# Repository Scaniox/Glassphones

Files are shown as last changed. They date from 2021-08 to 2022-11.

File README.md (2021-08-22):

# Glassphones

A Bluetooth headset but built into glasses frames; this is V1, so is a bulky experiment

MCU is an esp32 (tinypico nano), programmed using espidf 4.3

codec is a Maxim9850eti+, which is sent audio over i2s and control signals over i2c.
on the same i2s bus (sharing BCLK and LRCLK) is an ics43432 MEMS microphone

audio drivers are tiny bone conduction speakers.

micro SD card using 4 bit SD bus used for secondary storage

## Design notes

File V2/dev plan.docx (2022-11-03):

- hardware
  - Breadboard prototype
    - ~~Uart interface~~
    - Slider input
    - ~~Sd output~~
    - Audio mux
    - Battery
    - Light
    - Indicator disp
    - Test software
      - Sd playing
      - Basic BT playing
      - Audio mixing
      - Slider test
      - Basic slider control
  - Mechanical design
    - Enclosure design
    - Transducer positioning
    - pcb outline
  - Schematic design
  - Pcb layout
    - Layout
    - Routing
    - check
- Software
  - Slider input
  - Menu system
    - Menus
    - Flow diagram
    - User output
  - Sd playing
    - Long file names
  - Bluetooth playing

PCB issues:

- USB D+ and D- swapped; incorrect schematic symbol
- Bm83 VBUS bypass cap not routed
- Cap touch mpr121 vreg capacitor can’t be 0.1uf or only max 4 elements can run at 1ms sample period or 9 at 128ms; all 12 work with 1uf at 16ms, but not 1ms

Hardware abstraction layer (drivers):

- RGB LED driver
  - setup
  - Power management- auto power off
  - Colour patterns
- TOUCH driver
  - Setup - calibration
  - Drift compensation
  - Conversion to slider
  - Power
- Power LED driver
  - Thermal sensing
  - Output - PWM
- VS1053B driver
  - SD IO
  - VS1053 config
  - Power management
  - Audio playing
- BM83 driver
  - Initialisation
  - Events
  - Controls
- System / Misc
  - Battery monitoring
  - Debug LED
  - USB status / Serial

UI system:

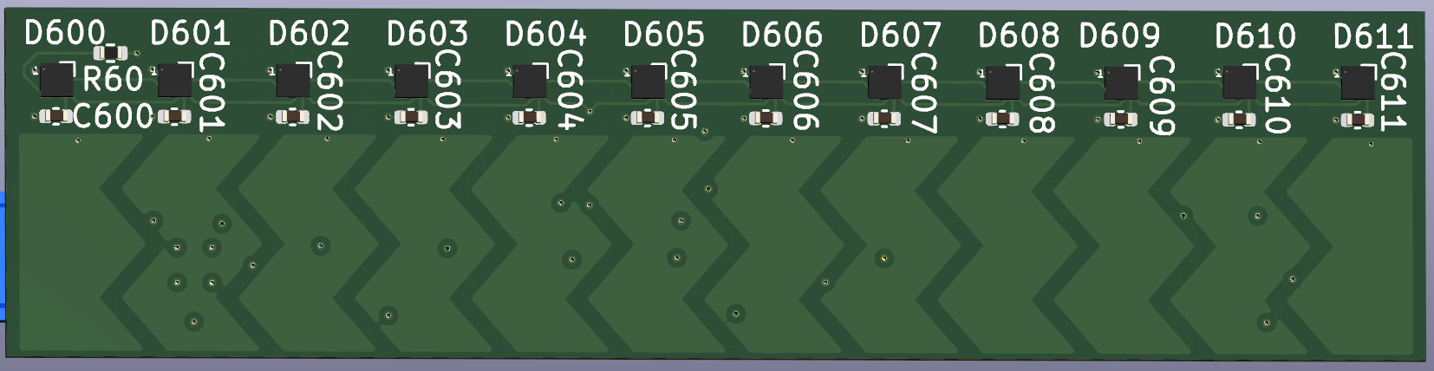
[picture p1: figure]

0 | 1 | 2 | 3 | 4 | 5 | 6 | 7 | 8 | 9 | 10 | 11

Input layers:

Switch between which input events are processed

- Buttons layer:
  - Button:
    - Singular element/ position range triggered
    - Boolean state event
  - Combo buttons:
    - Set pattern of element/ position ranges detected
    - Boolean state event
- Scroll layer:
  - Single scroll
    - One or more digits slides along the sensor.
    - Velocity based – based on touch point velocity not absolute position to prevent jumping between values
    - Value event for delta since [last event, or initial value]

Control scheme:

- Back button on element 0
- Quick access menu
  - Pause
  - Play
  - Seek
  - Volume
- Light shortcut

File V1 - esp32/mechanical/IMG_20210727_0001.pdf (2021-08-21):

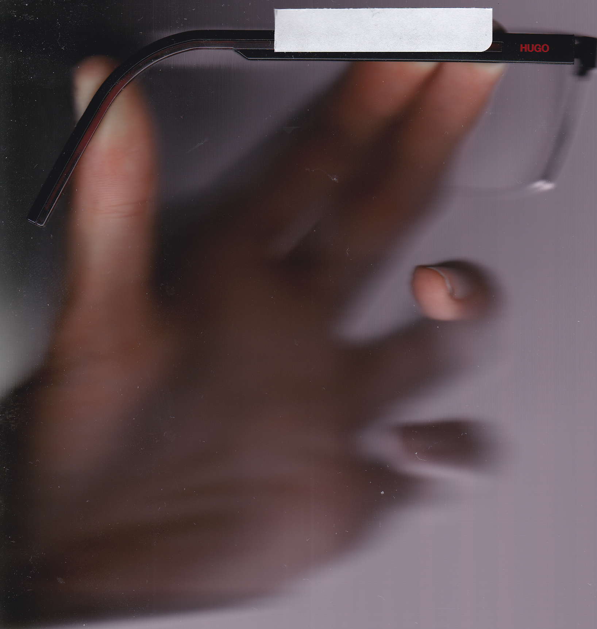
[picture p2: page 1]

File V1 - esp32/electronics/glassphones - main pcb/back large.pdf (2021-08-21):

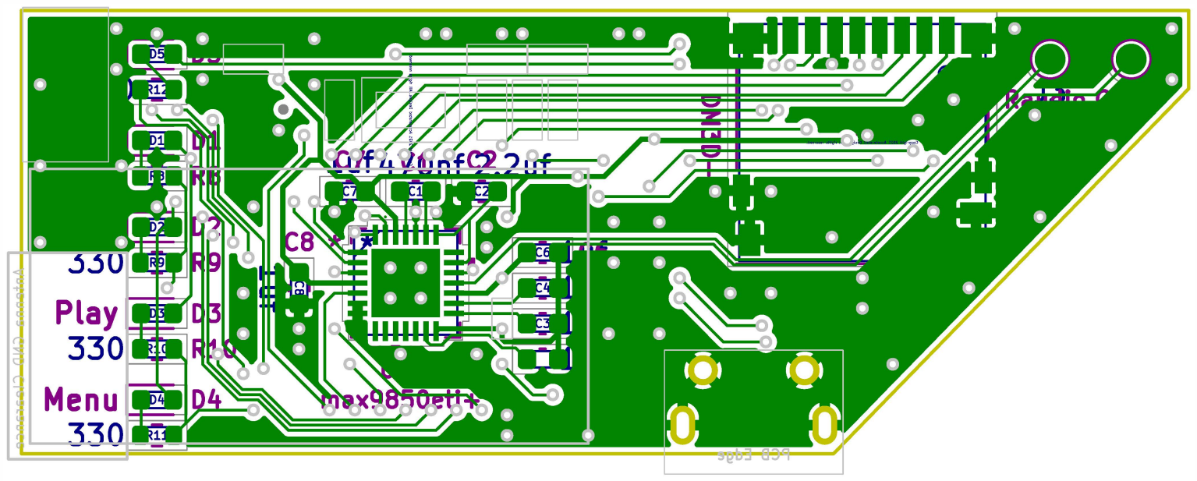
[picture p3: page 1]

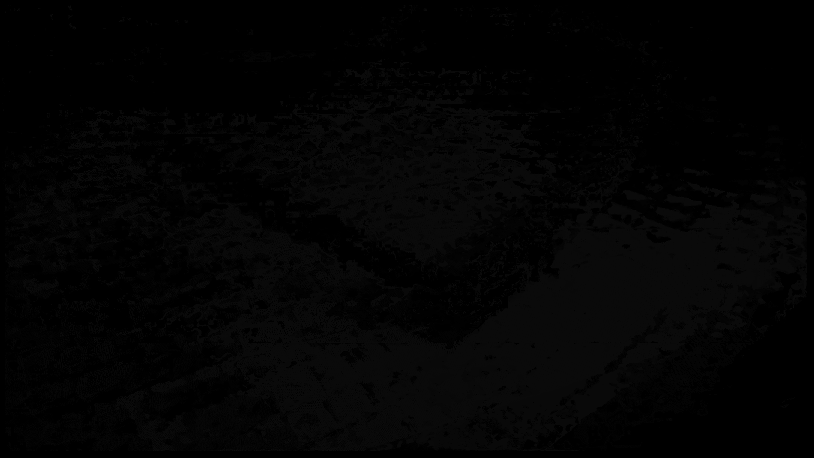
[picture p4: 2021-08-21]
V1 - esp32/mechanical/photogrammetry/photo/MeshroomCache/DepthMapFilter/24b79df3ac3274988167803b87b50ed05e469bb3/1338512535_nmodMap.png

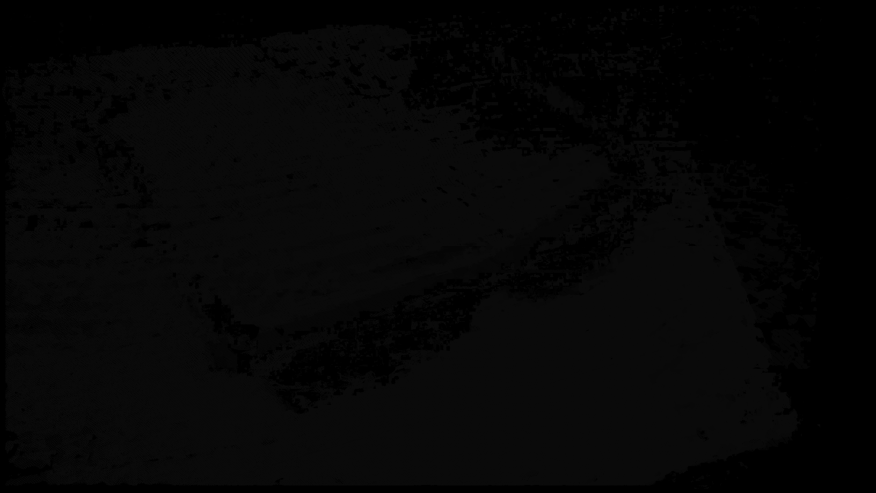
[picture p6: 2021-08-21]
V1 - esp32/mechanical/photogrammetry/photo/MeshroomCache/DepthMapFilter/24b79df3ac3274988167803b87b50ed05e469bb3/1295243340_nmodMap.png

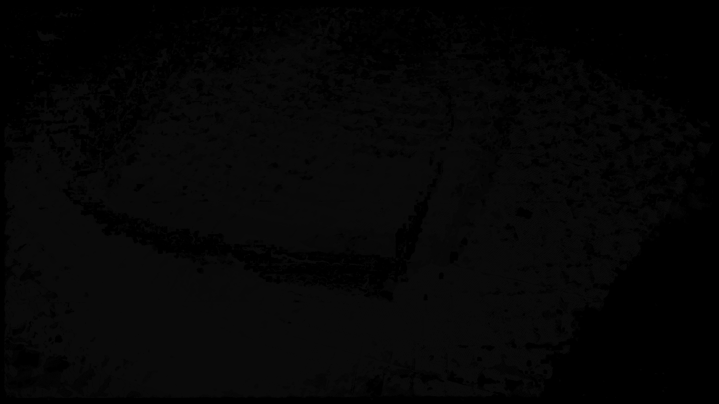
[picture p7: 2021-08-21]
V1 - esp32/mechanical/photogrammetry/photo/MeshroomCache/DepthMapFilter/24b79df3ac3274988167803b87b50ed05e469bb3/1249290596_nmodMap.png

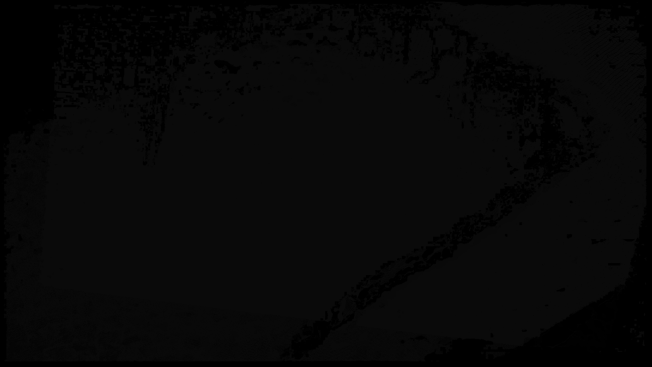
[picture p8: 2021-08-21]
V1 - esp32/mechanical/photogrammetry/photo/MeshroomCache/DepthMapFilter/24b79df3ac3274988167803b87b50ed05e469bb3/1560870966_nmodMap.png

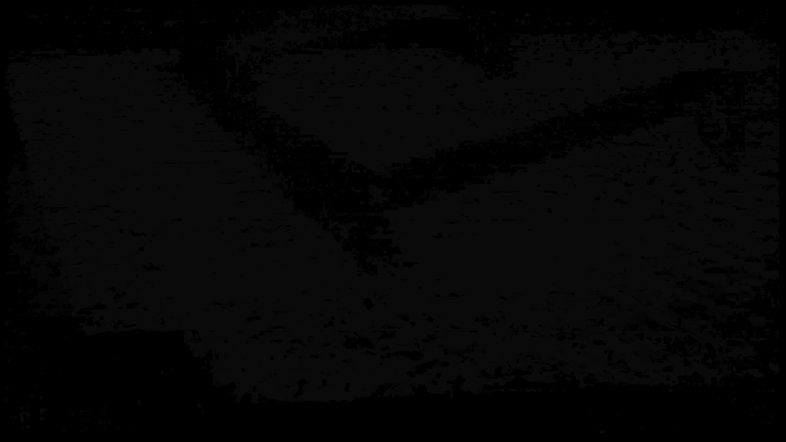
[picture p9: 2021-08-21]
V1 - esp32/mechanical/photogrammetry/photo/MeshroomCache/DepthMapFilter/24b79df3ac3274988167803b87b50ed05e469bb3/498073649_nmodMap.png

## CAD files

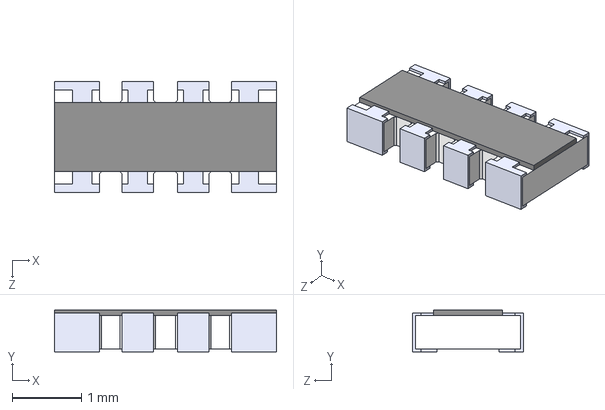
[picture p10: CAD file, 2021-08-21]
V1 - esp32/electronics/glassphones - main pcb/components/4X10k resistor array ul_EXB38V103JV/EXB-38V103JV.step
3.20 x 0.6 x 1.60 mm

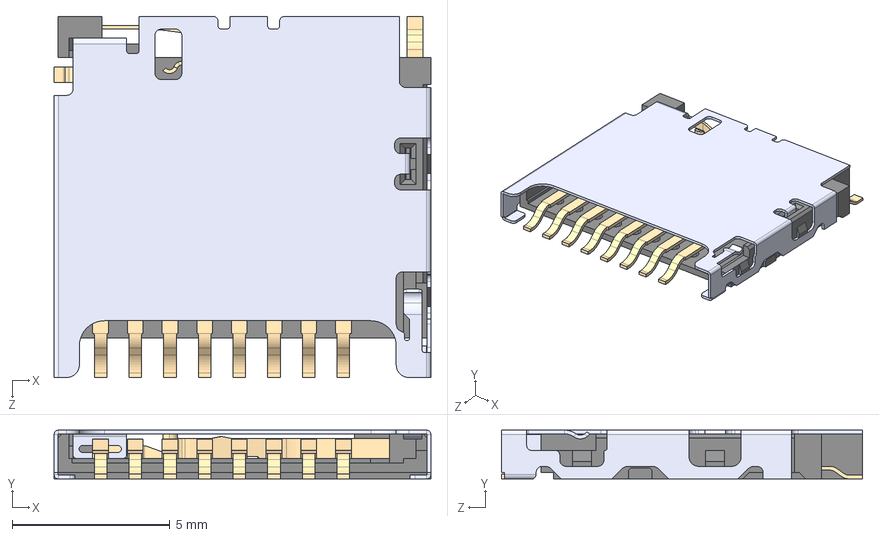
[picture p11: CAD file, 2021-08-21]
V1 - esp32/electronics/glassphones - main pcb/components/DM3DS SD card slot/DM3D-SF--3DModel-STEP-56544.step
12.0 x 1.55 x 11.5 mm

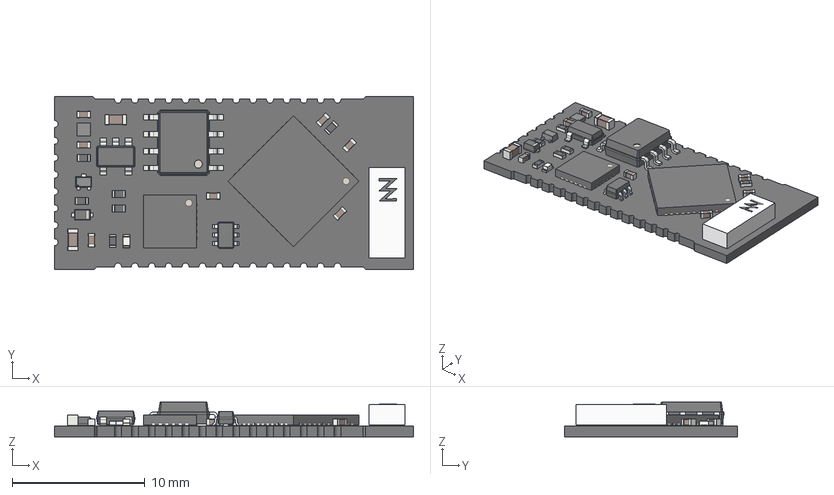
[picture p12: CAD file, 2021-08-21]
V1 - esp32/electronics/glassphones - main pcb/components/esp32 - tinypico/3D Files/TinyPICO Nano.step
27.0 x 13.0 x 2.60 mm

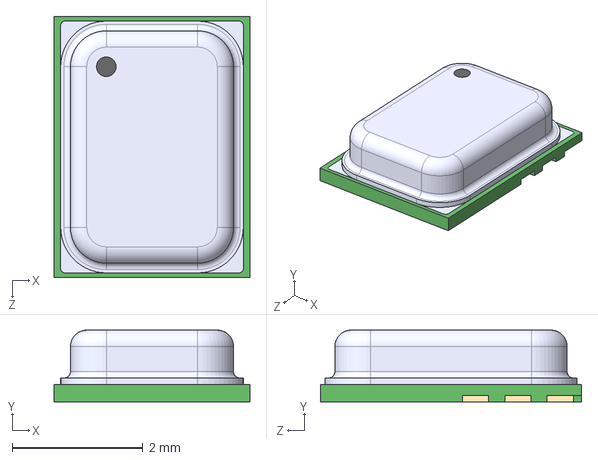
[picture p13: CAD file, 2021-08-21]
V1 - esp32/electronics/glassphones - main pcb/components/ICS 43432 I2S microphone/ICS-43432--3DModel-STEP-56544.step
3.00 x 1.10 x 4.00 mm

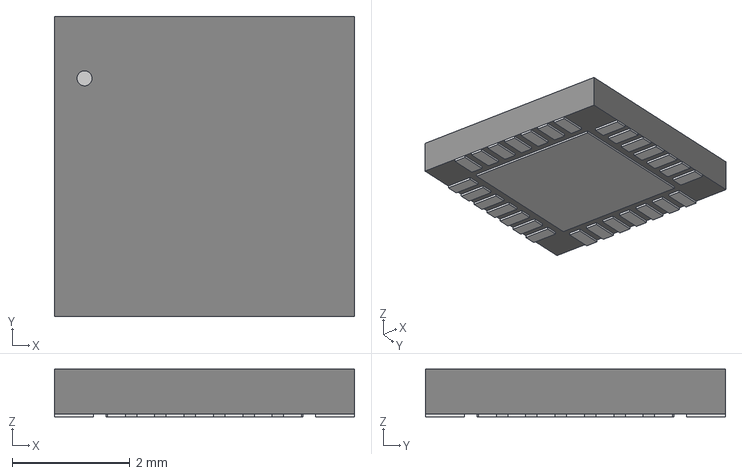
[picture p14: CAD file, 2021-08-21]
V1 - esp32/electronics/glassphones - main pcb/components/MAX9850/21-0140_T28556_MXM.step
5.11 x 5.11 x 0.815 mm

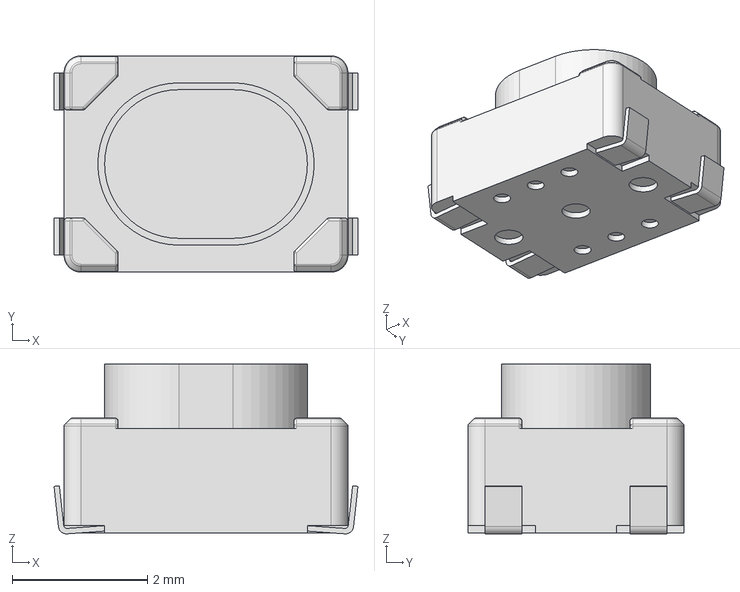
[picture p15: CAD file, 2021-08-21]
V1 - esp32/electronics/glassphones - main pcb/components/TL3365 button/TL3365AF180QG.stp
4.50 x 3.20 x 2.51 mm

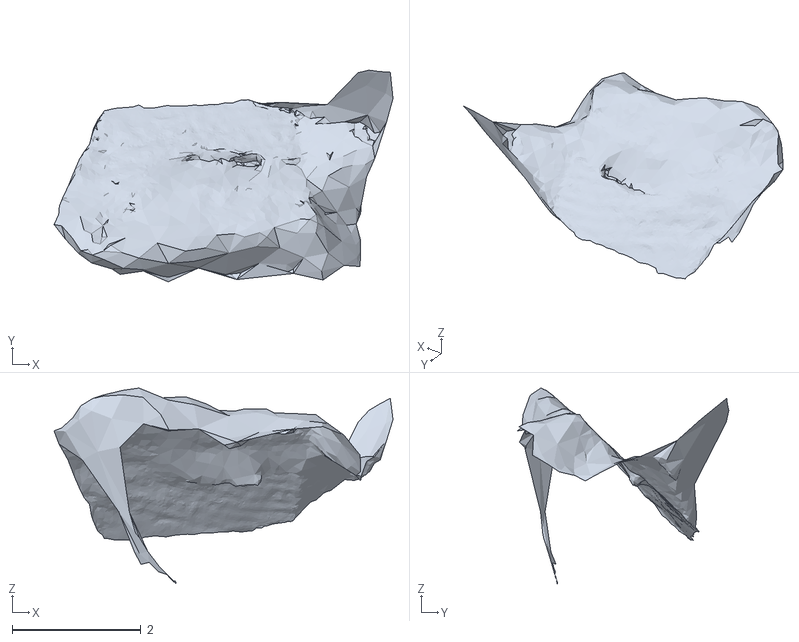
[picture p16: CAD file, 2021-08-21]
V1 - esp32/mechanical/photogrammetry/video/MeshroomCache/MeshFiltering/824bb1fc97e66b3d18760ff6004b31c06b283055/mesh.obj
5.26 x 3.28 x 3.04

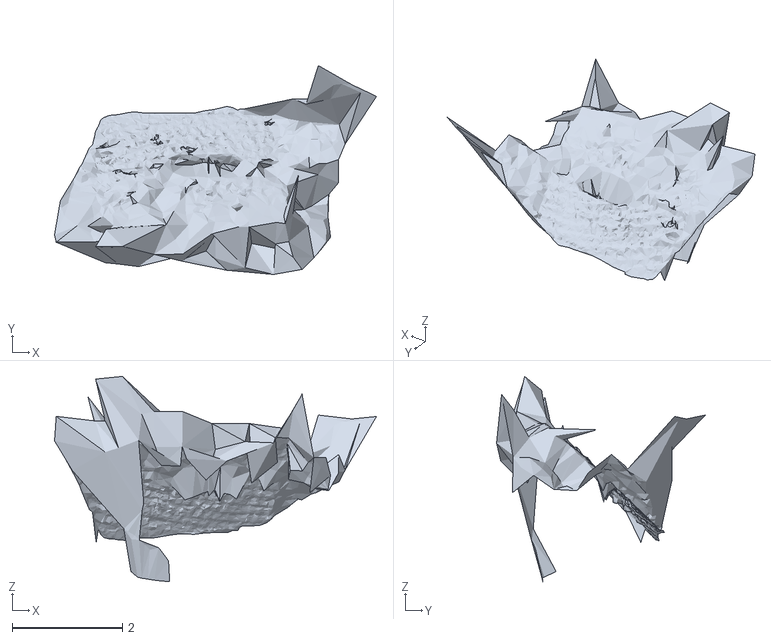
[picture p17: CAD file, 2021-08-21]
V1 - esp32/mechanical/photogrammetry/video/MeshroomCache/Meshing/db83591ce1e8f06cfc1e3cb798bf2ff74a9c68ce/mesh.obj
5.84 x 3.79 x 3.72

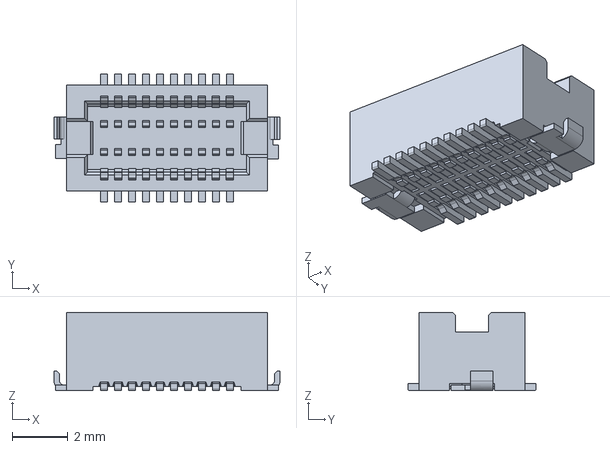
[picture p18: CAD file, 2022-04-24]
V2/electronics/components/df12Nx-20 connector/DF12NB-3.5--20DP-0.5V-51---3DModel-STEP-1.step
8.10 x 4.60 x 2.80 mm

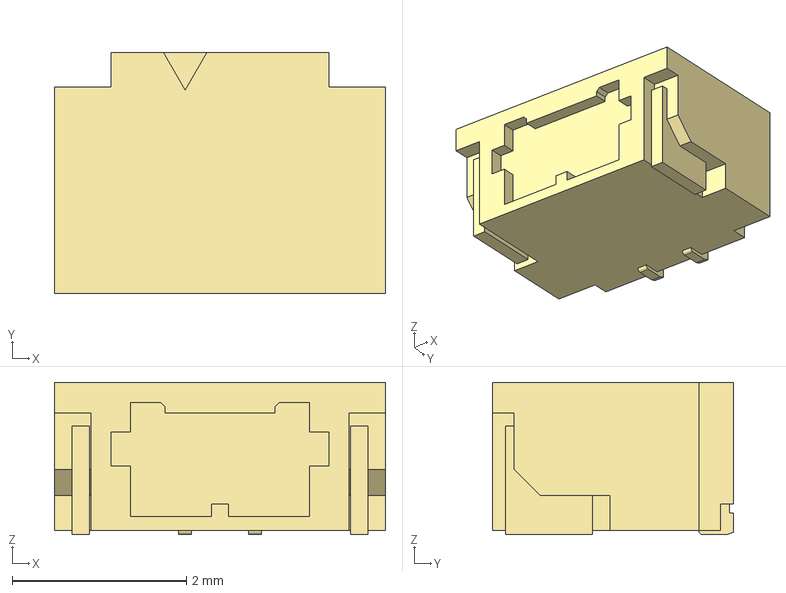
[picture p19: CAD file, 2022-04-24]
V2/electronics/components/df52 conn/DF52-2S-0.8H.stp
3.80 x 2.77 x 1.75 mm

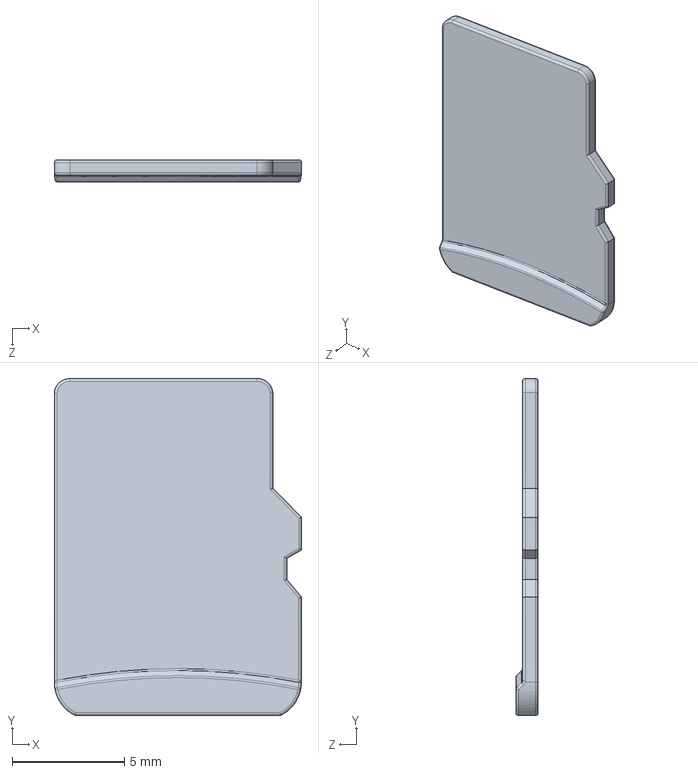
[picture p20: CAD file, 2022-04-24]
V2/electronics/components/Micro SD Card.STEP
11.0 x 15.0 x 1.00 mm

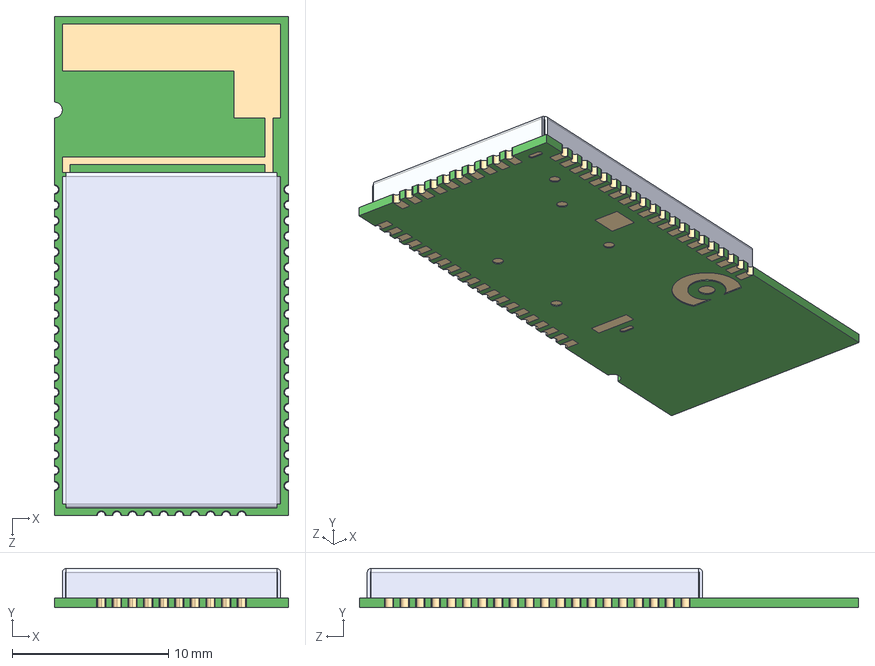
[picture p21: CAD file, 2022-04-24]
V2/electronics/components/Microchip BM83/BM83SM1-00AA--3DModel-STEP-1.step
15.0 x 2.50 x 32.0 mm

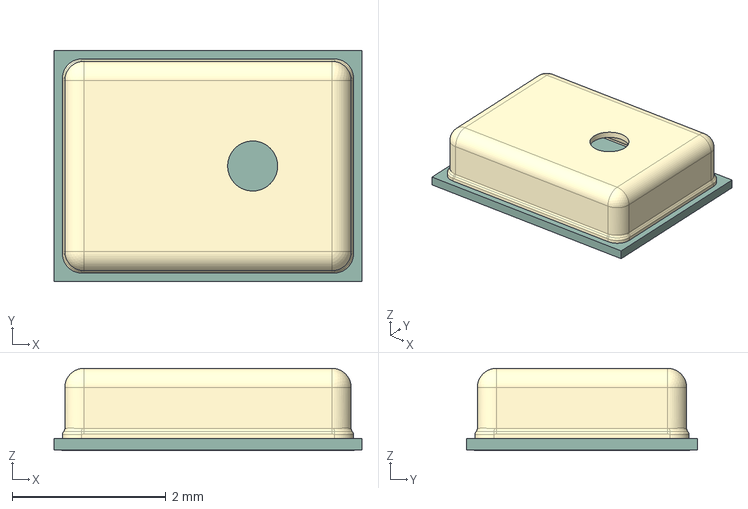
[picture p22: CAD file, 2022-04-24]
V2/electronics/components/MP34DT01TR-M PDM microphone/MP34DT01-M pdm mic v1.step
4.00 x 3.00 x 1.07 mm

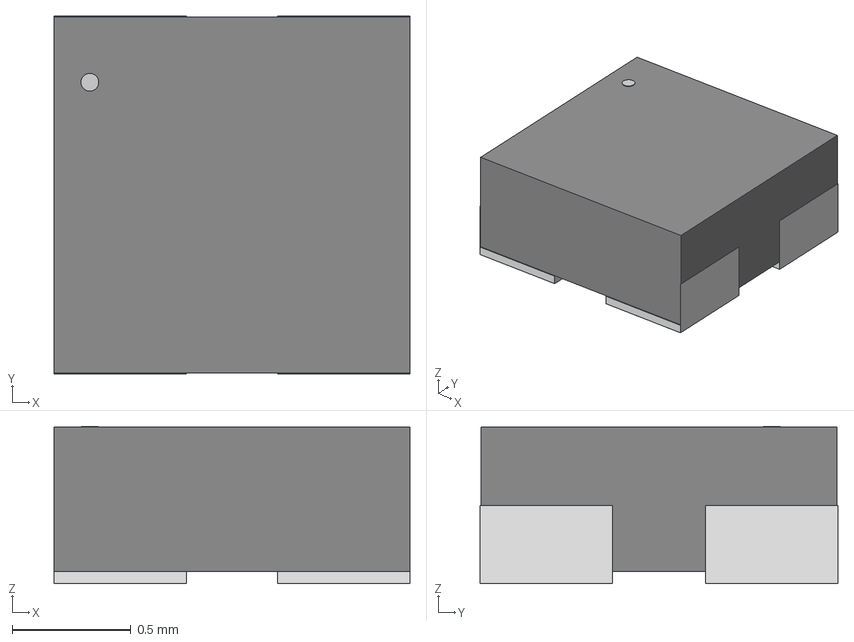
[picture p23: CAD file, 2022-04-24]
V2/electronics/components/sk6805 RGB LED/4492_ADA.step
1.50 x 1.51 x 0.663 mm

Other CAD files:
V2/electronics/main/main.3mf
V1 - esp32/mechanical/photogrammetry/video/MeshroomCache/Texturing/2c468ecf00575808510a90f24e992894a4d70658/texturedMesh.obj
V1 - esp32/electronics/glassphones - main pcb/components/1050170001--3DModel-STEP-56544.step
V1 - esp32/electronics/glassphones - main pcb/components/esp32 - tinypico/3D Files/TinyPICO Nano.stl
V2/electronics/components/0.65mm pogo pin v0.step
V2/electronics/components/df12Nx-20 connector/DF12NC-20DS-0.5V-51---3DModel-STEP-1.step
V2/electronics/components/df52 conn/DF52-4S-0.8H.stp
V2/electronics/components/df52 conn/DF52-5P-0.8C--3DModel-STEP-1.step
V2/electronics/components/df52 conn/DF52-5S-0.8H.stp
V2/electronics/components/ul_max9725aetc-/KiCAD/2022-04-11_15-45-50/MAX9725AETC+.step
V2/mechanical/power-led-1.snapshot.1/Power Led.CATPart
V2/mechanical/power-led-1.snapshot.1/Power Led.igs
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

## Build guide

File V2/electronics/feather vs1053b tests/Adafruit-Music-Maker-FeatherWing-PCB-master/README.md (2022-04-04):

## Adafruit Music Maker FeatherWing PCB

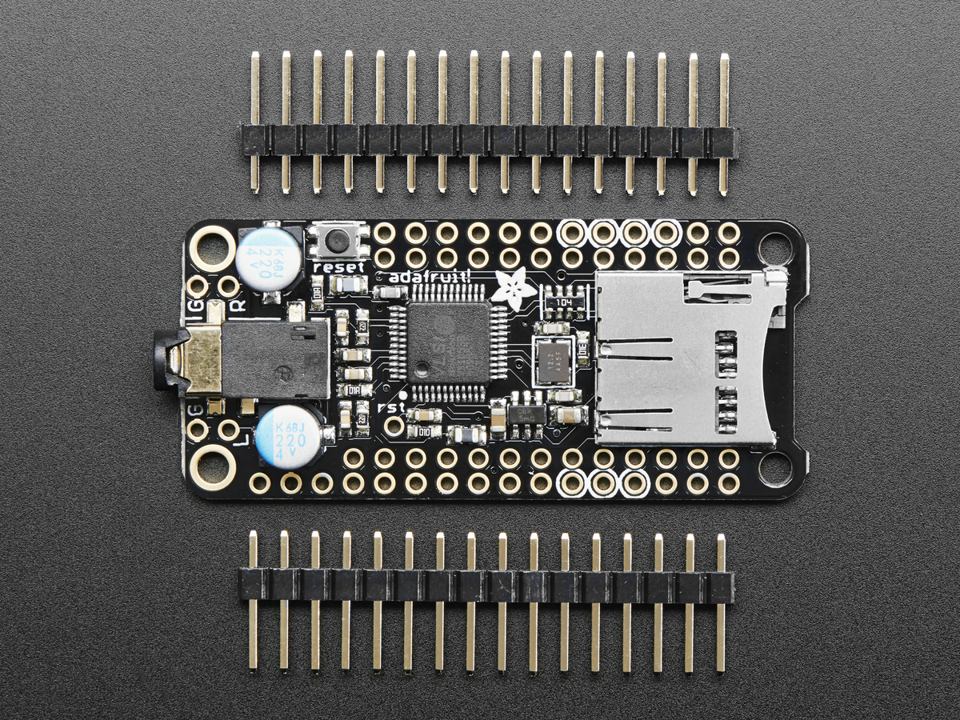
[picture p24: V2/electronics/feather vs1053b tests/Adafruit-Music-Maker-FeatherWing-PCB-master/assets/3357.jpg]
<a href="http://www.adafruit.com/products/3357">&nbsp; 
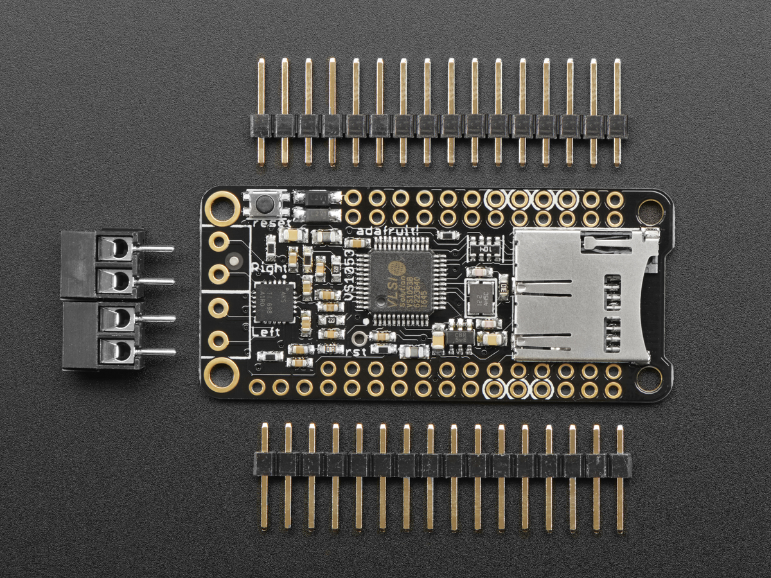
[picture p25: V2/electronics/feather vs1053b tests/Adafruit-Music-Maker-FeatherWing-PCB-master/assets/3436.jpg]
<a href="http://www.adafruit.com/products/3436"><br/>
Click a picture to purchase from the Adafruit shop</a>

PCB files for the Adafruit Music Maker FeatherWings. Format is EagleCAD schematic and board layout

For more details, check out the product pages at
  * Music Maker FeatherWing http://www.adafruit.com/products/3357
  * Music Maker FeatherWing with 3W amp http://www.adafruit.com/products/3436

### Description

Bend all audio files to your will with the Adafruit Music Maker FeatherWings! It's a fun-size version of our Music Maker shield for Arduino! This powerful wing features the VS1053, an encoding/decoding (codec) chip that can decode a wide variety of audio formats such as MP3, AAC, Ogg Vorbis, WMA, MIDI, FLAC, WAV (PCM and ADPCM). You can do all sorts of stuff with the audio as well such as adjusting bass, treble, and volume digitally.

All this functionality is implemented in a light-weight SPI interface so that any Feather Board can play audio from an SD card. There's also a special MIDI mode that you can boot the chip into that will read 'classic' 31250Kbaud MIDI data from the UART TX pin and act like a synth/drum machine - there are dozens of built-in drum and sample effects!

What a great musical add-on to your Feather! That's why we spun up this super FeatherWing, perfect for use with any of our Feather Boards! Music playback testing working with ATmega32u4, ATSAMD M0, ESP8266, WICED Teensy 3, and nRF52 Feathers. MIDI playback works with all Feathers but you may need to remove the 'Wing during programming and also for USB-Serial Feathers like the ESP8266 and nRF52 you'll end up re-using the main Serial console for MIDI which can be confusing.

### License

Adafruit invests time and resources providing this open source design, please support Adafruit and open-source hardware by purchasing products from [Adafruit](https://www.adafruit.com)!

Designed by Limor Fried/Ladyada for Adafruit Industries.

Creative Commons Attribution/Share-Alike, all text above must be included in any redistribution. See license.txt for additional details.

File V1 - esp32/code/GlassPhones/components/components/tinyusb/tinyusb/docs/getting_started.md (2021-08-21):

# Getting Started #

## Add TinyUSB to your project

It is relatively simple to incorporate tinyusb to your (existing) project

- Copy or `git submodule` this repo into your project in a subfolder. Let's say it is *your_project/tinyusb*
- Add all the .c in the `tinyusb/src` folder to your project
- Add *your_project/tinyusb/src* to your include path. Also make sure your current include path also contains the configuration file tusb_config.h.
- Make sure all required macros are all defined properly in tusb_config.h (configure file in demo application is sufficient, but you need to add a few more such as CFG_TUSB_MCU, CFG_TUSB_OS since they are passed by IDE/compiler to maintain a unique configure for all boards).
- If you use the device stack, make sure you have created/modified usb descriptors for your own need. Ultimately you need to implement all **tud_descriptor_** callbacks for the stack to work.
- Add tusb_init() call to your reset initialization code.
- Call `tud_int_handler()` (device stack) and/or `tuh_int_handler()` in your USB IRQ Handler
- Implement all enabled classes's callbacks.
- If you don't use any RTOSes at all, you need to continuously and/or periodically call tud_task()/tuh_task() function. All of the callbacks and functionality are handled and invoke within the call of that task runner.

~~~{.c}
int main(void)
{
  your_init_code();
  tusb_init(); // initialize tinyusb stack

  while(1) // the mainloop
  {
    your_application_code();

    tud_task(); // device task
    tuh_task(); // host task
  }
}
~~~

## Examples

For your convenience, TinyUSB contains a handful of examples for both host and device with/without RTOS to quickly test the functionality as well as demonstrate how API() should be used. Most examples will work on most of [the supported Boards](boards.md). Firstly we need to `git clone` if not already

```
$ git clone https://github.com/hathach/tinyusb tinyusb
$ cd tinyusb
```

TinyUSB examples includes external repos aka submodules to provide low-level MCU peripheral's driver as well as external libraries such as FreeRTOS to compile with. Therefore we will firstly fetch those mcu driver repo by running this command in the top folder repo

```
$ git submodule update --init --recursive
```

It will takes a bit of time due to the number of supported MCUs, luckily we only need to do this once. Or if you only want to test with a specific mcu, you could only fetch its driver submodule.

### Build

To build example, first change directory to an example folder. 

```
$ cd examples/device/cdc_msc
```

Then compile with `make BOARD=[board_name] all`, for example

```
$ make BOARD=feather_nrf52840_express all
```

#### Port Selection

If a board has several ports, one port is chosen by default in the individual board.mk file. Use option `PORT=x` To choose another port. For example to select the HS port of a STM32F746Disco board, use:

```
$ make BOARD=stm32f746disco PORT=1 all
```

#### Port Speed

A MCU can support multiple operational speed. By default, the example build system will use the fastest supported on the board. Use option `SPEED=full/high` e.g To force F723 operate at full instead of default high speed

```
$ make BOARD=stm32f746disco SPEED=full all
```

### Debug

To compile for debugging add `DEBUG=1`, for example

```
$ make BOARD=feather_nrf52840_express DEBUG=1 all
```

#### Log

Should you have an issue running example and/or submitting an bug report. You could enable TinyUSB built-in debug logging with optional `LOG=`. LOG=1 will only print out error message, LOG=2 print more information with on-going events. LOG=3 or higher is not used yet. 

```
$ make BOARD=feather_nrf52840_express LOG=2 all
```

#### Logger

By default log message is printed via on-board UART which is slow and take lots of CPU time comparing to USB speed. If your board support on-board/external debugger, it would be more efficient to use it for logging. There are 2 protocols: 

- `LOGGER=rtt`: use [Segger RTT protocol](https://www.segger.com/products/debug-probes/j-link/technology/about-real-time-transfer/)   
  - Cons: requires jlink as the debugger.
  - Pros: work with most if not all MCUs
  - Software viewer is JLink RTT Viewer/Client/Logger which is bundled with JLink driver package.
- `LOGGER=swo`: Use dedicated SWO pin of ARM Cortex SWD debug header.
  - Cons: only work with ARM Cortex MCUs minus M0
  - Pros: should be compatible with more debugger that support SWO.
  - Software viewer should be provided along with your debugger driver.

```
$ make BOARD=feather_nrf52840_express LOG=2 LOGGER=rtt all
$ make BOARD=feather_nrf52840_express LOG=2 LOGGER=swo all
```

### Flash

`flash` target will use the default on-board debugger (jlink/cmsisdap/stlink/dfu) to flash the binary, please install those support software in advance. Some board use bootloader/DFU via serial which is required to pass to make command

```
$ make BOARD=feather_nrf52840_express flash
$ make SERIAL=/dev/ttyACM0 BOARD=feather_nrf52840_express flash
```

Since jlink can be used with most of the boards, there is also `flash-jlink` target for your convenience.

```
$ make BOARD=feather_nrf52840_express flash-jlink
```

Some board use uf2 bootloader for drag & drop in to mass storage device, uf2 can be generated with `uf2` target

```
$ make BOARD=feather_nrf52840_express all uf2
```

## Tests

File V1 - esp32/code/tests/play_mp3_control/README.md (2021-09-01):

# Play mp3 file with playback control

- [中文版本](./README_CN.md)
- Basic Example: Basic Example

## Example Brief

This example uses MP3 element and I2S element to play embedded MP3 music. The mp3 element call back function `read_cb` read the music data form flash, decode the data then use I2S element output the music.

This example also shows how to control MP3 playback by buttons.

- Playback: start, stop, pause, resume.
- Volume: volume up, volume down.
- Other button: MODE/FUNC button, which is used to switch between audios played at different sample rates.

The three audio files at the sample rate of 8000 Hz, 22050 Hz, and 44100 Hz are embedded in flash.

## Environment Setup

### Hardware Required

This example runs on the boards that are marked with a green checkbox in the table below. Please remember to select the board in menuconfig as discussed in Section *Configuration* below.

| Board Name | Getting Started | Chip | Compatible |
|---|:---:|:---:|:---:|
| ESP32-LyraT | ESP32-LyraT (https://docs.espressif.com/projects/esp-adf/en/latest/get-started/get-started-esp32-lyrat.html) | ESP32 | Compatible |
| ESP32-LyraTD-MSC | ESP32-LyraTD-MSC (https://docs.espressif.com/projects/esp-adf/en/latest/get-started/get-started-esp32-lyratd-msc.html) | ESP32 | Compatible |
| ESP32-LyraT-Mini | ESP32-LyraT-Mini (https://docs.espressif.com/projects/esp-adf/en/latest/get-started/get-started-esp32-lyrat-mini.html) | ESP32 | Compatible |
| ESP32-Korvo-DU1906 | ESP32-Korvo-DU1906 (https://docs.espressif.com/projects/esp-adf/en/latest/get-started/get-started-esp32-korvo-du1906.html) | ESP32 | Compatible |
| ESP32-S2-Kaluga-1 Kit | ESP32-S2-Kaluga-1 Kit (https://docs.espressif.com/projects/esp-idf/en/latest/esp32s2/hw-reference/esp32s2/user-guide-esp32-s2-kaluga-1-kit.html) | ESP32-S2 | Compatible |

## Example Set Up

### Default IDF Branch
The default IDF branch of this example is ADF's built-in branch `$ADF_PATH/esp-idf`.

### Configuration
The default board for this example is `ESP32-Lyrat V4.3`, if you need to run this example on other development boards, you need to select the configuration of the development board in menuconfig, for example, select `ESP32-Lyrat-Mini V1.1`.

```c
menuconfig > Audio HAL > ESP32-Lyrat-Mini V1.1
```

### Build and Flash
Build the project and flash it to the board, then run monitor tool to view serial output (replace `PORT` with your board's serial port name):

```c
idf.py -p PORT flash monitor
```

To exit the serial monitor, type ``Ctrl-]``.

See the Getting Started Guide for full steps to configure and use  [ESP-IDF Programming Guide](https://docs.espressif.com/projects/esp-idf/en/release-v4.2/esp32/index.html) to build projects.

## How to use the Example

### Example Functionality

- After the routine starts to run, it will automatically play the low sample rate (8000 Hz) mp3 file.

```c
I (260) PLAY_FLASH_MP3_CONTROL: [3.1] Initialize keys on board
I (260) PLAY_FLASH_MP3_CONTROL: [ 4 ] Set up  event listener
W (280) PERIPH_TOUCH: _touch_init
I (280) PLAY_FLASH_MP3_CONTROL: [4.1] Listening event from all elements of pipeline
I (290) PLAY_FLASH_MP3_CONTROL: [4.2] Listening event from peripherals
W (290) PLAY_FLASH_MP3_CONTROL: [ 5 ] Tap touch buttons to control music player:
W (300) PLAY_FLASH_MP3_CONTROL:       [Play] to start, pause and resume, [Set] to stop.
W (310) PLAY_FLASH_MP3_CONTROL:       [Vol-] or [Vol+] to adjust volume.
I (330) PLAY_FLASH_MP3_CONTROL: [ 5.1 ] Start audio_pipeline
I (340) PLAY_FLASH_MP3_CONTROL: [ * ] Receive music info from mp3 decoder, sample_rates=8000, bits=16, ch=2
```
- During playback, you can use the [Play] button to pause playback and resume playback.

```c
I (330) PLAY_FLASH_MP3_CONTROL: [ 5.1 ] Start audio_pipeline
I (340) PLAY_FLASH_MP3_CONTROL: [ * ] Receive music info from mp3 decoder, sample_rates=8000, bits=16, ch=2
I (7330) PLAY_FLASH_MP3_CONTROL: [ * ] [Play] touch tap event
I (7330) PLAY_FLASH_MP3_CONTROL: [ * ] Pausing audio pipeline
I (8830) PLAY_FLASH_MP3_CONTROL: [ * ] [Play] touch tap event
I (8830) PLAY_FLASH_MP3_CONTROL: [ * ] Resuming audio pipeline
I (8850) PLAY_FLASH_MP3_CONTROL: [ * ] Receive music info from mp3 decoder, sample_rates=8000, bits=16, ch=2
```

- Use volume down key [Vol-] to decrease the volume, and volume up key [Vol+] to increase the volume.

```c
I (81590) PLAY_FLASH_MP3_CONTROL: [ * ] Receive music info from mp3 decoder, sample_rates=22050, bits=16, ch=2
I (106330) PLAY_FLASH_MP3_CONTROL: [ * ] [Vol+] touch tap event
I (106340) PLAY_FLASH_MP3_CONTROL: [ * ] Volume set to 79 %
```

- Use [Mode] key to switch MP3 playback of different audio file (8000 Hz, 22050 Hz, 44100 Hz).

```c
I (330) PLAY_FLASH_MP3_CONTROL: [ 5.1 ] Start audio_pipeline
I (340) PLAY_FLASH_MP3_CONTROL: [ * ] Receive music info from mp3 decoder, sample_rates=8000, bits=16, ch=2
I (16230) PLAY_FLASH_MP3_CONTROL: [ * ] [mode] tap event
W (16230) AUDIO_ELEMENT: OUT-[mp3] AEL_IO_ABORT
W (16230) MP3_DECODER: output aborted -3
I (16420) PLAY_FLASH_MP3_CONTROL: [ * ] Receive music info from mp3 decoder, sample_rates=22050, bits=16, ch=2
I (19130) PLAY_FLASH_MP3_CONTROL: [ * ] [mode] tap event
W (19130) AUDIO_ELEMENT: OUT-[mp3] AEL_IO_ABORT
W (19130) MP3_DECODER: output aborted -3
I (19190) PLAY_FLASH_MP3_CONTROL: [ * ] Receive music info from mp3 decoder, sample_rates=44100, bits=16, ch=2
I (21440) PLAY_FLASH_MP3_CONTROL: [ * ] [mode] tap event
W (21440) AUDIO_ELEMENT: OUT-[mp3] AEL_IO_ABORT
W (21440) MP3_DECODER: output aborted -3
I (21480) PLAY_FLASH_MP3_CONTROL: [ * ] Receive music info from mp3 decoder, sample_rates=8000, bits=16, ch=2
```

- Use the [Set] key to exit the routine.

```c
I (21480) PLAY_FLASH_MP3_CONTROL: [ * ] Receive music info from mp3 decoder, sample_rates=8000, bits=16, ch=2
I (63580) PLAY_FLASH_MP3_CONTROL: [ * ] [Set] touch tap event
I (63580) PLAY_FLASH_MP3_CONTROL: [ * ] Stopping audio pipeline
I (63580) PLAY_FLASH_MP3_CONTROL: [ 6 ] Stop audio_pipeline
E (63580) AUDIO_ELEMENT: [mp3] Element already stopped
E (63600) AUDIO_ELEMENT: [i2s] Element already stopped
W (63600) AUDIO_PIPELINE: There are no listener registered
W (63600) AUDIO_ELEMENT: [i2s] Element has not create when AUDIO_ELEMENT_TERMINATE
W (63610) AUDIO_ELEMENT: [mp3] Element has not create when AUDIO_ELEMENT_TERMINATE
```

### Example Logs
A complete log is as follows:

```c
rst:0x1 (POWERON_RESET),boot:0x1f (SPI_FAST_FLASH_BOOT)
configsip: 0, SPIWP:0xee
clk_drv:0x00,q_drv:0x00,d_drv:0x00,cs0_drv:0x00,hd_drv:0x00,wp_drv:0x00
mode:DIO, clock div:2
load:0x3fff0018,len:4
load:0x3fff001c,len:6840
load:0x40078000,len:12072
load:0x40080400,len:6708
entry 0x40080778
I (73) boot: Chip Revision: 3
I (73) boot_comm: chip revision: 3, min. bootloader chip revision: 0
I (40) boot: ESP-IDF v3.3.2-107-g722043f73 2nd stage bootloader
I (40) boot: compile time 15:30:10
I (40) boot: Enabling RNG early entropy source...
I (46) boot: SPI Speed      : 40MHz
I (50) boot: SPI Mode       : DIO
I (54) boot: SPI Flash Size : 8MB
I (58) boot: Partition Table:
I (62) boot: ## Label            Usage          Type ST Offset   Length
I (69) boot:  0 nvs              WiFi data        01 02 00009000 00006000
I (76) boot:  1 phy_init         RF data          01 01 0000f000 00001000
I (84) boot:  2 factory          factory app      00 00 00010000 00100000
I (91) boot: End of partition table
I (95) boot_comm: chip revision: 3, min. application chip revision: 0
I (103) esp_image: segment 0: paddr=0x00010020 vaddr=0x3f400020 size=0x8a0d0 (565456) map
I (310) esp_image: segment 1: paddr=0x0009a0f8 vaddr=0x3ffb0000 size=0x01f40 (  8000) load
I (314) esp_image: segment 2: paddr=0x0009c040 vaddr=0x40080000 size=0x00400 (  1024) load
0x40080000: _WindowOverflow4 at /repo/adfs/bugfix/esp-adf-internal/esp-idf/components/freertos/xtensa_vectors.S:1779

I (317) esp_image: segment 3: paddr=0x0009c448 vaddr=0x40080400 size=0x03bc8 ( 15304) load
I (332) esp_image: segment 4: paddr=0x000a0018 vaddr=0x400d0018 size=0x26a64 (158308) map
0x400d0018: _flash_cache_start at ??:?

I (390) esp_image: segment 5: paddr=0x000c6a84 vaddr=0x40083fc8 size=0x06994 ( 27028) load
0x40083fc8: i2c_master_cmd_begin_static at /repo/adfs/bugfix/esp-adf-internal/esp-idf/components/driver/i2c.c:1134

I (408) boot: Loaded app from partition at offset 0x10000
I (408) boot: Disabling RNG early entropy source...
I (409) cpu_start: Pro cpu up.
I (412) cpu_start: Application information:
I (417) cpu_start: Project name:     play_mp3_control
I (423) cpu_start: App version:      v2.2-85-gf9fa5c94-dirty
I (429) cpu_start: Compile time:     Apr 27 2021 17:11:15
I (435) cpu_start: ELF file SHA256:  87bfd7bdac8a9d70...
I (441) cpu_start: ESP-IDF:          v3.3.2-107-g722043f73
I (447) cpu_start: Starting app cpu, entry point is 0x40081078
0x40081078: call_start_cpu1 at /repo/adfs/bugfix/esp-adf-internal/esp-idf/components/esp32/cpu_start.c:268

I (0) cpu_start: App cpu up.
I (458) heap_init: Initializing. RAM available for dynamic allocation:
I (465) heap_init: At 3FFAE6E0 len 00001920 (6 KiB): DRAM
I (471) heap_init: At 3FFB2FE0 len 0002D020 (180 KiB): DRAM
I (477) heap_init: At 3FFE0440 len 00003AE0 (14 KiB): D/IRAM
I (483) heap_init: At 3FFE4350 len 0001BCB0 (111 KiB): D/IRAM
I (490) heap_init: At 4008A95C len 000156A4 (85 KiB): IRAM
I (496) cpu_start: Pro cpu start user code
I (179) cpu_start: Starting scheduler on PRO CPU.
I (0) cpu_start: Starting scheduler on APP CPU.
I (180) PLAY_FLASH_MP3_CONTROL: [ 1 ] Start audio codec chip
I (200) PLAY_FLASH_MP3_CONTROL: [ 2 ] Create audio pipeline, add all elements to pipeline, and subscribe pipeline event
I (200) PLAY_FLASH_MP3_CONTROL: [2.1] Create mp3 decoder to decode mp3 file and set custom read callback
I (220) PLAY_FLASH_MP3_CONTROL: [2.2] Create i2s stream to write data to codec chip
I (230) PLAY_FLASH_MP3_CONTROL: [2.3] Register all elements to audio pipeline
I (230) PLAY_FLASH_MP3_CONTROL: [2.4] Link it together [mp3_music_read_cb]-->mp3_decoder-->i2s_stream-->[codec_chip]
I (240) PLAY_FLASH_MP3_CONTROL: [ 3 ] Initialize peripherals
E (250) gpio: gpio_install_isr_service(412): GPIO isr service already installed
I (260) PLAY_FLASH_MP3_CONTROL: [3.1] Initialize keys on board
I (260) PLAY_FLASH_MP3_CONTROL: [ 4 ] Set up  event listener
W (280) PERIPH_TOUCH: _touch_init
I (280) PLAY_FLASH_MP3_CONTROL: [4.1] Listening event from all elements of pipeline
I (290) PLAY_FLASH_MP3_CONTROL: [4.2] Listening event from peripherals
W (290) PLAY_FLASH_MP3_CONTROL: [ 5 ] Tap touch buttons to control music player:
W (300) PLAY_FLASH_MP3_CONTROL:       [Play] to start, pause and resume, [Set] to stop.
W (310) PLAY_FLASH_MP3_CONTROL:       [Vol-] or [Vol+] to adjust volume.
I (330) PLAY_FLASH_MP3_CONTROL: [ 5.1 ] Start audio_pipeline
I (340) PLAY_FLASH_MP3_CONTROL: [ * ] Receive music info from mp3 decoder, sample_rates=8000, bits=16, ch=2
I (7330) PLAY_FLASH_MP3_CONTROL: [ * ] [Play] touch tap event
I (7330) PLAY_FLASH_MP3_CONTROL: [ * ] Pausing audio pipeline
I (8830) PLAY_FLASH_MP3_CONTROL: [ * ] [Play] touch tap event
I (8830) PLAY_FLASH_MP3_CONTROL: [ * ] Resuming audio pipeline
I (8850) PLAY_FLASH_MP3_CONTROL: [ * ] Receive music info from mp3 decoder, sample_rates=8000, bits=16, ch=2
I (86830) PLAY_FLASH_MP3_CONTROL: [ * ] [Vol+] touch tap event
I (86830) PLAY_FLASH_MP3_CONTROL: [ * ] Volume set to 79 %
I (90590) PLAY_FLASH_MP3_CONTROL: [ * ] [mode] tap event
E (90590) AUDIO_ELEMENT: [mp3] Element already stopped
E (90590) AUDIO_ELEMENT: [i2s] Element already stopped
I (90610) PLAY_FLASH_MP3_CONTROL: [ * ] Receive music info from mp3 decoder, sample_rates=22050, bits=16, ch=2
I (92470) PLAY_FLASH_MP3_CONTROL: [ * ] [mode] tap event
W (92470) AUDIO_ELEMENT: OUT-[mp3] AEL_IO_ABORT
W (92470) MP3_DECODER: output aborted -3
I (92540) PLAY_FLASH_MP3_CONTROL: [ * ] Receive music info from mp3 decoder, sample_rates=44100, bits=16, ch=2
I (94940) PLAY_FLASH_MP3_CONTROL: [ * ] [mode] tap event
W (94940) AUDIO_ELEMENT: OUT-[mp3] AEL_IO_ABORT
W (94940) MP3_DECODER: output aborted -3
W (94940) AUDIO_ELEMENT: IN-[i2s] AEL_IO_ABORT
I (95000) PLAY_FLASH_MP3_CONTROL: [ * ] Receive music info from mp3 decoder, sample_rates=8000, bits=16, ch=2
I (96670) PLAY_FLASH_MP3_CONTROL: [ * ] [mode] tap event
W (96670) AUDIO_ELEMENT: OUT-[mp3] AEL_IO_ABORT
W (96670) MP3_DECODER: output aborted -3
I (96810) PLAY_FLASH_MP3_CONTROL: [ * ] Receive music info from mp3 decoder, sample_rates=22050, bits=16, ch=2
I (101680) PLAY_FLASH_MP3_CONTROL: [ * ] [Set] touch tap event
I (101680) PLAY_FLASH_MP3_CONTROL: [ * ] Stopping audio pipeline
I (101680) PLAY_FLASH_MP3_CONTROL: [ 6 ] Stop audio_pipeline
W (101690) AUDIO_ELEMENT: OUT-[mp3] AEL_IO_ABORT
W (101690) MP3_DECODER: output aborted -3
W (101760) AUDIO_PIPELINE: There are no listener registered
W (101760) AUDIO_ELEMENT: [i2s] Element has not create when AUDIO_ELEMENT_TERMINATE
W (101760) AUDIO_ELEMENT: [mp3] Element has not create when AUDIO_ELEMENT_TERMINATE
```

## Technical support and feedback

Please use the following feedback channels:

* For technical queries, go to the [esp32.com](https://esp32.com/viewforum.php?f=20) forum
* For a feature request or bug report, create a [GitHub issue](https://github.com/espressif/esp-adf/issues)

We will get back to you as soon as possible.

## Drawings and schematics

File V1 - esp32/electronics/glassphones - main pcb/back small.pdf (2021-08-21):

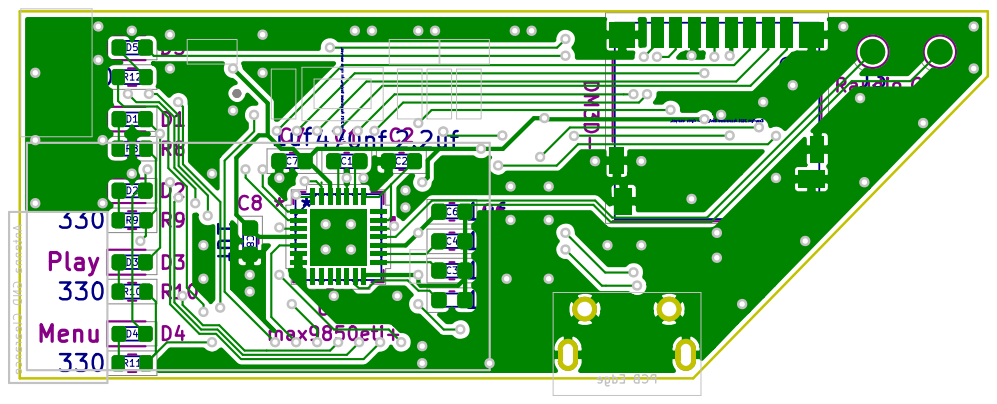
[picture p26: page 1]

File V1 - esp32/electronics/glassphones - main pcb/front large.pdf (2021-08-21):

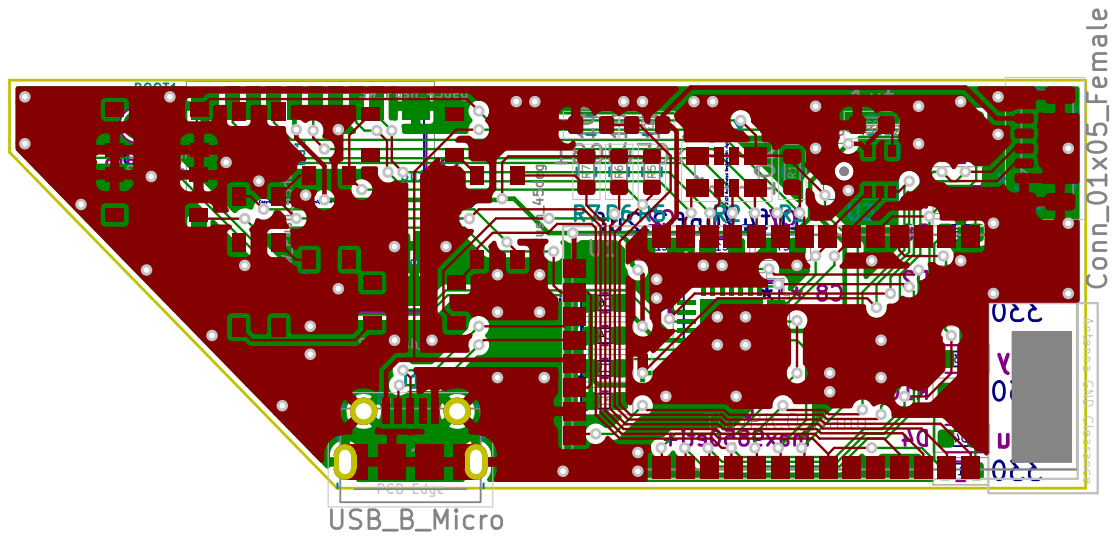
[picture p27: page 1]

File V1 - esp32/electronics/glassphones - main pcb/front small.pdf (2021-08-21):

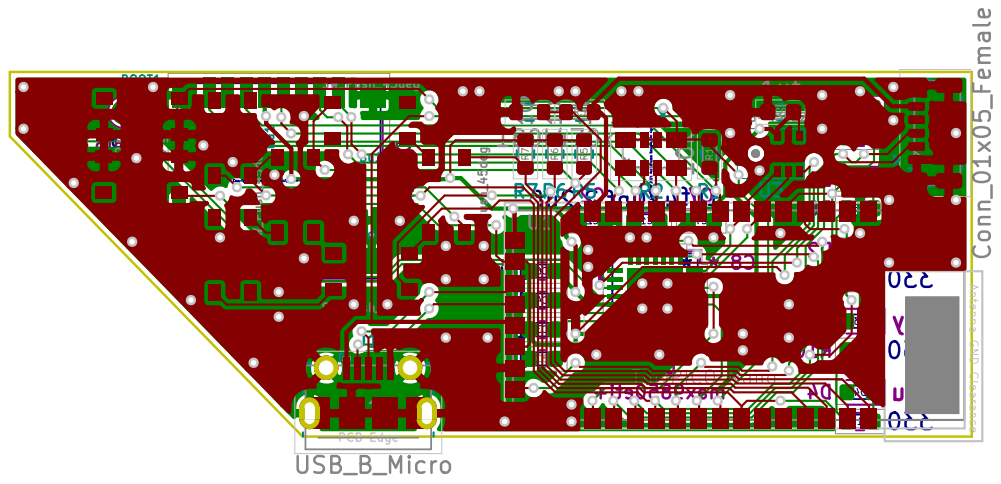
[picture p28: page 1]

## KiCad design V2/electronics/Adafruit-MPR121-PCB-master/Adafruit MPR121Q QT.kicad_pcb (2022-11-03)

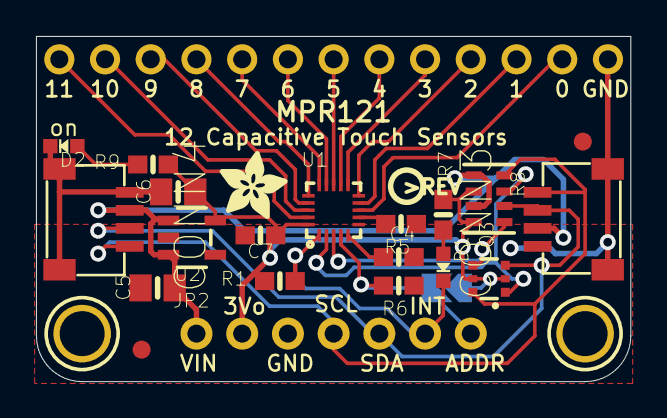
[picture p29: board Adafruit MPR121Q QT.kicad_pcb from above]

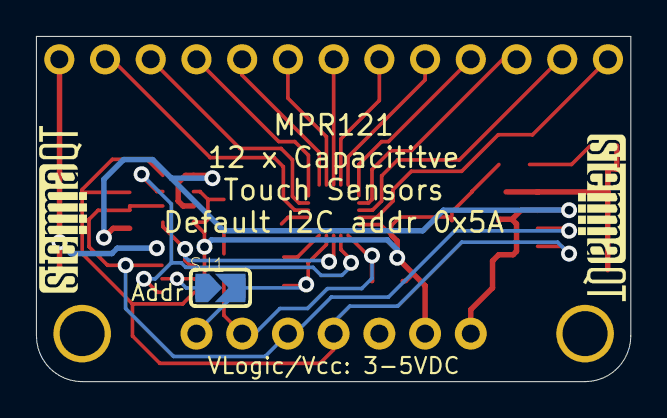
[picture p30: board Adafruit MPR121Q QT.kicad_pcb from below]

Board: 2 copper layers, 33.0 x 19.2 mm, 28 parts (3 on the bottom side), 25 nets.

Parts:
C4, C7: 0.1uF; 0603-NO
C5, C6: 10uF; 0805-NO
CONN3, CONN4: STEMMA_I2C_QT; JST_SH4
D1: RED; CHIPLED_0603_NOOUTLINE
D2: GREEN; CHIPLED_0603_NOOUTLINE
FID3, FID4: FIDUCIAL_1MM
JP1: 1X13_ROUND_70
JP2: 1X07_ROUND_70
Q3: BSS138; SOT363
R1, R6, R9: 10K; 0603-NO
R5: 75K; 0603-NO
R7: 1K; 0603-NO
R8: 10K; RESPACK_4X0603
SJ1: SOLDERJUMPER_ARROW_NOPASTE
U1: MPR121; QFN20_3MM_NOTHERMAL
U2: AP2112K-3.3; SOT23-5
U$9: PCBFEAT-REV-040
U$34, U$35: MOUNTINGHOLE2.5; MOUNTINGHOLE_2.5_PLATED
U$37: ADAFRUIT_3.5MM
U$39, U$40: STEMMAQT

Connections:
3.3V: C6.1, C7.1, JP2.2, Q3.2, Q3.5, R1.2, R7.2, R8.2, R8.4, R9.1, SJ1.1, U1.20, U2.5
ADDR: JP2.7, R6.2, SJ1.2, U1.4
ELEC0: JP1.12, U1.8
ELEC1: JP1.11, U1.9
ELEC2: JP1.10, U1.10
ELEC3: JP1.9, U1.11
ELEC4: JP1.8, U1.12
ELEC5: JP1.7, U1.13
ELEC6: JP1.6, U1.14
ELEC7: JP1.5, U1.15
ELEC8: JP1.4, U1.16
ELEC9: JP1.3, U1.17
ELEC10: JP1.2, U1.18
ELEC11: JP1.1, U1.19
GND: C4.2, C5.2, C6.2, C7.2, CONN3.1, CONN3.MT1, CONN3.MT2, CONN4.1, CONN4.MT1, CONN4.MT2, D2.C, JP1.13, JP2.3, R5.1, R6.1, U1.6, U2.2
INT: D1.C, JP2.6, R1.1, U1.1
unnamed: D1.A, R7.1
unnamed: C4.1, U1.5
unnamed: R5.2, U1.7
unnamed: D2.A, R9.2
SCL: CONN3.4, CONN4.4, JP2.4, Q3.6, R8.8
SCL_3V: Q3.1, R8.7, U1.2
SDA: CONN3.3, CONN4.3, JP2.5, Q3.3, R8.6
SDA_3V: Q3.4, R8.5, U1.3
VCC: C5.1, CONN3.2, CONN4.2, JP2.1, R8.1, R8.3, U2.1, U2.3

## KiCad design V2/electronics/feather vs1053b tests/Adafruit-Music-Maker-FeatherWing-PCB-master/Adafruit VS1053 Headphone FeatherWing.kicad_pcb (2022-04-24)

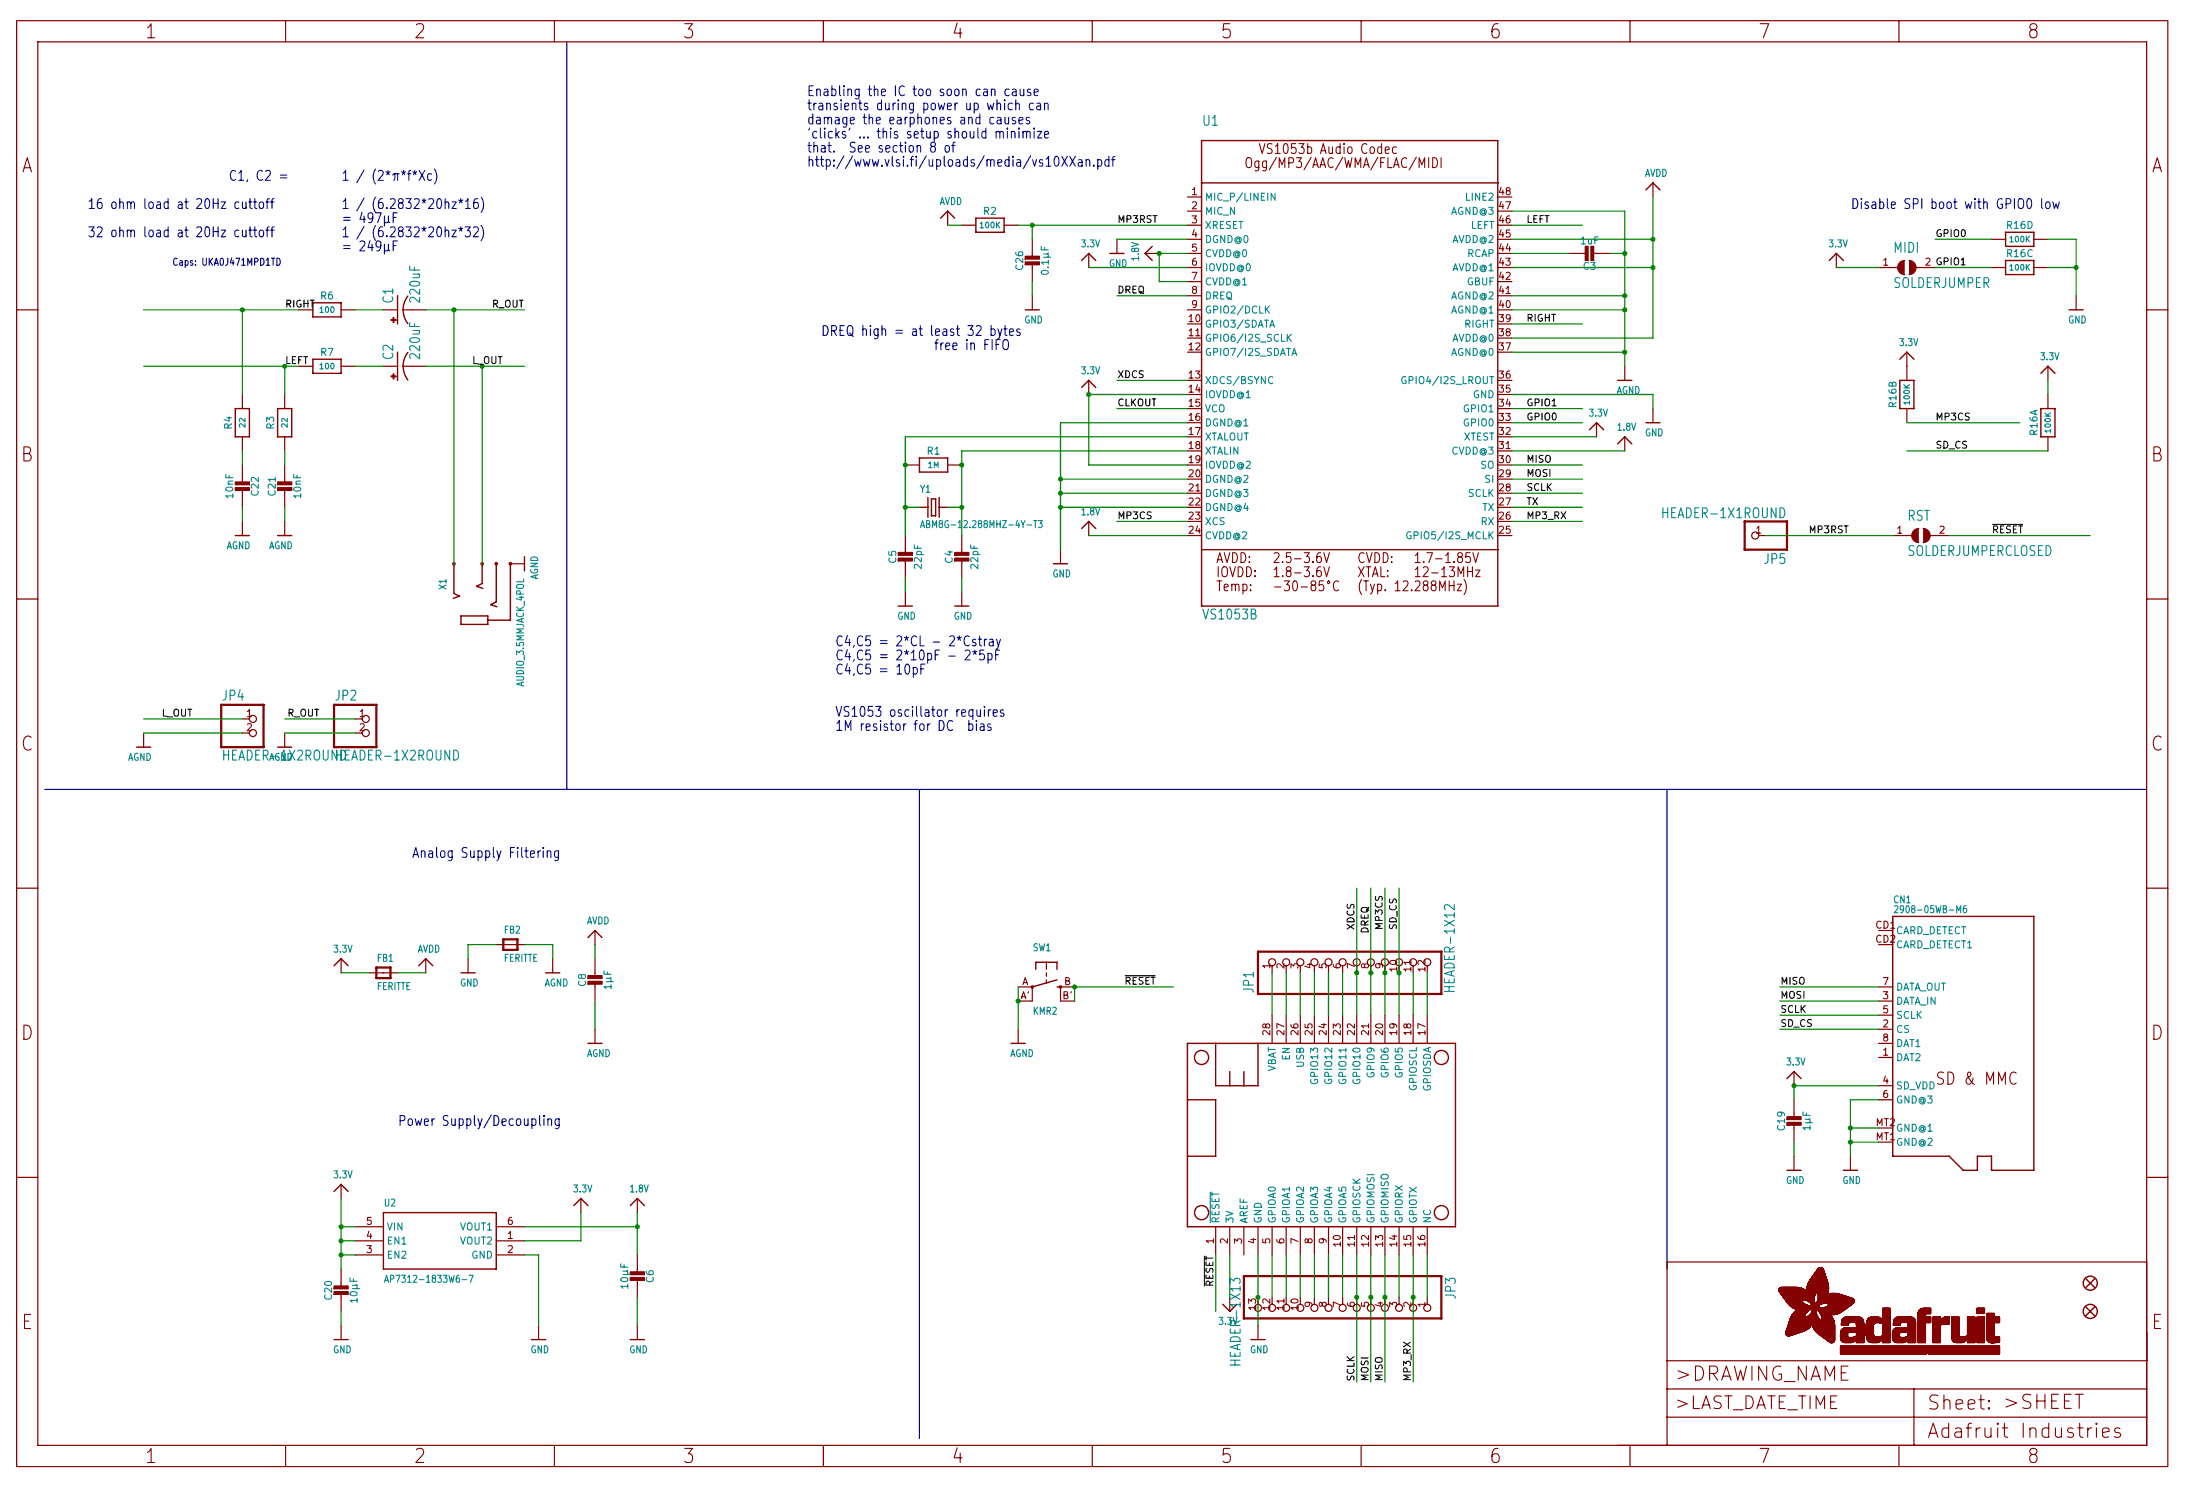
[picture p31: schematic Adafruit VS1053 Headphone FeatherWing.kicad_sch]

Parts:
C1, C2: 220uF; PANASONIC_C
C3: 1uF; 0603-NO
C4, C5: 22pF; 0603-NO
C6: 10µF; _0805MP
C8, C19: 1µF; 0603-NO
C20: 10µF; 0805-NO
C21, C22: 10nF; 0603-NO
C26: 0.1µF; 0603-NO
CN1: 2908-05WB-M6; MICROSD
FB1, FB2: FERITTE; 0805-NO
FID1, FID2: FIDUCIAL""; FIDUCIAL_1MM
JP1: HEADER-1X12; 1X12_ROUND
JP2, JP4: HEADER-1X2ROUND; 1X02_ROUND
JP3: HEADER-1X13; 1X13_ROUND_70
JP5: HEADER-1X1ROUND; 1X01_ROUND
MIDI: SOLDERJUMPER; SOLDERJUMPER_ARROW_NOPASTE
MS1: FEATHERWING_NODIM
R1: 1M; 0603-NO
R2: 100K; 0603-NO
R3, R4: 22; 0603-NO
R6, R7: 100; 0603-NO
R16: 100K; RESPACK_4X0603
RST: SOLDERJUMPERCLOSED; SOLDERJUMPER_CLOSEDWIRE
SW1: KMR2; BTN_KMR2_4.6X2.8
U1: VS1053B; LQFP48
U2: AP7312-1833W6-7; SOT23-6
X1: AUDIO_3.5MMJACK_4POL; 4UCONN_18510
Y1: ABM8G-12.288MHZ-4Y-T3; CRYSTAL_3.2X2.5

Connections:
1.8V: C6.1, U1.5 (CVDD@0), U1.7 (CVDD@1), U1.24 (CVDD@2), U1.31 (CVDD@3), U2.6 (VOUT1)
3.3V: C19.1, C20.1, CN1.4 (SD_VDD), FB1.1, MIDI.1, MS1.2 (3V), R16.7 (2), R16.8 (2), U1.6 (IOVDD@0), U1.14 (IOVDD@1), U1.19 (IOVDD@2), U1.32 (XTEST), U2.1 (VOUT2), U2.3 (EN2), U2.4 (EN1), U2.5 (VIN); also elsewhere on the board
AGND: C3.2, C8.2, C21.2, C22.2, FB2.2, JP2.2, JP4.2, SW1.A, SW1.A' (P1), U1.37 (AGND@0), U1.40 (AGND@1), U1.41 (AGND@2), U1.47 (AGND@3), X1.1-GND (TIP)
AVDD: C8.1, FB1.2, R2.1, U1.38 (AVDD@0), U1.43 (AVDD@1), U1.45 (AVDD@2)
CLKOUT: U1.15 (VCO)
DREQ: JP1.8, MS1.21 (GPIO9), U1.8 (DREQ)
GND: C4.2, C5.2, C6.2, C19.2, C20.2, C26.2, CN1.6 (GND@3), CN1.MT1 (GND@2), CN1.MT2 (GND@1), FB2.1, JP3.13, MS1.4 (GND), R16.5 (2), R16.6 (2), U1.4 (DGND@0), U1.16 (DGND@1), U1.20 (DGND@2), U1.21 (DGND@3), U1.22 (DGND@4), U1.35 (GND), U2.2 (GND)
GPIO0: R16.4 (1), U1.33 (GPIO0)
GPIO1: MIDI.2, R16.3 (1), U1.34 (GPIO1); also elsewhere on the board
LEFT: R3.1, R7.2, U1.46 (LEFT)
LEFT_FILTERED: C2.+, R7.1
L_OUT: C2.-, JP4.1, X1.2-TIP (RING3)
MISO: CN1.7 (DATA_OUT), JP3.4, MS1.13 (GPIOMISO), U1.30 (SO)
MOSI: CN1.3 (DATA_IN), JP3.5, MS1.12 (GPIOMOSI), U1.29 (SI)
MP3CS: JP1.9, MS1.20 (GPIO6), R16.2 (1), U1.23 (XCS)
MP3RST: C26.1, JP5.1, R2.2, RST.1, U1.3 (XRESET); also elsewhere on the board
MP3_RX: JP3.2, MS1.15 (GPIOTX), U1.26 (RX)
unnamed: C5.1, R1.1, U1.17 (XTALOUT), Y1.1
unnamed: C4.1, R1.2, U1.18 (XTALIN), Y1.2
unnamed: C3.1, U1.44 (RCAP)
unnamed: JP1.2, MS1.27 (EN)
unnamed: C21.1, R3.2
unnamed: C22.1, R4.2
unnamed: JP1.4, MS1.25 (GPIO13)
unnamed: JP1.5, MS1.24 (GPIO12)
unnamed: JP1.6, MS1.23 (GPIO11)
unnamed: JP1.11, MS1.18 (GPIOSCL)
unnamed: JP1.12, MS1.17 (GPIOSDA)
unnamed: JP3.1, MS1.16 (NC)
unnamed: JP3.3, MS1.14 (GPIORX)
unnamed: JP3.7, MS1.10 (GPIOA5)
unnamed: JP3.8, MS1.9 (GPIOA4)
unnamed: JP3.9, MS1.8 (GPIOA3)
unnamed: JP3.10, MS1.7 (GPIOA2)
unnamed: JP3.11, MS1.6 (GPIOA1)
unnamed: JP3.12, MS1.5 (GPIOA0)
RIGHT: R4.1, R6.2, U1.39 (RIGHT)
RIGHT_FILTERED: C1.+, R6.1
R_OUT: C1.-, JP2.1, X1.3-OUTER_SLEEVE (RING2)
SCLK: CN1.5 (SCLK), JP3.6, MS1.11 (GPIOSCK), U1.28 (SCLK)
SD_CS: CN1.2 (CS), JP1.10, MS1.19 (GPIO5), R16.1
TX: U1.27 (TX)
USB: JP1.3, MS1.26 (USB)
VBAT: JP1.1, MS1.28 (VBAT)
XDCS: JP1.7, MS1.22 (GPIO10), U1.13 (XDCS/BSYNC)
~RESET: MS1.1 (~RESET), RST.2, SW1.B (S), SW1.B' (S1); also elsewhere on the board

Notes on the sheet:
http://www.vlsi.fi/uploads/media/vs10XXan.pdf
C1, C2 =
'clicks' ... this setup should minimize
free in FIFO
1M resistor for DC bias
that. See section 8 of
damage the earphones and causes
1 / (2*π*f*Xc)
C4,C5 = 10pF
1 / (6.2832*20hz*16)
transients during power up which can
16 ohm load at 20Hz cuttoff
32 ohm load at 20Hz cuttoff
Caps: UKA0J471MPD1TD
Disable SPI boot with GPIO0 low
Power Supply/Decoupling
C4,C5 = 2*CL - 2*Cstray
1 / (6.2832*20hz*32)
= 249µF
= 497µF
C4,C5 = 2*10pF - 2*5pF
Enabling the IC too soon can cause
VS1053 oscillator requires
DREQ high = at least 32 bytes
Analog Supply Filtering

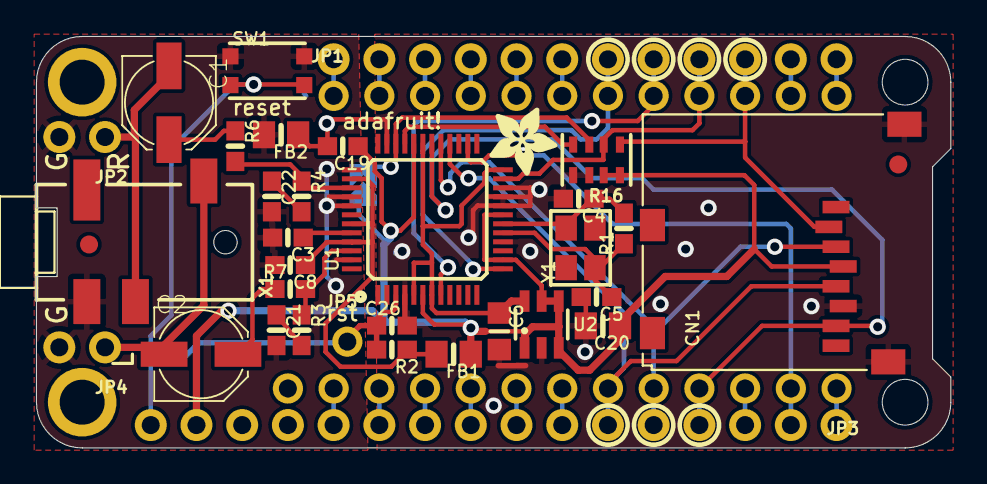
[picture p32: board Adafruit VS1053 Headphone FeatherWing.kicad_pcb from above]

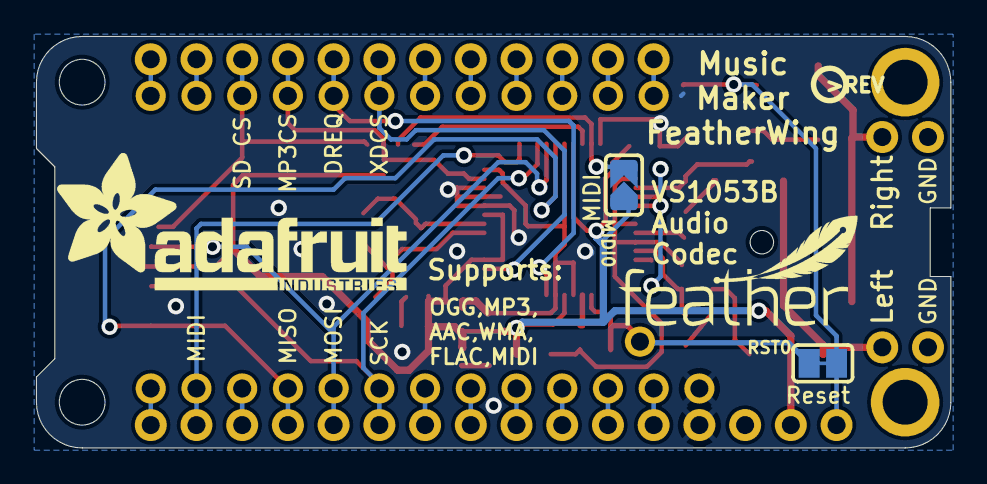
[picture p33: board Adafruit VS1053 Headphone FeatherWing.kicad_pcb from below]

Board: 2 copper layers, 50.8 x 22.9 mm, 41 parts (5 on the bottom side), 44 nets.

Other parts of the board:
MIDI0: SOLDERJUMPER_ARROW_NOPASTE
RST0: SOLDERJUMPER_CLOSEDWIRE
U$36: ADAFRUIT_3.5MM
U$37: FEATHERLOGO_SMALL
U$43: PCBFEAT-REV-040
U$55: ADAFRUIT_TEXT_20MM

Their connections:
3.3V: MIDI0.1; also elsewhere on the board
GPIO1: MIDI0.2; also elsewhere on the board
MP3RST: RST0.1; also elsewhere on the board
~RESET: RST0.2; also elsewhere on the board

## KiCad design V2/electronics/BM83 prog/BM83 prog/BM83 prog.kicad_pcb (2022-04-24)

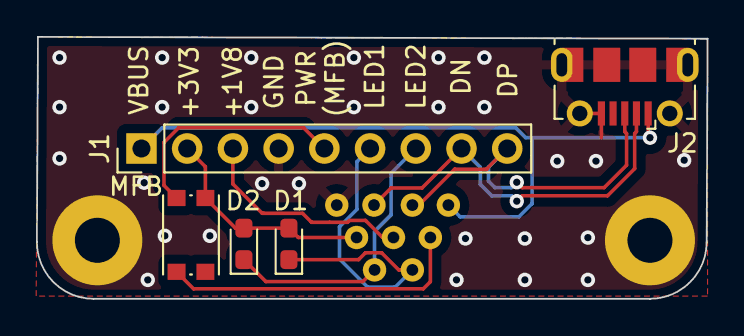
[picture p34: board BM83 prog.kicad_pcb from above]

Board: 2 copper layers, 37.3 x 14.6 mm, 14 parts (0 on the bottom side), 9 nets.

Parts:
D1: LED1; LED_0603_1608Metric_Pad1.05x0.95mm_HandSolder
D2: LED2; LED_0603_1608Metric_Pad1.05x0.95mm_HandSolder
J1: Conn_01x09_Male; PinHeader_1x09_P2.54mm_Vertical
J2: USB_B_Micro; USB_Micro-B_Molex-105017-0001
MFB: PWR MFB; SW_Push_1P1T_NO_CK_KMR2
TP30: BM83_MFB; 0.65mm pogo pin
TP31: BM83_LED1; 0.65mm pogo pin
TP32: BM83_LED2; 0.65mm pogo pin
TP33: BM83_USB_DN; 0.65mm pogo pin
TP34: BM83_USB_DP; 0.65mm pogo pin
TP70: 5V VBUS; 0.65mm pogo pin
TP71: 3.3V; 0.65mm pogo pin
TP72: 1.8V; 0.65mm pogo pin
TP73: GND; 0.65mm pogo pin

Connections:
+1V8: J1.3, TP72.1
+3V3: D1.2 (A), D2.2 (A), J1.2, MFB.2, TP71.1
/DN: J1.8, J2.2 (D-), TP33.1
/DP: J1.9, J2.3 (D+), TP34.1
/LED1: D1.1 (K), J1.6, TP31.1
/LED2: D2.1 (K), J1.7, TP32.1
/PWR(MFB): J1.5, MFB.1, TP30.1
GND: J1.4, J2.5 (GND), J2.6 (Shield), TP73.1
VBUS: J1.1, J2.1 (VBUS), TP70.1

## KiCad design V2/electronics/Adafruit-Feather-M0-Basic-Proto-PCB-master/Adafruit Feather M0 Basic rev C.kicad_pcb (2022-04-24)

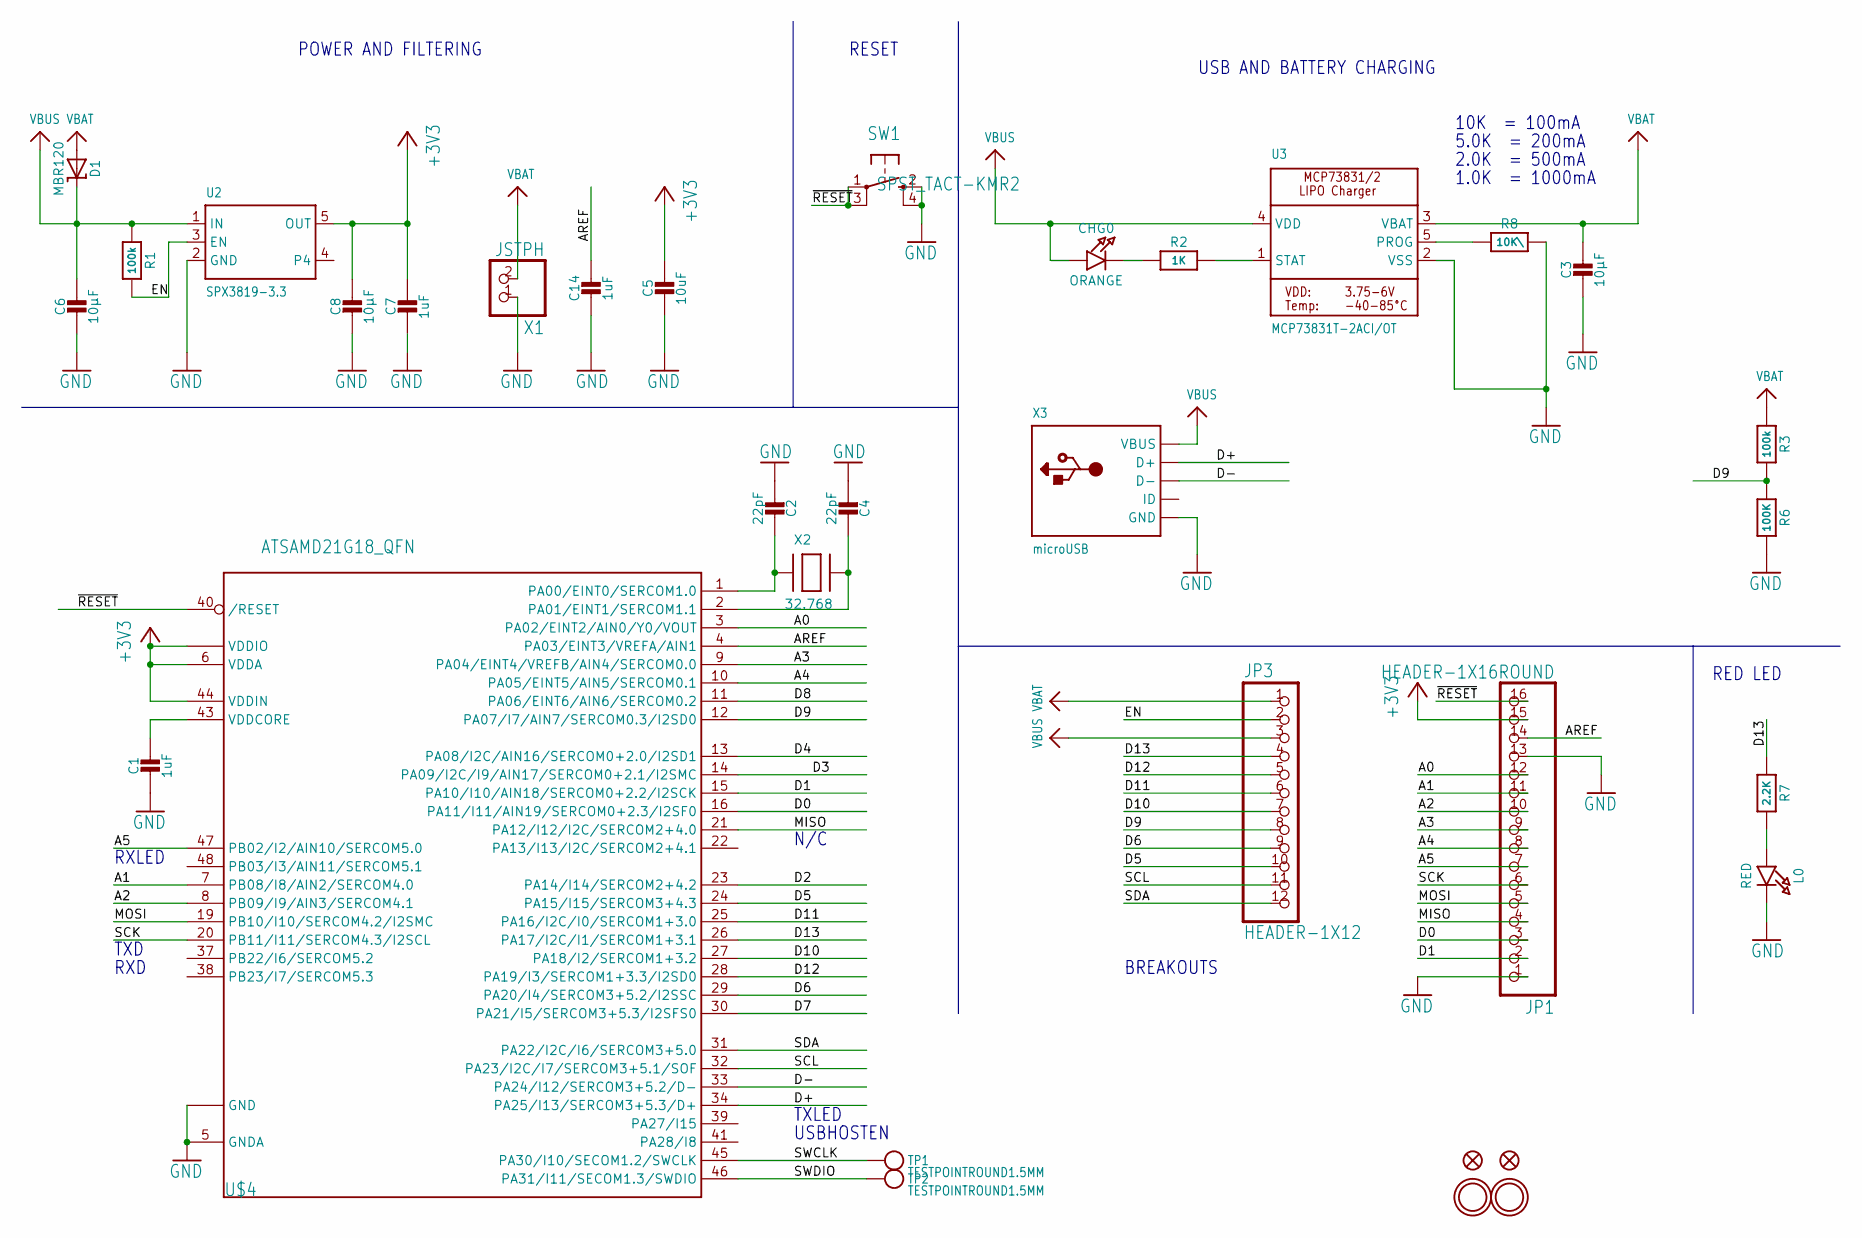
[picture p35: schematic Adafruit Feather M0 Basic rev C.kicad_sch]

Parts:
C1, C7, C14: 1uF; 0603-NO
C2, C4: 22pF; 0603-NO
C3, C6, C8: 10µF; 0805-NO
C5: 10uF; 0805-NO
CHG0: ORANGE; CHIPLED_0805_NOOUTLINE
D1: MBR120; SOD-123
JP1: HEADER-1X16ROUND; 1X16_ROUND
JP3: HEADER-1X12; 1X12_ROUND
L0: RED; CHIPLED_0805_NOOUTLINE
R1, R3: 100k; 0603-NO
R2: 1K; 0603-NO
R6: 100K; 0603-NO
R7: 2.2K; 0603-NO
R8: 10K\; 0603-NO
SW1: SPST_TACT-KMR2; KMR2
TP1, TP2: TESTPOINTROUND1.5MM; TESTPOINT_ROUND_1.5MM
U2: SPX3819-3.3; SOT23-5
U3: MCP73831T-2ACI/OT; SOT23-5
U$4: ATSAMD21G18_QFN; TQFN48_7MM
U$31, U$32: MOUNTINGHOLE2.5; MOUNTINGHOLE_2.5_PLATED
U$34, U$35: FIDUCIAL""; FIDUCIAL_1MM
X1: JSTPH; JSTPH2
X2: 32.768; XTAL3215
X3: microUSB; 4UCONN_20329_V2

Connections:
+3V3: C5.1, C7.1, C8.1, JP1.15, U2.5 (OUT), U$4.6 (VDDA), U$4.17 (VDDIO), U$4.36 (VDDIO), U$4.44 (VDDIN)
A0: JP1.12, U$4.3 (PA02/EINT2/AIN0/Y0/VOUT)
A1: JP1.11, U$4.7 (PB08/I8/AIN2/SERCOM4.0)
A2: JP1.10, U$4.8 (PB09/I9/AIN3/SERCOM4.1)
A3: JP1.9, U$4.9 (PA04/EINT4/VREFB/AIN4/SERCOM0.0)
A4: JP1.8, U$4.10 (PA05/EINT5/AIN5/SERCOM0.1)
A5: JP1.7, U$4.47 (PB02/I2/AIN10/SERCOM5.0)
AREF: C14.1, JP1.14, U$4.4 (PA03/EINT3/VREFA/AIN1)
D0: JP1.3, U$4.16 (PA11/I11/AIN19/SERCOM0+2.3/I2SF0)
D1: JP1.2, U$4.15 (PA10/I10/AIN18/SERCOM0+2.2/I2SCK)
D2: U$4.23 (PA14/I14/SERCOM2+4.2)
D3: U$4.14 (PA09/I2C/I9/AIN17/SERCOM0+2.1/I2SMC)
D4: U$4.13 (PA08/I2C/AIN16/SERCOM0+2.0/I2SD1)
D5: JP3.10, U$4.24 (PA15/I15/SERCOM3+4.3)
D6: JP3.9, U$4.29 (PA20/I4/SERCOM3+5.2/I2SSC)
D7: U$4.30 (PA21/I5/SERCOM3+5.3/I2SFS0)
D8: U$4.11 (PA06/EINT6/AIN6/SERCOM0.2)
D9: JP3.8, R3.2, R6.1, U$4.12 (PA07/I7/AIN7/SERCOM0.3/I2SD0)
D10: JP3.7, U$4.27 (PA18/I2/SERCOM1+3.2)
D11: JP3.6, U$4.25 (PA16/I2C/I0/SERCOM1+3.0)
D12: JP3.5, U$4.28 (PA19/I3/SERCOM1+3.3/I2SD0)
D13: JP3.4, R7.1, U$4.26 (PA17/I2C/I1/SERCOM1+3.1)
D+: U$4.34 (PA25/I13/SERCOM3+5.3/D+), X3.D+
D-: U$4.33 (PA24/I12/SERCOM3+5.2/D-), X3.D-
EN: JP3.2, R1.2, U2.3 (EN)
GND: C1.2, C2.2, C3.2, C4.2, C5.2, C6.2, C7.2, C8.2, C14.2, JP1.1, JP1.13, L0.C, R6.2, R8.2, SW1.2 (S), SW1.4 (S1), U2.2 (GND), U3.2 (VSS), U$4.5 (GNDA), U$4.18 (GND), U$4.35 (GND), U$4.42 (GND), U$4.THERMAL (GND), X1.1, X3.BASE@1 (GND), X3.BASE@2 (GND), X3.GND, X3.SPRT@1 (GND), X3.SPRT@2 (GND), X3.SPRT@3 (GND), X3.SPRT@4 (GND)
MISO: JP1.4, U$4.21 (PA12/I12/I2C/SERCOM2+4.0)
MOSI: JP1.5, U$4.19 (PB10/I10/SERCOM4.2/I2SMC)
unnamed: CHG0.C, R2.1
unnamed: L0.A, R7.2
unnamed: R2.2, U3.1 (STAT)
unnamed: R8.1, U3.5 (PROG)
unnamed: C2.1, U$4.1 (PA00/EINT0/SERCOM1.0), X2.P$1
unnamed: C4.1, U$4.2 (PA01/EINT1/SERCOM1.1), X2.P$2
SCK: JP1.6, U$4.20 (PB11/I11/SERCOM4.3/I2SCL)
SCL: JP3.11, U$4.32 (PA23/I2C/I7/SERCOM3+5.1/SOF)
SDA: JP3.12, U$4.31 (PA22/I2C/I6/SERCOM3+5.0)
SWCLK: TP1.P$1, U$4.45 (PA30/I10/SECOM1.2/SWCLK)
SWDIO: TP2.P$1, U$4.46 (PA31/I11/SECOM1.3/SWDIO)
VBAT: C3.1, D1.A, JP3.1, R3.1, U3.3 (VBAT), X1.2
VBUS: C6.1, CHG0.A, D1.C, JP3.3, R1.1, U2.1 (IN), U3.4 (VDD), X3.VBUS
VDDCORE: C1.1, U$4.43 (VDDCORE)
~RESET: JP1.16, SW1.1, SW1.3 (P1), U$4.40 (/RESET)

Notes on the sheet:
N/C
TXD
2.0K = 500mA
1.0K = 1000mA
RESET
BREAKOUTS
TXLED
RXLED
USB AND BATTERY CHARGING
RXD
USBHOSTEN
10K = 100mA
POWER AND FILTERING
5.0K = 200mA
RED LED

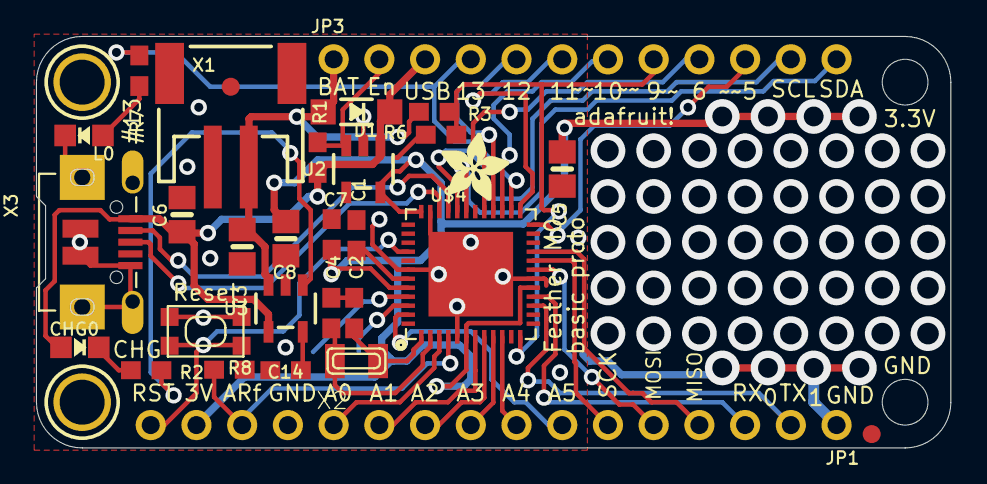
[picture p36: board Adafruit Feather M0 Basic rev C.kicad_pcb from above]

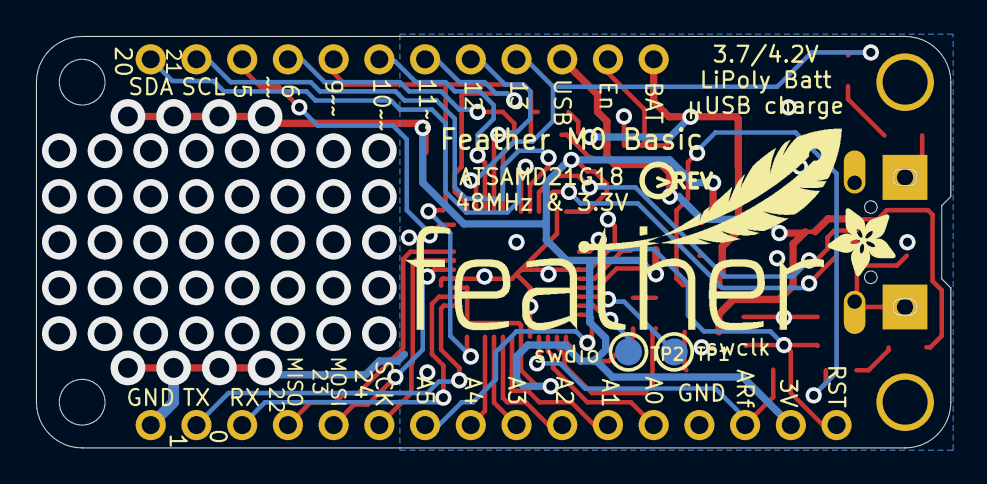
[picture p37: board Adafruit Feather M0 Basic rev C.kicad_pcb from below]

Board: 2 copper layers, 50.8 x 22.9 mm, 39 parts (5 on the bottom side), 38 nets.

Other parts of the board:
@HOLE0, @HOLE1: (no value)
U$7, U$12: ADAFRUIT_3.5MM
U$9: FEATHERLOGO
U$13: PCBFEAT-REV-040

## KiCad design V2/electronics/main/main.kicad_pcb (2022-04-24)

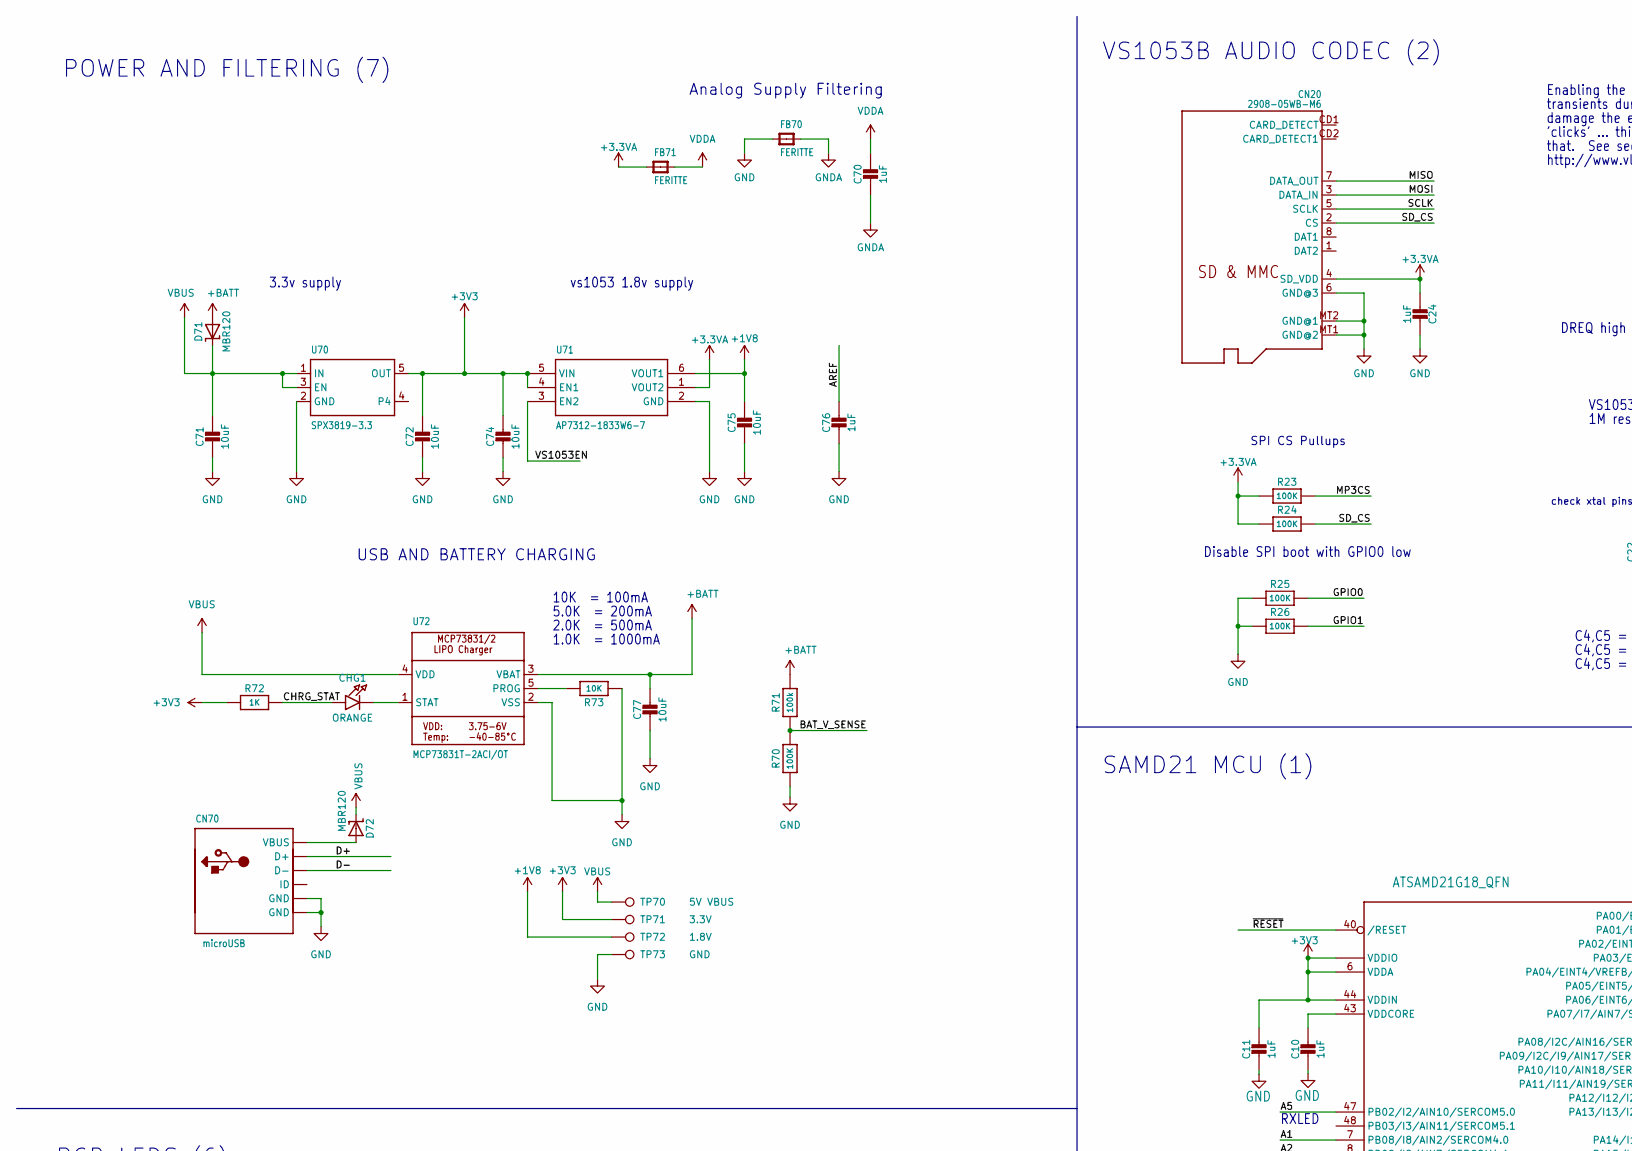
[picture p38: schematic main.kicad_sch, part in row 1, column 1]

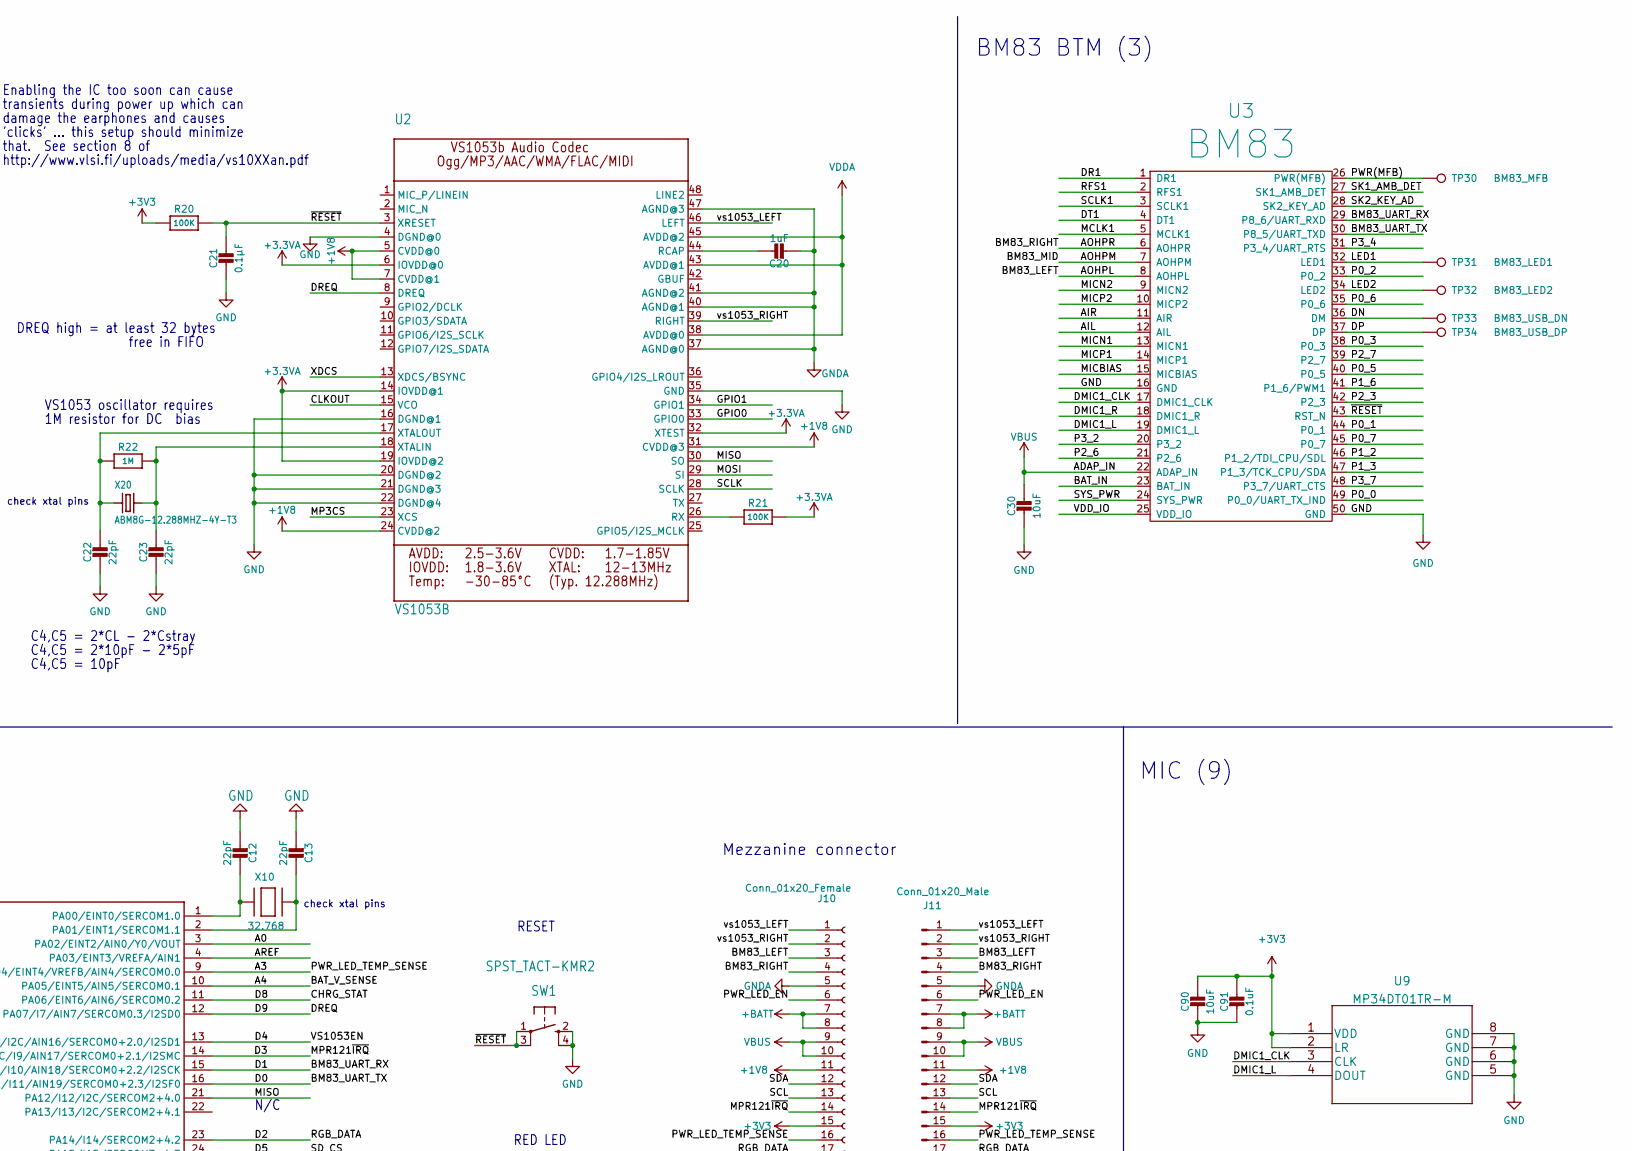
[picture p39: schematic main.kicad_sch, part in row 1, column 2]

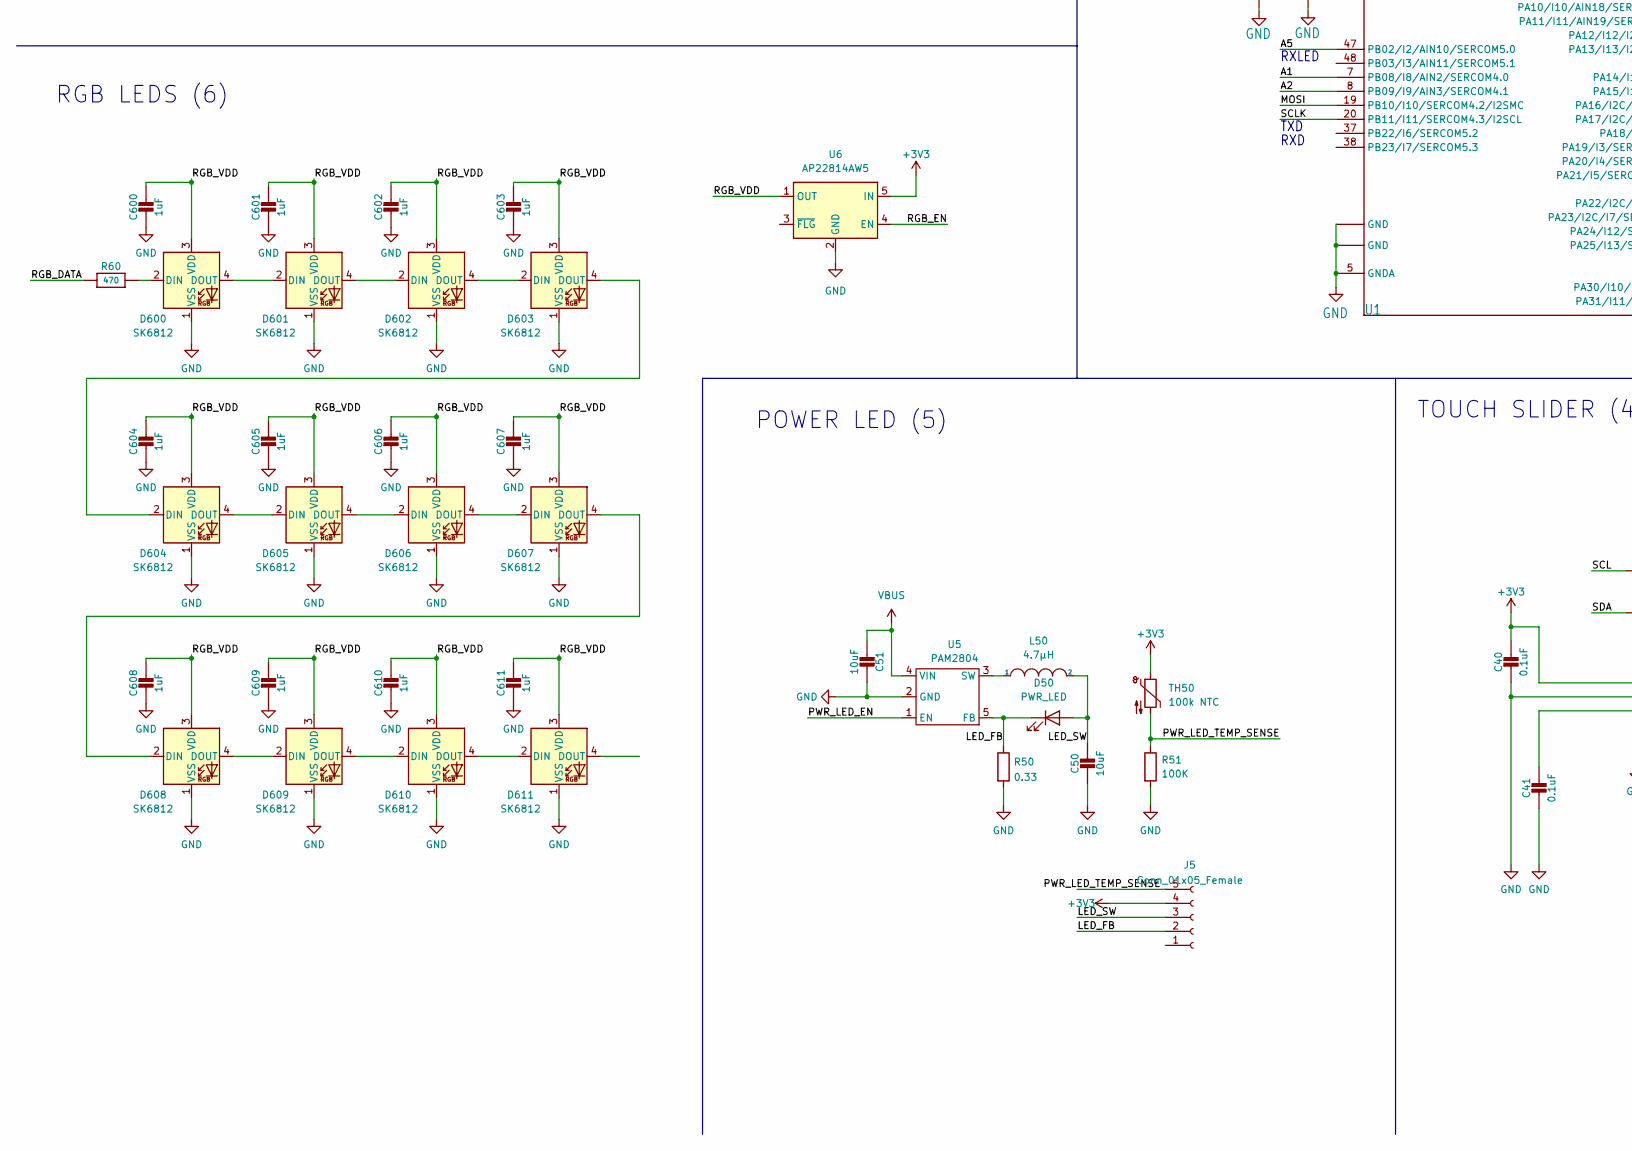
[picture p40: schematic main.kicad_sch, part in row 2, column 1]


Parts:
C10, C11, C20, C24, C70, C76, C600, C601, C602, C603, C604, C605, C606, C607, C608, C609, C610, C611: 1uF; C_0402_1005Metric
C12, C13, C22, C23: 22pF; C_0402_1005Metric
C21: 0.1µF; C_0402_1005Metric
C30, C50, C51, C71, C72, C74, C75, C77, C90: 10uF; C_0402_1005Metric
C40, C41, C91: 0.1uF; C_0402_1005Metric
C80, C81, C84, C85: 10nF; C_0402_1005Metric
C82, C83, C86, C87, C88, C89, C810: 1uf; C_0402_1005Metric
CHG1: ORANGE; LED_0603_1608Metric
CN20: 2908-05WB-M6; microSD_HC_Hirose_DM3D-SF
CN70: microUSB; USB_Micro-B_Molex-105017-0001
D10: RED; LED_0603_1608Metric
D50: PWR_LED
D71, D72: MBR120; D_SOD-123
D600, D601, D602, D603, D604, D605, D606, D607, D608, D609, D610, D611: SK6812; LED_SK6812_EC15_1.5x1.5mm
FB70, FB71: FERITTE; R_0805_2012Metric
J5: Conn_01x05_Female; Hirose_DF52-5S-0.8H_1x05-1MP_P0.80mm_Horizontal
J10: Conn_01x20_Female; Hirose_DF12_DF12E3.0-20DP-0.5V_2x10_P0.50mm_Vertical
J11: Conn_01x20_Male; Hirose_DF12_DF12C3.0-20DS-0.5V_2x10_P0.50mm_Vertical
J40: CAP TOUCH SLIDER
J80: Conn_01x04_Female; Hirose_DF52-5S-0.8H_1x05-1MP_P0.80mm_Horizontal
J81: Conn_01x02_Female; Hirose_DF52-5S-0.8H_1x05-1MP_P0.80mm_Horizontal
L50: 4.7μH; L_1210_3225Metric
R10: 2.2K; R_0402_1005Metric
R20, R21, R23, R24, R25, R26, R51, R70: 100K; R_0402_1005Metric
R22: 1M; R_0402_1005Metric
R40: 75K; R_0402_1005Metric
R41, R42, R73: 10K; R_0402_1005Metric
R50: 0.33; R_0402_1005Metric
R60: 470; R_0402_1005Metric
R71: 100k; R_0402_1005Metric
R72: 1K; R_0402_1005Metric
R80, R81, R84, R85: 22; R_0402_1005Metric
R82, R83, R86, R87: 100; R_0402_1005Metric
SW1: SPST_TACT-KMR2; SW_Push_1P1T_NO_CK_KMR2
TH50: 100k NTC
TP30: BM83_MFB; TestPoint_Pad_D1.0mm
TP31: BM83_LED1; TestPoint_Pad_D1.0mm
TP32: BM83_LED2; TestPoint_Pad_D1.0mm
TP33: BM83_USB_DN; TestPoint_Pad_D1.0mm
TP34: BM83_USB_DP; TestPoint_Pad_D1.0mm
TP70: 5V VBUS; TestPoint_Pad_D1.0mm
TP71: 3.3V; TestPoint_Pad_D1.0mm
TP72: 1.8V; TestPoint_Pad_D1.0mm
TP73: GND; TestPoint_Pad_D1.0mm
U1: ATSAMD21G18_QFN; TQFN-48-1EP_7x7mm_P0.5mm_EP5.1x5.1mm
U2: VS1053B; LQFP-48_7x7mm_P0.5mm
U3: BM83
U4: MPR121Q; UQFN-20_3x3mm_P0.4mm
U5: PAM2804; TSOT-23-5
U6: AP22814AW5; SOT-23-5
U8: max9725aetc+; max9725aetc&plus_
U9: MP34DT01TR-M
U70: SPX3819-3.3; SOT-23-5
U71: AP7312-1833W6-7; SOT-23-6
U72: MCP73831T-2ACI/OT; SOT-23-5
X10: 32.768; XTAL3215
X20: ABM8G-12.288MHZ-4Y-T3; CRYSTAL_3.2X2.5

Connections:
+1V8: C75.1, C810.1, J10.11, J11.11, TP72.1, U2.5 (CVDD@0), U2.7 (CVDD@1), U2.24 (CVDD@2), U2.31 (CVDD@3), U8.9 (VDD), U8.12 (~SHDN), U71.6 (VOUT1)
+3.3VA: C24.1, CN20.4 (SD_VDD), FB71.1, R21.2, R23.1, R24.1, U2.6 (IOVDD@0), U2.14 (IOVDD@1), U2.19 (IOVDD@2), U2.32 (XTEST), U71.1 (VOUT2)
+3V3: C11.1, C40.1, C72.1, C74.1, C90.1, C91.1, J5.4, J10.15, J11.15, R20.1, R41.2, R42.2, R72.1, TH50.1, TP71.1, U1.6 (VDDA), U1.17 (VDDIO), U1.36 (VDDIO), U1.44 (VDDIN), U4.20 (VDD), U6.5 (IN), U9.1 (VDD), U9.2 (LR), U70.5 (OUT), U71.4 (EN1), U71.5 (VIN)
+BATT: C77.1, D71.2 (A), J10.7, J10.8, J11.7, J11.8, J80.2, R71.1, U72.3 (VBAT)
/A0: U1.3 (PA02/EINT2/AIN0/Y0/VOUT)
/A1: U1.7 (PB08/I8/AIN2/SERCOM4.0)
/A2: U1.8 (PB09/I9/AIN3/SERCOM4.1)
/A3: J5.5, J10.16, J11.16, R51.1, TH50.2, U1.9 (PA04/EINT4/VREFB/AIN4/SERCOM0.0)
/A4: R70.1, R71.2, U1.10 (PA05/EINT5/AIN5/SERCOM0.1)
/A5: U1.47 (PB02/I2/AIN10/SERCOM5.0)
/AIL: U3.12 (AIL)
/AIR: U3.11 (AIR)
/AOHPL: J10.3, J11.3, R84.1, R86.2, U3.8 (AOHPL)
/AOHPM: U3.7 (AOHPM)
/AOHPR: J10.4, J11.4, R85.1, R87.2, U3.6 (AOHPR)
/AREF: C76.1, U1.4 (PA03/EINT3/VREFA/AIN1)
/BAT_IN: U3.23 (BAT_IN)
/BM83_UART_RX: U1.15 (PA10/I10/AIN18/SERCOM0+2.2/I2SCK), U3.29 (P8_6/UART_RXD)
/BM83_UART_TX: U1.16 (PA11/I11/AIN19/SERCOM0+2.3/I2SF0), U3.30 (P8_5/UART_TXD)
/CHRG_STAT: CHG1.2 (A), R72.2, U1.11 (PA06/EINT6/AIN6/SERCOM0.2)
/CLKOUT: U2.15 (VCO)
/D2: J10.17, J11.17, R60.1, U1.23 (PA14/I14/SERCOM2+4.2)
/D3: J10.14, J11.14, U1.14 (PA09/I2C/I9/AIN17/SERCOM0+2.1/I2SMC), U4.1 (#IRQ)
/D4: U1.13 (PA08/I2C/AIN16/SERCOM0+2.0/I2SD1), U71.3 (EN2)
/D5: CN20.2 (CS), R24.2, U1.24 (PA15/I15/SERCOM3+4.3)
/D6: R23.2, U1.29 (PA20/I4/SERCOM3+5.2/I2SSC), U2.23 (XCS)
/D7: J10.6, J11.6, U1.30 (PA21/I5/SERCOM3+5.3/I2SFS0), U5.1 (EN)
/D9: U1.12 (PA07/I7/AIN7/SERCOM0.3/I2SD0), U2.8 (DREQ)
/D10: U1.27 (PA18/I2/SERCOM1+3.2), U2.13 (XDCS/BSYNC)
/D11: J10.18, J11.18, U1.25 (PA16/I2C/I0/SERCOM1+3.0), U6.4 (EN)
/D12: U1.28 (PA19/I3/SERCOM1+3.3/I2SD0)
/D13: R10.1, U1.26 (PA17/I2C/I1/SERCOM1+3.1)
/D+: CN70.2 (D+), U1.34 (PA25/I13/SERCOM3+5.3/D+)
/D-: CN70.3 (D-), U1.33 (PA24/I12/SERCOM3+5.2/D-)
/DMIC1_CLK: U3.17 (DMIC1_CLK), U9.3 (CLK)
/DMIC1_L: U3.19 (DMIC1_L), U9.4 (DOUT)
/DMIC1_R: U3.18 (DMIC1_R)
/DN: TP33.1, U3.36 (DM)
/DP: TP34.1, U3.37 (DP)
/DR1: U3.1 (DR1)
/DT1: U3.4 (DT1)
/ELEC0: J40.1, U4.8 (ELE0)
/ELEC1: J40.2, U4.9 (ELE1)
/ELEC2: J40.3, U4.10 (ELE2)
/ELEC3: J40.4, U4.11 (ELE3)
/ELEC4: J40.5, U4.12 (ELE4/LED0)
/ELEC5: J40.6, U4.13 (ELE5/LED1)
/ELEC6: J40.7, U4.14 (ELE6/LED2)
/ELEC7: J40.8, U4.15 (ELE7/LED3)
/ELEC8: J40.9, U4.16 (ELE8/LED4)
/ELEC9: J40.10, U4.17 (ELE9/LED5)
/ELEC10: J40.11, U4.18 (ELE10/LED6)
/ELEC11: J40.12, U4.19 (ELE11/LED7)
/GPIO0: R25.2, U2.33 (GPIO0)
/GPIO1: R26.2, U2.34 (GPIO1)
/LED1: TP31.1, U3.32 (LED1)
/LED2: TP32.1, U3.34 (LED2)
/LED_FB: D50.1 (K), J5.2, R50.1, U5.5 (FB)
/LED_SW: C50.1, D50.2 (A), J5.3, L50.2
/L_OUT: J80.5, U8.8 (OUTL)
/MCLK1: U3.5 (MCLK1)
/MICBIAS: U3.15 (MICBIAS)
/MICN1: U3.13 (MICN1)
/MICN2: U3.9 (MICN2)
/MICP1: U3.14 (MICP1)
/MICP2: U3.10 (MICP2)
/MISO: CN20.7 (DATA_OUT), U1.21 (PA12/I12/I2C/SERCOM2+4.0), U2.30 (SO)
/MOSI: CN20.3 (DATA_IN), U1.19 (PB10/I10/SERCOM4.2/I2SMC), U2.29 (SI)
/P0_0: U3.49 (P0_0/UART_TX_IND)
/P0_1: U3.44 (P0_1)
/P0_2: U3.33 (P0_2)
/P0_3: U3.38 (P0_3)
/P0_5: U3.40 (P0_5)
/P0_6: U3.35 (P0_6)
/P0_7: U3.45 (P0_7)
/P1_2: U3.46 (P1_2/TDI_CPU/SDL)
/P1_3: U3.47 (P1_3/TCK_CPU/SDA)
/P1_6: U3.41 (P1_6/PWM1)
/P2_3: U3.42 (P2_3)
/P2_6: U3.21 (P2_6)
/P2_7: U3.39 (P2_7)
/P3_2: U3.20 (P3_2)
/P3_4: U3.31 (P3_4/UART_RTS)
/P3_7: U3.48 (P3_7/UART_CTS)
/PWR(MFB): TP30.1, U3.26 (PWR(MFB))
/RFS1: U3.2 (RFS1)
/RGB_VDD: C600.1, C601.1, C602.1, C603.1, C604.1, C605.1, C606.1, C607.1, C608.1, C609.1, C610.1, C611.1, D600.3 (VDD), D601.3 (VDD), D602.3 (VDD), D603.3 (VDD), D604.3 (VDD), D605.3 (VDD), D606.3 (VDD), D607.3 (VDD), D608.3 (VDD), D609.3 (VDD), D610.3 (VDD), D611.3 (VDD), U6.1 (OUT)
/R_OUT: J81.5, U8.7 (OUTR)
/SCL: J10.13, J11.13, R41.1, U1.32 (PA23/I2C/I7/SERCOM3+5.1/SOF), U4.2 (SCL)
/SCLK: CN20.5 (SCLK), U1.20 (PB11/I11/SERCOM4.3/I2SCL), U2.28 (SCLK)
/SCLK1: U3.3 (SCLK1)
/SDA: J10.12, J11.12, R42.1, U1.31 (PA22/I2C/I6/SERCOM3+5.0), U4.3 (SDA)
/SK1_AMB_DET: U3.27 (SK1_AMB_DET)
/SK2_KEY_AD: U3.28 (SK2_KEY_AD)
/SWCLK: U1.45 (PA30/I10/SECOM1.2/SWCLK)
/SWDIO: U1.46 (PA31/I11/SECOM1.3/SWDIO)
/SYS_PWR: U3.24 (SYS_PWR)
/VDD_IO: U3.25 (VDD_IO)
/vs1053_LEFT: J10.1, J11.1, R80.1, R82.2, U2.46 (LEFT)
/vs1053_RIGHT: J10.2, J11.2, R81.1, R83.2, U2.39 (RIGHT)
/~RESET: C21.1, R20.2, SW1.1, SW1.3 (P1), U1.40 (/RESET), U2.3 (XRESET), U3.43 (RST_N)
GND: C10.2, C11.2, C12.2, C13.2, C21.2, C22.2, C23.2, C24.2, C30.2, C40.2, C41.2, C50.2, C51.1, C71.2, C72.2, C74.2, C75.2, C76.2, C77.2, C90.2, C91.2, C600.2, C601.2, C602.2, C603.2, C604.2, C605.2, C606.2, C607.2, C608.2, C609.2, C610.2, C611.2, CN20.6 (GND@3), CN20.MT1 (GND@2), CN20.MT2 (GND@1), CN70.5 (GND), CN70.6 (GND), CN70.BASE@2 (GND), CN70.GND, CN70.SPRT@1 (GND), CN70.SPRT@2 (GND), CN70.SPRT@3 (GND), CN70.SPRT@4 (GND), D10.1 (C), D600.1 (VSS), D601.1 (VSS), D602.1 (VSS), D603.1 (VSS), D604.1 (VSS), D605.1 (VSS), D606.1 (VSS), D607.1 (VSS), D608.1 (VSS), D609.1 (VSS), D610.1 (VSS), D611.1 (VSS), FB70.1, J10.19, J10.20, J11.19, J11.20, J80.3, R25.1, R26.1, R40.1, R50.2, R51.2, R70.2, R73.2, SW1.2 (S), SW1.4 (S1), TP73.1, U1.5 (GNDA), U1.18 (GND), U1.35 (GND), U1.42 (GND), U1.49 (GND), U1.THERMAL (GND), U2.4 (DGND@0), U2.16 (DGND@1), U2.20 (DGND@2), U2.21 (DGND@3), U2.22 (DGND@4), U2.35 (GND), U3.16 (GND), U3.50 (GND), U4.4 (ADDR), U4.6 (VSS), U5.2 (GND), U6.2 (GND), U9.5 (GND), U9.6 (GND), U9.7 (GND), U9.8 (GND), U70.2 (GND), U71.2 (GND), U72.2 (VSS)
GNDA: C20.2, C70.2, C80.2, C81.2, C84.2, C85.2, C89.2, C810.2, FB70.2, J10.5, J11.5, J80.4, J81.4, U2.37 (AGND@0), U2.40 (AGND@1), U2.41 (AGND@2), U2.47 (AGND@3), U8.6 (SGND), U8.11 (PGND), U8.13 (EP)
unnamed: C10.1, U1.43 (VDDCORE)
unnamed: C12.1, U1.1 (PA00/EINT0/SERCOM1.0), X10.P$1
unnamed: C13.1, U1.2 (PA01/EINT1/SERCOM1.1), X10.P$2
unnamed: C20.1, U2.44 (RCAP)
unnamed: C22.1, R22.1, U2.17 (XTALOUT), X20.1
unnamed: C23.1, R22.2, U2.18 (XTALIN), X20.2
unnamed: C41.1, U4.5 (VREG)
unnamed: C80.1, R80.2
unnamed: C81.1, R81.2
unnamed: C82.1, R82.1
unnamed: C82.2, C86.2, U8.3 (INL)
unnamed: C83.1, C87.2, U8.4 (INR)
unnamed: C83.2, R83.1
unnamed: C84.1, R84.2
unnamed: C85.1, R85.2
unnamed: C86.1, R86.1
unnamed: C87.1, R87.1
unnamed: C88.1, U8.1 (C1N)
unnamed: C88.2, U8.10 (C1P)
unnamed: C89.1, U8.2 (PVSS), U8.5 (VSS)
unnamed: CHG1.1 (C), U72.1 (STAT)
unnamed: CN70.1 (VBUS), D72.2 (A)
unnamed: D10.2 (A), R10.2
unnamed: D600.2 (DIN), R60.2
unnamed: D600.4 (DOUT), D601.2 (DIN)
unnamed: D601.4 (DOUT), D602.2 (DIN)
unnamed: D602.4 (DOUT), D603.2 (DIN)
unnamed: D603.4 (DOUT), D604.2 (DIN)
unnamed: D604.4 (DOUT), D605.2 (DIN)
unnamed: D605.4 (DOUT), D606.2 (DIN)
unnamed: D606.4 (DOUT), D607.2 (DIN)
unnamed: D607.4 (DOUT), D608.2 (DIN)
unnamed: D608.4 (DOUT), D609.2 (DIN)
unnamed: D609.4 (DOUT), D610.2 (DIN)
unnamed: D610.4 (DOUT), D611.2 (DIN)
unnamed: L50.1, U5.3 (SW)
unnamed: R21.1, U2.26 (RX)
unnamed: R40.2, U4.7 (REXT)
unnamed: R73.1, U72.5 (PROG)
VBUS: C30.1, C51.2, C71.1, D71.1 (C), D72.1 (C), J10.9, J10.10, J11.9, J11.10, TP70.1, U3.22 (ADAP_IN), U5.4 (VIN), U70.1 (IN), U70.3 (EN), U72.4 (VDD)
VDDA: C70.1, FB71.2, U2.38 (AVDD@0), U2.43 (AVDD@1), U2.45 (AVDD@2)

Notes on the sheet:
POWER AND FILTERING (7)
RED LED
Analog Supply Filtering
1.0K = 1000mA
Mezzanine connector
Caps: UKA0J471MPD1TD
transients during power up which can
TXLED
USB AND BATTERY CHARGING
POWER LED (5)
10K = 100mA
N/C
= 497µF
RXD
SAMD21 MCU (1)
free in FIFO
1 / (2*π*f*Xc)
'clicks' ... this setup should minimize
RGB LEDS (6)
that. See section 8 of
VS1053 oscillator requires
USBHOSTEN
Enabling the IC too soon can cause
AUDIO MUX (8)
DREQ high = at least 32 bytes
1 / (6.2832*20hz*16)
Disable SPI boot with GPIO0 low
TOUCH SLIDER (4)
SPI CS Pullups
MIC (9)
VS1053B AUDIO CODEC (2)
damage the earphones and causes
BM83 BTM (3)
1 / (6.2832*20hz*32)
1M resistor for DC bias
32 ohm load at 20Hz cuttoff
16 ohm load at 20Hz cuttoff
2.0K = 500mA
3.3v supply
vs1053 1.8v supply



Board: 4 copper layers, 65.0 x 40.0 mm, 121 parts (59 on the bottom side), 89 nets.

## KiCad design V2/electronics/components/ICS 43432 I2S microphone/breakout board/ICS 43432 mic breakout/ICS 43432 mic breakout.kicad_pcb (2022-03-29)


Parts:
C1: 10uf; C_0603_1608Metric_Pad1.08x0.95mm_HandSolder
J1: Conn_01x07; PinHeader_1x07_P2.54mm_Vertical
U1: ICS-43432; ICS_43432

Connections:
unnamed: C1.1, J1.3, U1.3 (VDD)
unnamed: C1.2, J1.4, U1.4 (GND)
unnamed: J1.1, U1.1 (LR_sel)
unnamed: J1.2, U1.2 (config)
unnamed: J1.5, U1.5 (LRCLK)
unnamed: J1.6, U1.6 (BCLK)
unnamed: J1.7, U1.7 (DATA)


Board: 2 copper layers, 10.8 x 20.0 mm, 3 parts (1 on the bottom side), 7 nets.

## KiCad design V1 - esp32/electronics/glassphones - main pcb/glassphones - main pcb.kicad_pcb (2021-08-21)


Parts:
BOOT1: SW_Push; TL3365_button
Ba1: SW_Push_45deg; TL3365_button
Bb1: SW_Push_45deg; TL3365_button
Bd1: SW_Push_45deg; TL3365_button
Bl1: SW_Push_45deg; TL3365_button
Br1: SW_Push_45deg; TL3365_button
Bu1: SW_Push_45deg; TL3365_button
C1: 470nf; C_0603_1608Metric
C2: 2.2uf; C_0603_1608Metric
C3, C4, C5, C6, C7, C8, C9: 1uf; C_0603_1608Metric
D1: PWR; LED_0603_1608Metric
D2: CON; LED_0603_1608Metric
D3: Play; LED_0603_1608Metric
D4: Menu; LED_0603_1608Metric
D5: CHRG; LED_0603_1608Metric
J1: USB_B_Micro; USB_Micro-B_Molex-105017-0001
J2: DM3D-SF
J3: Raudio; TestPoint_Pad_D1.5mm
J4: GNDA; TestPoint_Pad_D1.5mm
J5: Conn_01x05_Female; Hirose_DF52-5S-0.8H_1x05-1MP_P0.80mm_Horizontal
NT1: Net-Tie_2; NetTie-2_SMD_Pad0.5mm
R1, R5, R6, R7: 10k; R_0603_1608Metric
R2: 10k X 4; EXB-38V103JV
R3: 470k; R_0603_1608Metric
R4: 180k; R_0603_1608Metric
R8, R9, R10, R11, R12: 330; R_0603_1608Metric
RST1: SW_Push; TL3365_button
U1: TinyPICO_Nano
U2: max9850eti+; max9850eti&plus_
U3: ICS-43432; ICS_43432

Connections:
+3V3: C6.1, C7.1, C8.1, C9.1, J2.4 (VDD), R5.2, R6.2, R7.2, U1.8 (3v3), U2.4 (DVDD), U2.17 (AVDD), U2.26 (PVDD), U3.1 (LR_sel), U3.3 (VDD)
BAT_sense: R3.2, R4.1, U1.36 (IO36)
BCLK: U1.17 (IO26), U2.2 (BCLK), U3.6 (BCLK)
BOOT+SD_PULLUP: BOOT1.2, R1.1, R2.5 (R4.2), R2.6 (R3.2), R2.7 (R2.2), R2.8 (R1.2), U1.29 (IO0)
Bcol1: Bl1.1, Bu1.1, R5.1, U1.35 (IO37)
Bcol2: Bb1.1, Bd1.1, R6.1, U1.34 (IO38)
Bcol3: Ba1.1, Br1.1, R7.1, U1.33 (IO39)
DAC_DATA: U1.23 (IO23), U2.3 (SDIN)
GND: BOOT1.1, C2.2, C7.2, C8.2, C9.2, J1.5 (GND), J1.6 (Shield), J2.6 (VSS), J2.9, J2.10, J2.11, J2.12, J2.13, J2.14, J5.1, J5.MP, NT1.1, R4.2, RST1.1, U1.2 (GND), U2.6 (DGND), U2.7 (ADD), U2.24 (PGND), U2.29 (EP), U3.2 (config), U3.4 (GND)
GNDA: C3.1, C4.1, C5.1, C6.2, J4.1, J5.2, NT1.2, U2.14 (AGND)
LRCLK: U1.16 (IO27), U2.1 (LRCLK), U3.5 (LRCLK)
L_Audio: J5.3, U2.19 (HPL)
Lcol1: D1.2 (A), D3.2 (A), U1.18 (IO25)
Lcol2: D2.2 (A), D4.2 (A), U1.19 (IO32)
MCLK: U1.28 (IO21), U2.5 (MCLK)
MIC_DATA: U1.27 (IO22), U3.7 (DATA)
unnamed: C1.1, U2.25 (C1P)
unnamed: C1.2, U2.23 (C1N)
unnamed: C2.1, U2.20 (SVSS), U2.22 (PVSS)
unnamed: C3.2, U2.15 (NREG)
unnamed: C4.2, U2.16 (PREG)
unnamed: C5.2, U2.13 (REF)
unnamed: D1.1 (K), R8.2
unnamed: D2.1 (K), R9.2
unnamed: D3.1 (K), R10.2
unnamed: D4.1 (K), R11.2
unnamed: D5.1 (K), R12.2
unnamed: R12.1, U1.1 (STAT)
RST: RST1.2, U1.3 (RESET), U1.7 (EN)
R_Audio: J3.1, U2.18 (HPR)
SCL: U1.24 (IO19), U2.27 (SCL)
SDA: U1.25 (IO18), U2.28 (SDA)
SD_CLK: J2.5 (CLK), U1.14 (IO14)
SD_CMD: J2.3 (CMD), R1.2, U1.15 (IO15)
SD_DAT0: J2.7 (DAT0), R2.1 (R1.1), U1.10 (IO2)
SD_DAT1: J2.8 (DAT1), R2.2 (R2.1), U1.11 (IO4)
SD_DAT2: J2.1 (DAT2), R2.3 (R3.1), U1.12 (IO12)
SD_DAT3: J2.2 (DAT3), R2.4 (R4.1), U1.13 (IO13)
V_BAT: J5.5, R3.1, U1.9 (VBAT)
row1: Bd1.2, Br1.2, Bu1.2, R8.1, R9.1, U1.26 (IO5)
row2: Ba1.2, Bb1.2, Bl1.2, R10.1, R11.1, U1.30 (IO9)
usb_5v: D5.2 (A), J1.1 (VBUS), U1.4 (5V)
usb_d+: J1.3 (D+), U1.6 (D+)
usb_d-: J1.2 (D-), U1.5 (D-)

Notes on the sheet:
25/07/2021
Glassphones main PCB
Buttons and Lights
Connectors
SD card
Maxim9850eti+ audio DAC AMP



Board: 2 copper layers, 57.5 x 21.8 mm, 43 parts (22 on the bottom side), 44 nets.

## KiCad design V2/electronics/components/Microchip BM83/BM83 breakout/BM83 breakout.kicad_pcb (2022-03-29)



Board: 2 copper layers, 65.0 x 32.0 mm, 10 parts (2 on the bottom side), 49 nets.

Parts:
D1: LED1; LED_0603_1608Metric_Pad1.05x0.95mm_HandSolder
D2: LED2; LED_0603_1608Metric_Pad1.05x0.95mm_HandSolder
J1, J2: Conn_01x25; PinHeader_1x25_P2.54mm_Vertical
J3: USB_B_Micro; USB_Micro-B_Molex-105017-0001
JP1: Jumper_NO_Small; PinHeader_1x02_P2.54mm_Vertical
MFB: PWR MFB; TL3365_button
R1: 4R7; R_0603_1608Metric_Pad0.98x0.95mm_HandSolder
RST: RESET; TL3365_button
U1: BM83

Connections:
/ADAP_IN: J1.22, J3.1, U1.22
/AIL: J1.12, U1.12
/AIR: J1.11, U1.11
/AOHPL: J1.8, U1.8
/AOHPM: J1.7, U1.7
/AOHPR: J1.6, U1.6
/BAT_IN: J1.23, U1.23
/DMIC1_CLK: J1.17, U1.17
/DMIC1_L: J1.19, U1.19
/DMIC1_R: J1.18, U1.18
/DN: J2.15, J3.2, U1.36
/DP: J2.14, J3.3, U1.37
/DR1: J1.1, U1.1
/DT1: J1.4, U1.4
/LED1: D1.1, J2.19, U1.32
/LED2: D2.1, J2.17, U1.34
/MCLK1: J1.5, U1.5
/MICBIAS: J1.15, U1.15
/MICN1: J1.13, U1.13
/MICN2: J1.9, U1.9
/MICP1: J1.14, U1.14
/MICP2: J1.10, U1.10
/P0_0: J2.2, U1.49
/P0_1: J2.7, U1.44
/P0_2: J2.18, U1.33
/P0_3: J2.13, U1.38
/P0_5: J2.11, U1.40
/P0_6: J2.16, U1.35
/P0_7: J2.6, U1.45
/P1_2: J2.5, U1.46
/P1_3: J2.4, U1.47
/P1_6: J2.10, U1.41
/P2_3: J2.9, U1.42
/P2_6: J1.21, U1.21
/P2_7: J2.12, U1.39
/P3_2: J1.20, U1.20
/P3_4: J2.20, JP1.2, U1.31
/P3_7: J2.3, U1.48
/P8_5: J2.21, U1.30
/P8_6: J2.22, U1.29
/PWR(MFB): J2.25, MFB.1, U1.26
/RFS1: J1.2, U1.2
/RST_N: J2.8, R1.2, RST.2, U1.43
/SCLK1: J1.3, U1.3
/SK1_AMB_DET: J2.24, U1.27
/SK2_KEY_AD: J2.23, U1.28
/SYS_PWR: D1.2, D2.2, J1.24, MFB.2, U1.24
/VDD_IO: J1.25, R1.1, U1.25
GND: J1.16, J2.1, J3.4, J3.5, J3.6, JP1.1, RST.1, U1.16, U1.50

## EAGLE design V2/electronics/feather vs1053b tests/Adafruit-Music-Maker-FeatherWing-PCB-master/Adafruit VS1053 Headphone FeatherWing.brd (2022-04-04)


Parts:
C1, C2: 220uF; PANASONIC_C
C3: 1uF; 0603-NO
C4, C5: 22pF; 0603-NO
C6: 10µF; _0805MP
C8, C19: 1µF; 0603-NO
C20: 10µF; 0805-NO
C21, C22: 10nF; 0603-NO
C26: 0.1µF; 0603-NO
CN1: 2908-05WB-M6; MICROSD
FB1, FB2: FERITTE; 0805-NO
FID1, FID2: FIDUCIAL""; FIDUCIAL_1MM
JP1: HEADER-1X12; 1X12_ROUND
JP2, JP4: HEADER-1X2ROUND; 1X02_ROUND
JP3: HEADER-1X13; 1X13_ROUND_70
JP5: HEADER-1X1ROUND; 1X01_ROUND
MIDI: SOLDERJUMPER; SOLDERJUMPER_ARROW_NOPASTE
MS1: FEATHERWING_NODIM
R1: 1M; 0603-NO
R2: 100K; 0603-NO
R3, R4: 22; 0603-NO
R6, R7: 100; 0603-NO
R16: 100K; RESPACK_4X0603
RST: SOLDERJUMPERCLOSED; SOLDERJUMPER_CLOSEDWIRE
SW1: KMR2; BTN_KMR2_4.6X2.8
U1: VS1053B; LQFP48
U2: AP7312-1833W6-7; SOT23-6
X1: AUDIO_3.5MMJACK_4POL; 4UCONN_18510
Y1: ABM8G-12.288MHZ-4Y-T3; CRYSTAL_3.2X2.5

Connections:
1.8V: C6.1, U1.5 (CVDD), U1.7 (CVDD), U1.24 (CVDD), U1.31 (CVDD), U2.6 (VOUT1)
3.3V: C19.1, C20.1, CN1.4 (SD_VDD), FB1.1, MIDI.1, MS1.2 (3V), R16.7 (2), R16.8 (2), U1.6 (IOVDD), U1.14 (IOVDD), U1.19 (IOVDD), U1.32 (XTEST), U2.1 (VOUT2), U2.3 (EN2), U2.4 (EN1), U2.5 (VIN)
!RESET: MS1.1 (!RESET), RST.2, SW1.B (S), SW1.B' (S1)
AGND: C3.2, C8.2, C21.2, C22.2, FB2.2, JP2.2, JP4.2, SW1.A, SW1.A' (P1), U1.37 (AGND), U1.40 (AGND), U1.41 (AGND), U1.47 (AGND), X1.1-GND (TIP)
AVDD: C8.1, FB1.2, R2.1, U1.38 (AVDD), U1.43 (AVDD), U1.45 (AVDD)
CLKOUT: U1.15 (VCO)
DREQ: JP1.8, MS1.21 (GPIO9), U1.8 (DREQ)
GND: C4.2, C5.2, C6.2, C19.2, C20.2, C26.2, CN1.6 (GND), CN1.MT1 (GND), CN1.MT2 (GND), FB2.1, JP3.13, MS1.4 (GND), R16.5 (2), R16.6 (2), U1.4 (DGND), U1.16 (DGND), U1.20 (DGND), U1.21 (DGND), U1.22 (DGND), U1.35 (GND), U2.2 (GND)
GPIO0: R16.4 (1), U1.33 (GPIO0)
GPIO1: MIDI.2, R16.3 (1), U1.34 (GPIO1)
LEFT: R3.1, R7.2, U1.46 (LEFT)
LEFT_FILTERED: C2.+, R7.1
L_OUT: C2.-, JP4.1, X1.2-TIP (RING3)
MISO: CN1.7 (DATA_OUT), JP3.4, MS1.13 (GPIOMISO), U1.30 (SO)
MOSI: CN1.3 (DATA_IN), JP3.5, MS1.12 (GPIOMOSI), U1.29 (SI)
MP3CS: JP1.9, MS1.20 (GPIO6), R16.2 (1), U1.23 (XCS)
MP3RST: C26.1, JP5.1, R2.2, RST.1, U1.3 (XRESET)
MP3_RX: JP3.2, MS1.15 (GPIOTX), U1.26 (RX)
unnamed: C5.1, R1.1, U1.17 (XTALOUT), Y1.1
unnamed: C4.1, R1.2, U1.18 (XTALIN), Y1.2
unnamed: C3.1, U1.44 (RCAP)
unnamed: JP1.2, MS1.27 (EN)
unnamed: C21.1, R3.2
unnamed: C22.1, R4.2
unnamed: JP1.4, MS1.25 (GPIO13)
unnamed: JP1.5, MS1.24 (GPIO12)
unnamed: JP1.6, MS1.23 (GPIO11)
unnamed: JP1.11, MS1.18 (GPIOSCL)
unnamed: JP1.12, MS1.17 (GPIOSDA)
unnamed: JP3.1, MS1.16 (NC)
unnamed: JP3.3, MS1.14 (GPIORX)
unnamed: JP3.7, MS1.10 (GPIOA5)
unnamed: JP3.8, MS1.9 (GPIOA4)
unnamed: JP3.9, MS1.8 (GPIOA3)
unnamed: JP3.10, MS1.7 (GPIOA2)
unnamed: JP3.11, MS1.6 (GPIOA1)
unnamed: JP3.12, MS1.5 (GPIOA0)
RIGHT: R4.1, R6.2, U1.39 (RIGHT)
RIGHT_FILTERED: C1.+, R6.1
R_OUT: C1.-, JP2.1, X1.3-OUTER_SLEEVE (RING2)
SCLK: CN1.5 (SCLK), JP3.6, MS1.11 (GPIOSCK), U1.28 (SCLK)
SD_CS: CN1.2 (CS), JP1.10, MS1.19 (GPIO5), R16.1
TX: U1.27 (TX)
USB: JP1.3, MS1.26 (USB)
VBAT: JP1.1, MS1.28 (VBAT)
XDCS: JP1.7, MS1.22 (GPIO10), U1.13 (XDCS/BSYNC)

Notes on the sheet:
Analog Supply Filtering
C4,C5 = 2*CL - 2*Cstray
C4,C5 = 2*10pF - 2*5pF
C4,C5 = 10pF
VS1053 oscillator requires
1M resistor for DC bias
DREQ high = at least 32 bytes
Power Supply/Decoupling
transients during power up which can
damage the earphones and causes
'clicks' ... this setup should minimize
that. See section 8 of
http://www.vlsi.fi/uploads/media/vs10XXan.pdf
Enabling the IC too soon can cause
free in FIFO
Disable SPI boot with GPIO0 low
1 / (2*π*f*Xc)
16 ohm load at 20Hz cuttoff
1 / (6.2832*20hz*16)
C1, C2 =
= 497µF
32 ohm load at 20Hz cuttoff
1 / (6.2832*20hz*32)
= 249µF
Caps: UKA0J471MPD1TD



Board: 2 copper layers, 50.8 x 22.9 mm, 41 parts (5 on the bottom side), 44 nets.

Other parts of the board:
U$36: ADAFRUIT_3.5MM
U$37: FEATHERLOGO_SMALL
U$43: PCBFEAT-REV-040
U$55: ADAFRUIT_TEXT_20MM

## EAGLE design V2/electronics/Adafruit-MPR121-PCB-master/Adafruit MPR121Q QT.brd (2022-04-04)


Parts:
C4, C7: 0.1uF; 0603-NO
C5, C6: 10uF; 0805-NO
CONN3, CONN4: STEMMA_I2C_QT; JST_SH4
D1: RED; CHIPLED_0603_NOOUTLINE
D2: GREEN; CHIPLED_0603_NOOUTLINE
FID3, FID4: FIDUCIAL_1MM
JP1: HEADER-1X13; 1X13_ROUND_70
JP2: HEADER-1X770MIL; 1X07_ROUND_70
Q3: BSS138; SOT363
R1, R6, R9: 10K; 0603-NO
R5: 75K; 0603-NO
R7: 1K; 0603-NO
R8: 10K; RESPACK_4X0603
SJ1: SOLDERJUMPER; SOLDERJUMPER_ARROW_NOPASTE
U1: MPR121; QFN20_3MM_NOTHERMAL
U2: AP2112K-3.3; SOT23-5
U$34, U$35: MOUNTINGHOLE2.5; MOUNTINGHOLE_2.5_PLATED

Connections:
3.3V: C6.1, C7.1, JP2.2, Q3.2 (G), Q3.5 (G), R1.2, R7.2, R8.2 (1), R8.4 (1), R9.1, SJ1.1, U1.20 (VDD), U2.5 (OUT)
ADDR: JP2.7, R6.2, SJ1.2, U1.4 (ADDR)
ELEC0: JP1.12, U1.8 (ELE0)
ELEC1: JP1.11, U1.9 (ELE1)
ELEC2: JP1.10, U1.10 (ELE2)
ELEC3: JP1.9, U1.11 (ELE3)
ELEC4: JP1.8, U1.12 (ELE4/LED0)
ELEC5: JP1.7, U1.13 (ELE5/LED1)
ELEC6: JP1.6, U1.14 (ELE6/LED2)
ELEC7: JP1.5, U1.15 (ELE7/LED3)
ELEC8: JP1.4, U1.16 (ELE8/LED4)
ELEC9: JP1.3, U1.17 (ELE9/LED5)
ELEC10: JP1.2, U1.18 (ELE10/LED6)
ELEC11: JP1.1, U1.19 (ELE11/LED7)
GND: C4.2, C5.2, C6.2, C7.2, CONN3.1 (GND), CONN3.MT1 (MT), CONN3.MT2 (MT), CONN4.1 (GND), CONN4.MT1 (MT), CONN4.MT2 (MT), D2.C, JP1.13, JP2.3, R5.1, R6.1, U1.6 (VSS), U2.2 (GND)
INT: D1.C, JP2.6, R1.1, U1.1 (#IRQ)
unnamed: D1.A, R7.1
unnamed: C4.1, U1.5 (VREG)
unnamed: R5.2, U1.7 (REXT)
unnamed: D2.A, R9.2
SCL: CONN3.4 (SCL), CONN4.4 (SCL), JP2.4, Q3.6 (D), R8.8 (2)
SCL_3V: Q3.1 (S), R8.7 (2), U1.2 (SCL)
SDA: CONN3.3 (SDA), CONN4.3 (SDA), JP2.5, Q3.3 (D), R8.6 (2)
SDA_3V: Q3.4 (S), R8.5 (2), U1.3 (SDA)
VCC: C5.1, CONN3.2 (V+), CONN4.2 (V+), JP2.1, R8.1, R8.3 (1), U2.1 (IN), U2.3 (EN)

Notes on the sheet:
I2C Pullups & Shift
STEMMA/I2C Headers
ON LED
Power supply



Board: 2 copper layers, 33.0 x 19.2 mm, 28 parts (3 on the bottom side), 25 nets.

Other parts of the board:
U$9: PCBFEAT-REV-040
U$37: ADAFRUIT_3.5MM
U$39, U$40: STEMMAQT

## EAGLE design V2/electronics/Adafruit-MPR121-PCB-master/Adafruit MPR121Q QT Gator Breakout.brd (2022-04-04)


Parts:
C4, C7: 0.1uF; 0603-NO
C5, C6: 10uF; 0805-NO
CONN3, CONN4: STEMMA_I2C_QT; JST_SH4
D1: RED; CHIPLED_0603_NOOUTLINE
D2: GREEN; CHIPLED_0603_NOOUTLINE
FID3, FID4: FIDUCIAL_1MM
Q3: BSS138; SOT363
R5: 75K; 0603-NO
R6: 100K; 0603-NO
R7, R9: 10K; 0603-NO
R8: 10K; RESPACK_4X0603
SJ1: SOLDERJUMPER; SOLDERJUMPER_ARROW_NOPASTE
TP1, TP2, TP3, TP4, TP5, TP6, TP7, TP8, TP9, TP10, TP11, TP12: SEWTAPPCB_ALLIGATOR; PCB_ALLI
U1: MPR121; QFN20_3MM_NOTHERMAL
U2: AP2112K-3.3; SOT23-5
U$7, U$8, U$34, U$35: MOUNTINGHOLE2.5; MOUNTINGHOLE_2.5_PLATED

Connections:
3.3V: C6.1, C7.1, Q3.2 (G), Q3.5 (G), R7.2, R8.2 (1), R8.4 (1), R9.1, SJ1.1, U1.20 (VDD), U2.5 (OUT)
ADDR: R6.2, SJ1.2, U1.4 (ADDR)
ELEC0: TP2.P$1, U1.8 (ELE0)
ELEC1: TP3.P$1, U1.9 (ELE1)
ELEC2: TP4.P$1, U1.10 (ELE2)
ELEC3: TP5.P$1, U1.11 (ELE3)
ELEC4: TP12.P$1, U1.12 (ELE4/LED0)
ELEC5: TP11.P$1, U1.13 (ELE5/LED1)
ELEC6: TP10.P$1, U1.14 (ELE6/LED2)
ELEC7: TP9.P$1, U1.15 (ELE7/LED3)
ELEC8: TP8.P$1, U1.16 (ELE8/LED4)
ELEC9: TP7.P$1, U1.17 (ELE9/LED5)
ELEC10: TP6.P$1, U1.18 (ELE10/LED6)
ELEC11: TP1.P$1, U1.19 (ELE11/LED7)
GND: C4.2, C5.2, C6.2, C7.2, CONN3.1 (GND), CONN3.MT1 (MT), CONN3.MT2 (MT), CONN4.1 (GND), CONN4.MT1 (MT), CONN4.MT2 (MT), D2.C, R5.1, R6.1, U1.6 (VSS), U2.2 (GND)
INT: D1.C, U1.1 (#IRQ)
unnamed: D1.A, R7.1
unnamed: C4.1, U1.5 (VREG)
unnamed: R5.2, U1.7 (REXT)
unnamed: D2.A, R9.2
SCL: CONN3.4 (SCL), CONN4.4 (SCL), Q3.6 (D), R8.8 (2)
SCL_3V: Q3.1 (S), R8.7 (2), U1.2 (SCL)
SDA: CONN3.3 (SDA), CONN4.3 (SDA), Q3.3 (D), R8.6 (2)
SDA_3V: Q3.4 (S), R8.5 (2), U1.3 (SDA)
VCC: C5.1, CONN3.2 (V+), CONN4.2 (V+), R8.1, R8.3 (1), U2.1 (IN), U2.3 (EN)

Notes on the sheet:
I2C Pullups & Shift
STEMMA/I2C Headers
ON LED
Power supply



Board: 2 copper layers, 50.8 x 25.4 mm, 39 parts (2 on the bottom side), 25 nets.

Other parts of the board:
U$10: PCBFEAT-REV-040
U$37: ADAFRUIT_3.5MM
U$39, U$40: STEMMAQT

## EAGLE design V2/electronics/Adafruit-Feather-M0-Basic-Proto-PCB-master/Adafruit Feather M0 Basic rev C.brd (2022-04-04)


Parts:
C1, C7, C14: 1uF; 0603-NO
C2, C4: 22pF; 0603-NO
C3, C6, C8: 10µF; 0805-NO
C5: 10uF; 0805-NO
CHG: ORANGE; CHIPLED_0805_NOOUTLINE
D1: MBR120; SOD-123
JP1: HEADER-1X16ROUND; 1X16_ROUND
JP3: HEADER-1X12; 1X12_ROUND
L: RED; CHIPLED_0805_NOOUTLINE
R1, R3: 100k; 0603-NO
R2: 1K; 0603-NO
R6: 100K; 0603-NO
R7: 2.2K; 0603-NO
R8: 10K\; 0603-NO
SW1: SPST_TACT-KMR2; KMR2
TP1, TP2: TESTPOINTROUND1.5MM; TESTPOINT_ROUND_1.5MM
U2: SPX3819-3.3; SOT23-5
U3: MCP73831T-2ACI/OT; SOT23-5
U$4: ATSAMD21G18_QFN; TQFN48_7MM
U$31, U$32: MOUNTINGHOLE2.5; MOUNTINGHOLE_2.5_PLATED
U$34, U$35: FIDUCIAL""; FIDUCIAL_1MM
X1: JSTPH; JSTPH2
X2: 32.768; XTAL3215
X3: microUSB; 4UCONN_20329_V2

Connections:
!RESET: JP1.16, SW1.1, SW1.3 (P1), U$4.40 (/RESET)
+3V3: C5.1, C7.1, C8.1, JP1.15, U2.5 (OUT), U$4.6 (VDDA), U$4.17 (VDDIO), U$4.36 (VDDIO), U$4.44 (VDDIN)
A0: JP1.12, U$4.3 (PA02/EINT2/AIN0/Y0/VOUT)
A1: JP1.11, U$4.7 (PB08/I8/AIN2/SERCOM4.0)
A2: JP1.10, U$4.8 (PB09/I9/AIN3/SERCOM4.1)
A3: JP1.9, U$4.9 (PA04/EINT4/VREFB/AIN4/SERCOM0.0)
A4: JP1.8, U$4.10 (PA05/EINT5/AIN5/SERCOM0.1)
A5: JP1.7, U$4.47 (PB02/I2/AIN10/SERCOM5.0)
AREF: C14.1, JP1.14, U$4.4 (PA03/EINT3/VREFA/AIN1)
D0: JP1.3, U$4.16 (PA11/I11/AIN19/SERCOM0+2.3/I2SF0)
D1: JP1.2, U$4.15 (PA10/I10/AIN18/SERCOM0+2.2/I2SCK)
D2: U$4.23 (PA14/I14/SERCOM2+4.2)
D3: U$4.14 (PA09/I2C/I9/AIN17/SERCOM0+2.1/I2SMC)
D4: U$4.13 (PA08/I2C/AIN16/SERCOM0+2.0/I2SD1)
D5: JP3.10, U$4.24 (PA15/I15/SERCOM3+4.3)
D6: JP3.9, U$4.29 (PA20/I4/SERCOM3+5.2/I2SSC)
D7: U$4.30 (PA21/I5/SERCOM3+5.3/I2SFS0)
D8: U$4.11 (PA06/EINT6/AIN6/SERCOM0.2)
D9: JP3.8, R3.2, R6.1, U$4.12 (PA07/I7/AIN7/SERCOM0.3/I2SD0)
D10: JP3.7, U$4.27 (PA18/I2/SERCOM1+3.2)
D11: JP3.6, U$4.25 (PA16/I2C/I0/SERCOM1+3.0)
D12: JP3.5, U$4.28 (PA19/I3/SERCOM1+3.3/I2SD0)
D13: JP3.4, R7.1, U$4.26 (PA17/I2C/I1/SERCOM1+3.1)
D+: U$4.34 (PA25/I13/SERCOM3+5.3/D+), X3.D+
D-: U$4.33 (PA24/I12/SERCOM3+5.2/D-), X3.D-
EN: JP3.2, R1.2, U2.3 (EN)
GND: C1.2, C2.2, C3.2, C4.2, C5.2, C6.2, C7.2, C8.2, C14.2, JP1.1, JP1.13, L.C, R6.2, R8.2, SW1.2 (S), SW1.4 (S1), U2.2 (GND), U3.2 (VSS), U$4.5 (GNDA), U$4.18 (GND), U$4.35 (GND), U$4.42 (GND), U$4.THERMAL (GND), X1.1, X3.BASE@1 (GND), X3.BASE@2 (GND), X3.GND, X3.SPRT@1 (GND), X3.SPRT@2 (GND), X3.SPRT@3 (GND), X3.SPRT@4 (GND)
MISO: JP1.4, U$4.21 (PA12/I12/I2C/SERCOM2+4.0)
MOSI: JP1.5, U$4.19 (PB10/I10/SERCOM4.2/I2SMC)
unnamed: CHG.C, R2.1
unnamed: L.A, R7.2
unnamed: R2.2, U3.1 (STAT)
unnamed: R8.1, U3.5 (PROG)
unnamed: C2.1, U$4.1 (PA00/EINT0/SERCOM1.0), X2.P$1
unnamed: C4.1, U$4.2 (PA01/EINT1/SERCOM1.1), X2.P$2
SCK: JP1.6, U$4.20 (PB11/I11/SERCOM4.3/I2SCL)
SCL: JP3.11, U$4.32 (PA23/I2C/I7/SERCOM3+5.1/SOF)
SDA: JP3.12, U$4.31 (PA22/I2C/I6/SERCOM3+5.0)
SWCLK: TP1.P$1, U$4.45 (PA30/I10/SECOM1.2/SWCLK)
SWDIO: TP2.P$1, U$4.46 (PA31/I11/SECOM1.3/SWDIO)
VBAT: C3.1, D1.A, JP3.1, R3.1, U3.3 (VBAT), X1.2
VBUS: C6.1, CHG.A, D1.C, JP3.3, R1.1, U2.1 (IN), U3.4 (VDD), X3.VBUS
VDDCORE: C1.1, U$4.43 (VDDCORE)

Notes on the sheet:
POWER AND FILTERING
RESET
10K = 100mA
5.0K = 200mA
2.0K = 500mA
1.0K = 1000mA
N/C
TXLED
USBHOSTEN
RXLED
TXD
RXD
USB AND BATTERY CHARGING
BREAKOUTS
RED LED



Board: 2 copper layers, 50.8 x 22.9 mm, 37 parts (5 on the bottom side), 38 nets.

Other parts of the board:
U$7, U$12: ADAFRUIT_3.5MM
U$9: FEATHERLOGO
U$13: PCBFEAT-REV-040

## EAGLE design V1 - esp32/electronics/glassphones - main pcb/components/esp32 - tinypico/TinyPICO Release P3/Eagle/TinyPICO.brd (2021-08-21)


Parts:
C1, C2, C6, C14: 0.1uF; _0402MP
C3, C10: 10µF; _0603MP
C4: 0.75pF; _0402MP
C5: 1.5pF; _0402MP
C7, C12: 1µF; _0402MP
CHRG: TP4065-4.2V-SOT25-R; SOT23-5
D1: RED; 0402.LED
D3: ORANGE; 0402.LED
D4: BAT60J; SOD323_ST
IC2: CP2104; MICROBUILDER_QFN24_4MM_SMSC
J1, J3: TINYPICO_HEADER_10NO_SILK_PTH_FEMALE; 1X10_NO_SILK
JST-LIPO: LIPO; JSTPH2
L1: 7.5nH; RESC0402_N
LED1: AP102-2020; MICROBUILDER_APA102_2020
LOGO1: OSHW-LOGOS; OSHW-LOGO-S
LY68L6400SLIT: PSRAM0; SOP8
PDTA143TMB,315: TINYPICO-PNPAMB; SOT883(B)
PICO-D4: ESP32-PICO-D4; PICO-D4-QFN48
Q3: MUN5214DW1T1G; DUAL_NPN_SC70-6
R1, R8: 2K; _0402MP
R3: 3K3; _0402MP
R4: 10K; _0402MP
R5, R12: 100K; _0402MP
R6: 442K; _0402MP
R7: 160K; _0402MP
T2: TINYPICO-P-FETKMB; SOT883(B)
U1: NCP170AMX300TCG; VREG_NCP170AMX300TCG
U$8: PRO-OB-440
USB: C40942; USB-B-MICRO-SMD

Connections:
3.3V: C1.1, C12.1, J1.4, PDTA143TMB,315.2 (E), PICO-D4.1 (VDDA), PICO-D4.3 (VDDA3P3_1), PICO-D4.4 (VDDA_3P3), PICO-D4.19 (VDD3P3_RTC), PICO-D4.37 (VDD3P3_CPU), PICO-D4.43 (VDDA_2), PICO-D4.46 (VDDA_3), R4.2, R5.2, U1.1 (OUT)
3V: IC2.5 (VIO), IC2.6 (VDD)
ANT: C5.2, L1.2, U$8.FEED
CLK: LY68L6400SLIT.6 (SCLK), PICO-D4.31 (CLK)
D+: IC2.3 (D+), USB.D+
D-: IC2.4 (D-), USB.D-
DTR: IC2.23 (DTR), Q3.1 (E), Q3.5 (B)
GND: C1.2, C2.2, C3.2, C4.2, C6.2, C7.2, C10.1, C12.2, C14.2, CHRG.2 (VSS), D1.P$2 (2), IC2.2 (GND), IC2.THERM (TP), J1.2, J3.10, JST-LIPO.1, JST-LIPO.SHLD1, JST-LIPO.SHLD2, L1.1, LED1.4 (GND), LY68L6400SLIT.4 (GND), PICO-D4.EXP (GNDPAD), R3.2, R7.2, R12.2, U1.2 (GND), U1.5 (EXP), U$8.GND, USB.GND, USB.P$1 (SHIELD1), USB.P$2 (SHIELD2), USB.SHIELD3 (SHIELD)
GPIO0: PICO-D4.23 (IO0), Q3.6 (C)
GPIO2: LED1.6 (DI), PICO-D4.22 (IO2)
GPIO4: J1.5, PICO-D4.24 (IO4)
GPIO5: J3.4, PICO-D4.34 (IO5)
GPIO7: LY68L6400SLIT.3 (SIO2), PICO-D4.32 (SD0)
GPIO8: LY68L6400SLIT.5 (SIO0), PICO-D4.33 (SD1)
GPIO9: PICO-D4.28 (SD2)
GPIO10: LY68L6400SLIT.1 (CE), PICO-D4.29 (SD3)
GPIO11: LY68L6400SLIT.7 (SIO3), PICO-D4.30 (CMD)
GPIO12: LED1.5 (CKI), PICO-D4.18 (IO12)
GPIO13: PDTA143TMB,315.1 (B), PICO-D4.20 (IO13), R5.1
GPIO14: J1.6, PICO-D4.17 (IO14)
GPIO15: J1.7, PICO-D4.21 (IO15)
GPIO16: PICO-D4.25 (IO16)
GPIO17: LY68L6400SLIT.2 (SIO1), PICO-D4.27 (IO17)
GPIO18: J3.3, PICO-D4.35 (IO18)
GPIO19: J3.2, PICO-D4.38 (IO19)
GPIO21: J3.6, PICO-D4.42 (IO21)
GPIO22: J3.5, PICO-D4.39 (IO22)
GPIO23: J3.1, PICO-D4.36 (IO23)
GPIO25: J1.10, PICO-D4.14 (IO25)
GPIO26: J1.9, PICO-D4.15 (IO26)
GPIO27: J1.8, PICO-D4.16 (IO27)
GPIO32: J3.7, PICO-D4.12 (IO32)
GPIO33: J3.8, PICO-D4.13 (IO33)
GPIO35: PICO-D4.11 (IO35), R6.2, R7.1
LNA_IN: C4.1, C5.1, PICO-D4.2 (LNA_IN)
unnamed: D1.P$1 (1), R8.2
unnamed: D3.P$1 (1), R1.2
unnamed: LED1.3 (VDD), PDTA143TMB,315.3 (C)
PROG: CHRG.5 (PROG), R3.1
RESET: C2.1, J3.9, PICO-D4.9 (EN), Q3.3 (C), R4.1
RTS: IC2.19 (RTS), Q3.2 (B), Q3.4 (E)
RXD: IC2.21 (TXD), PICO-D4.40 (U0RXD)
SENS_CAPN: PICO-D4.7 (SENSOR_CAPN)
SENS_CAPP: PICO-D4.6 (SENSOR_CAPP)
SENS_VN: PICO-D4.8 (SENSOR_VN)
SENS_VP: PICO-D4.5 (SENSOR_VP)
STAT: CHRG.1 (STAT), D3.P$2 (2), PICO-D4.10 (IO34)
TXD: IC2.20 (RXD), PICO-D4.41 (U0TXD)
USB: C10.2, C14.1, CHRG.4 (VDD), D4.A, IC2.7 (REGIN), IC2.8 (VBUS), J1.3, R1.1, R8.1, R12.1, T2.1 (G), USB.VBUS
VBAT: C3.1, CHRG.3 (VBAT), J1.1, JST-LIPO.2, R6.1, T2.3 (D)
VBUS: C7.1, D4.C, T2.2 (S), U1.3 (EN), U1.4 (IN)
VDDSDIO: C6.1, LY68L6400SLIT.8 (VCC), PICO-D4.26 (VDD_SDIO_NC)

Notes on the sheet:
USB, POWER PATHS, CHARGING AND FILTERING
LIPO CHARGE
USB TO SERIAL CONVERTER
PICO-D4
10K = 100mA
5.0K = 200mA
2.0K = 500mA
1.0K = 1000mA
PSRAM
DOTSTAR



Board: 4 copper layers, 31.9 x 17.8 mm, 37 parts (3 on the bottom side), 46 nets.

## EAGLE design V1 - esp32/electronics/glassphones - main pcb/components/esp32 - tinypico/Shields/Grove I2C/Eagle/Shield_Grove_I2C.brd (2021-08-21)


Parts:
J1, J3: TINYPICO_HEADER_10NO_SILK_PTH_FEMALE; 1X10_NO_SILK
J2, J4, J5: 4P-2.0; HW4-2.0
J7: CONN_041X04_NO_SILK; 1X04_NO_SILK
LOGO1: OSHW-LOGOS; OSHW-LOGO-S
R1, R2: RESISTOR_0603MP; _0603MP
SJ1, SJ4: SOLDERJUMPERTRACE; SPARKFUN_SJ_2S-TRACE

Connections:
3.3V: J1.4, J2.3, J4.3, J5.3, J7.3, SJ1.1, SJ4.1
GND: J1.2, J2.4, J3.10, J4.4, J5.4, J7.4
GPIO4: J1.5
GPIO5: J3.4
GPIO14: J1.6
GPIO15: J1.7
GPIO18: J3.3
GPIO19: J3.2
GPIO21: J2.2, J3.6, J4.2, J5.2, J7.2, R1.2
GPIO22: J2.1, J3.5, J4.1, J5.1, J7.1, R2.2
GPIO23: J3.1
GPIO25: J1.10
GPIO26: J1.9
GPIO27: J1.8
GPIO32: J3.7
GPIO33: J3.8
RESET: J3.9
SJ1: R2.1, SJ4.2
SJ2: R1.1, SJ1.2
USB: J1.3
VBAT: J1.1


Board: 2 copper layers, 31.9 x 17.8 mm, 11 parts (1 on the bottom side), 6 nets.

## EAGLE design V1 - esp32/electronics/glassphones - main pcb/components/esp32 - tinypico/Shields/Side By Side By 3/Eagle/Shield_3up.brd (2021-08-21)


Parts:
J1, J2, J3, J4, J5, J6: TINYPICO_HEADER_10NO_SILK_PTH_FEMALE; 1X10_NO_SILK
LOGO1: OSHW-LOGOS; OSHW-LOGO-S
U$1: TP_LOGO

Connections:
3.3V: J1.4, J2.4, J5.4
GND: J1.2, J2.2, J3.10, J4.10, J5.2, J6.10
GPIO4: J1.5, J2.5, J5.5
GPIO5: J3.4, J4.4, J6.4
GPIO14: J1.6, J2.6, J5.6
GPIO15: J1.7, J2.7, J5.7
GPIO18: J3.3, J4.3, J6.3
GPIO19: J3.2, J4.2, J6.2
GPIO21: J3.6, J4.6, J6.6
GPIO22: J3.5, J4.5, J6.5
GPIO23: J3.1, J4.1, J6.1
GPIO25: J1.10, J2.10, J5.10
GPIO26: J1.9, J2.9, J5.9
GPIO27: J1.8, J2.8, J5.8
GPIO32: J3.7, J4.7, J6.7
GPIO33: J3.8, J4.8, J6.8
RESET: J3.9, J4.9, J6.9
USB: J1.3, J2.3, J5.3
VBAT: J1.1, J2.1, J5.1


Board: 2 copper layers, 33.1 x 72.4 mm, 8 parts (1 on the bottom side), 19 nets.

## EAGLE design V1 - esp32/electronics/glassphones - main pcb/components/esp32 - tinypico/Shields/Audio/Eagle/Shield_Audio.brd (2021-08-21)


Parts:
C1: 1uF; _0603MP
C2: 10uF; _0603MP
C3: 10nF; _0603MP
C9: 0.1uF; _0603MP
EXT_SPK: CONN_021X02_NO_SILK; 1X02_NO_SILK
IC2: PAM8301; SOT23-6
J1, J3: TINYPICO_HEADER_10NO_SILK_PTH_FEMALE; 1X10_NO_SILK
LOGO1: OSHW-LOGOS; OSHW-LOGO-S
R10: 10K; _0603MP
S1: SPARKFUN-SWITCHES_SWITCH-SPDT-SMD-RIGHT-ANGLE; SPARKFUN-SWITCHES_SWITCH_SPST_SMD_A
SP1: 7.5mm SPK; BUZZER_SMT_7.5MM
VR1: 100k; TRIMPOT-SMD-5MM

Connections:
3.3V: C1.2, C2.2, IC2.5 (VDD), J1.4, R10.2
DAC: C9.2, VR1.A (CCW)
EXT-V-P: EXT_SPK.2, S1.3 (S)
GND: C1.1, C2.1, C3.1, IC2.2 (GND), J1.2, J3.10
GPIO4: IC2.4 (/SD), J1.5, R10.1
GPIO5: J3.4
GPIO14: J1.6
GPIO15: J1.7
GPIO18: J3.3
GPIO19: J3.2
GPIO21: J3.6
GPIO22: J3.5
GPIO23: J3.1
GPIO25: C9.1, J1.10
GPIO26: J1.9
GPIO27: J1.8
GPIO32: J3.7
GPIO33: J3.8
IN: C3.2, IC2.3 (IN), VR1.B (WIPER), VR1.C (CW)
INT-V-P: S1.1 (O), SP1.+
RESET: J3.9
USB: J1.3
VBAT: J1.1
VO-N: EXT_SPK.1, IC2.1 (VO_N), SP1.-
VO-P: IC2.6 (VO_P), S1.2


Board: 2 copper layers, 31.9 x 17.8 mm, 13 parts (1 on the bottom side), 10 nets.

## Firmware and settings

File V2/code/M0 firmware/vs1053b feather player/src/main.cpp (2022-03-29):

// Specifically for use with the Adafruit Feather, the pins are pre-set here!

#include <main.h>


// These are the pins used
#define VS1053_RESET -1 // VS1053 reset pin (not used!)

// Feather ESP8266
#if defined(ESP8266)
#define VS1053_CS 16  // VS1053 chip select pin (output)
#define VS1053_DCS 15 // VS1053 Data/command select pin (output)
#define CARDCS 2      // Card chip select pin
#define VS1053_DREQ 0 // VS1053 Data request, ideally an Interrupt pin

// Feather ESP32
#elif defined(ESP32) && !defined(ARDUINO_ADAFRUIT_FEATHER_ESP32S2)
#define VS1053_CS 32   // VS1053 chip select pin (output)
#define VS1053_DCS 33  // VS1053 Data/command select pin (output)
#define CARDCS 14      // Card chip select pin
#define VS1053_DREQ 15 // VS1053 Data request, ideally an Interrupt pin

// Feather Teensy3
#elif defined(TEENSYDUINO)
#define VS1053_CS 3   // VS1053 chip select pin (output)
#define VS1053_DCS 10 // VS1053 Data/command select pin (output)
#define CARDCS 8      // Card chip select pin
#define VS1053_DREQ 4 // VS1053 Data request, ideally an Interrupt pin

// WICED feather
#elif defined(ARDUINO_STM32_FEATHER)
#define VS1053_CS PC7    // VS1053 chip select pin (output)
#define VS1053_DCS PB4   // VS1053 Data/command select pin (output)
#define CARDCS PC5       // Card chip select pin
#define VS1053_DREQ PA15 // VS1053 Data request, ideally an Interrupt pin

#elif defined(ARDUINO_NRF52832_FEATHER)
#define VS1053_CS 30   // VS1053 chip select pin (output)
#define VS1053_DCS 11  // VS1053 Data/command select pin (output)
#define CARDCS 27      // Card chip select pin
#define VS1053_DREQ 31 // VS1053 Data request, ideally an Interrupt pin

// Feather M4, M0, 328, ESP32S2, nRF52840 or 32u4
#else
#define VS1053_CS 6   // VS1053 chip select pin (output)
#define VS1053_DCS 10 // VS1053 Data/command select pin (output)
#define CARDCS 5      // Card chip select pin
// DREQ should be an Int pin *if possible* (not possible on 32u4)
#define VS1053_DREQ 9 // VS1053 Data request, ideally an Interrupt pin

#endif

    Adafruit_VS1053_FilePlayer musicPlayer =
        Adafruit_VS1053_FilePlayer(VS1053_RESET, VS1053_CS, VS1053_DCS, VS1053_DREQ, CARDCS);

void setup()
{
  Serial.begin(115200);

  // if you're using Bluefruit or LoRa/RFM Feather, disable the radio module
  //pinMode(8, INPUT_PULLUP);

  // Wait for serial port to be opened, remove this line for 'standalone' operation
  while (!Serial)
  {
    delay(1);
  }
  delay(500);
  Serial.println("\n\nAdafruit VS1053 Feather Test");

  if (!musicPlayer.begin())
  { // initialise the music player
    Serial.println(F("Couldn't find VS1053, do you have the right pins defined?"));
    while (1)
      ;
  }

  Serial.println(F("VS1053 found"));

  musicPlayer.sineTest(0x44, 500); // Make a tone to indicate VS1053 is working

  if (!SD.begin(CARDCS))
  {
    Serial.println(F("SD failed, or not present"));
    while (1)
      ; // don't do anything more
  }
  Serial.println("SD OK!");

  // list files
  printDirectory(SD.open("/"), 0);

  // Set volume for left, right channels. lower numbers == louder volume!
  musicPlayer.setVolume(30, 30);

#if defined(__AVR_ATmega32U4__)
  // Timer interrupts are not suggested, better to use DREQ interrupt!
  // but we don't have them on the 32u4 feather...
  musicPlayer.useInterrupt(VS1053_FILEPLAYER_TIMER0_INT); // timer int
#else
  // If DREQ is on an interrupt pin we can do background
  // audio playing
  musicPlayer.useInterrupt(VS1053_FILEPLAYER_PIN_INT); // DREQ int
#endif

  // Play a file in the background, REQUIRES interrupts!
  Serial.println(F("Playing track 001"));
  musicPlayer.startPlayingFile("/track001.mp3");

  // Serial.println(F("Playing track 002"));
  // musicPlayer.startPlayingFile("/track002.mp3");
}

void loop()
{
  Serial.print(".");
  // File is playing in the background
  if (musicPlayer.stopped())
  {
    Serial.println("Done playing music");
    while (1)
    {
      delay(10); // we're done! do nothing...
    }
  }
  if (Serial.available() > 0)
  {
    char c = Serial.read();

    // if we get an 's' on the serial console, stop!
    if (c == 's')
    {
      musicPlayer.stopPlaying();
    }

    // if we get an 'p' on the serial console, pause/unpause!
    if (c == 'p')
    {
      if (!musicPlayer.paused())
      {
        Serial.println("Paused");
        musicPlayer.pausePlaying(true);
      }
      else
      {
        Serial.println("Resumed");
        musicPlayer.pausePlaying(false);
      }
    }

    if (c == 'v')
    {
      int vol = Serial.parseInt();

      musicPlayer.setVolume(vol, vol);
    }
  }
  delay(100);
}

/// File listing helper
void printDirectory(File dir, int numTabs)
{
  while (true)
  {

    File entry = dir.openNextFile();
    if (!entry)
    {
      // no more files
      //Serial.println("**nomorefiles**");
      break;
    }
    for (uint8_t i = 0; i < numTabs; i++)
    {
      Serial.print('\t');
    }
    Serial.print(entry.name());
    if (entry.isDirectory())
    {
      Serial.println("/");
      printDirectory(entry, numTabs + 1);
    }
    else
    {
      // files have sizes, directories do not
      Serial.print("\t\t");
      Serial.println(entry.size(), DEC);
    }
    entry.close();
  }
}

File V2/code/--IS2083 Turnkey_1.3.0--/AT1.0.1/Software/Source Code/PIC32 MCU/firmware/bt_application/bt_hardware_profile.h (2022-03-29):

/******************************************************************************
 Software License Agreement:

 The software supplied herewith by Microchip Technology Incorporated
 (the "Company") for its PICmicro(r) Microcontroller is intended and
 supplied to you, the Company's customer, for use solely and
 exclusively on Microchip PICmicro Microcontroller products. The
 software is owned by the Company and/or its supplier, and is
 protected under applicable copyright laws. All rights are reserved.
 Any use in violation of the foregoing restrictions may subject the
 user to criminal sanctions under applicable laws, as well as to
 civil liability for the breach of the terms and conditions of this
 license.

 THIS SOFTWARE IS PROVIDED IN AN "AS IS" CONDITION. NO WARRANTIES,
 WHETHER EXPRESS, IMPLIED OR STATUTORY, INCLUDING, BUT NOT LIMITED
 TO, IMPLIED WARRANTIES OF MERCHANTABILITY AND FITNESS FOR A
 PARTICULAR PURPOSE APPLY TO THIS SOFTWARE. THE COMPANY SHALL NOT,
 IN ANY CIRCUMSTANCES, BE LIABLE FOR SPECIAL, INCIDENTAL OR
 CONSEQUENTIAL DAMAGES, FOR ANY REASON WHATSOEVER.
********************************************************************/
#ifndef BT_HARDWARE_PROFILE_H
#define BT_HARDWARE_PROFILE_H

#include <xc.h>
#include <stdbool.h>
#include <stdint.h>
#include "system_config.h"
#include "system_definitions.h"

//build option for code included - MBA Support
#define _BLE_ADV_CTRL_BY_MCU
#define _CODE_FOR_APP

//#define _UNSUPPORT_3A_EVENT     //3A event is used to return link mode, it is supported by MSPK but not support by 104 ROM
//#define _SUPPORT_SIMPLE_33_EVENT //33 event is to report multi speaker status. For MSPK, it return connected status with peer address. But for 104 ROM, there is no address, so need to define this macro

//define command size, command buffer size for command in and out
#define     UR_TX_BUF_SIZE              500         //maximum buffer size for command sending
#define     UR_RX_BUF_SIZE              500         //maximum buffer size for command receiving
#define     BT_CMD_SIZE_MAX				200         //maximum size for a single command
#define     QUEQUED_CMD_MAX                 30      //maximum number of command in buffer to be sending 
#define     QUEQUED_ACK_MAX                 30      //maximum number of ack command in buffer to be sending
#define     ACK_TIME_OUT_MS                 800     //number of ms to be waiting for ack
#define     INTERVAL_AFTER_CMD_ACK_NG          10   //interval(ms) before re-transmit this command in case of no ack and ack with error
#define     INTERVAL_AFTER_CMD_ACK_OK          10   //interval(ms) before send next command

//BM6X BT configuration
#define BM6X_MFB_SetHigh()      PLIB_PORTS_PinSet( PORTS_ID_0, PORT_CHANNEL_G, PORTS_BIT_POS_0)
#define BM6X_MFB_SetLow()       PLIB_PORTS_PinClear( PORTS_ID_0, PORT_CHANNEL_G, PORTS_BIT_POS_0)

#define BM6X_RESET_SetHigh()    PLIB_PORTS_PinSet( PORTS_ID_0, PORT_CHANNEL_F, PORTS_BIT_POS_3)
#define BM6X_RESET_SetLow()     PLIB_PORTS_PinClear( PORTS_ID_0, PORT_CHANNEL_F, PORTS_BIT_POS_3)

#ifdef BM83_EVB_VERSION_1_0
#define BT_P3_7_STATUS_GET()      (PLIB_PORTS_PinGet(PORTS_ID_0, PORT_CHANNEL_B, PORTS_BIT_POS_1))

#define LINE_IN_DETECT_STATUS_GET()   (PLIB_PORTS_PinGet(PORTS_ID_0, PORT_CHANNEL_B, PORTS_BIT_POS_0))
#else
#define BT_P3_7_STATUS_GET()      (PLIB_PORTS_PinGet(PORTS_ID_0, PORT_CHANNEL_B, PORTS_BIT_POS_6))

#define LINE_IN_DETECT_STATUS_GET()   (PLIB_PORTS_PinGet(PORTS_ID_0, PORT_CHANNEL_B, PORTS_BIT_POS_7))
#endif

//P2_0
#define BT_P2_0_SetOutput()         //PLIB_PORTS_PinDirectionOutputSet( PORTS_ID_0, PORT_CHANNEL_C, PORTS_BIT_POS_1)
#define BT_P2_0_SetHigh()           //PLIB_PORTS_PinSet( PORTS_ID_0, PORT_CHANNEL_C, PORTS_BIT_POS_1)
#define BT_P2_0_SetLow()            //PLIB_PORTS_PinClear( PORTS_ID_0, PORT_CHANNEL_C, PORTS_BIT_POS_1)

//EAN
#define BT_EAN_SetOutput()          //PLIB_PORTS_PinDirectionOutputSet( PORTS_ID_0, PORT_CHANNEL_C, PORTS_BIT_POS_3)
#define BT_EAN_SetHigh()            //PLIB_PORTS_PinSet( PORTS_ID_0, PORT_CHANNEL_C, PORTS_BIT_POS_3)
#define BT_EAN_SetLow()             //PLIB_PORTS_PinClear( PORTS_ID_0, PORT_CHANNEL_C, PORTS_BIT_POS_3)

//P2_4
#define BT_P2_4_SetOutput()         //PLIB_PORTS_PinDirectionOutputSet( PORTS_ID_0, PORT_CHANNEL_C, PORTS_BIT_POS_2)
#define BT_P2_4_SetHigh()           //PLIB_PORTS_PinSet( PORTS_ID_0, PORT_CHANNEL_C, PORTS_BIT_POS_2)
#define BT_P2_4_SetLow()            //PLIB_PORTS_PinClear( PORTS_ID_0, PORT_CHANNEL_C, PORTS_BIT_POS_2)

//UART RX
#define UART_RX_SetInput()         PLIB_PORTS_PinDirectionInputSet( PORTS_ID_0, PORT_CHANNEL_F, PORTS_BIT_POS_4)
//UART TX
#define UART_UR_TX_SetInput()         PLIB_PORTS_PinDirectionInputSet( PORTS_ID_0, PORT_CHANNEL_F, PORTS_BIT_POS_5)
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

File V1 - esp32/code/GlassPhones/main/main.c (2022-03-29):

//// main file

#include "globals.h"

const static char* TAG = "app main";


void app_main() {

    ESP_LOGI(TAG, "start\n");

    ESP_ERROR_CHECK(nvs_flash_init());
    ESP_LOGI(TAG, "nvs init\n");

    // set MAC address
    uint8_t mac_addr[] =  {0x42, 0x8e, 0x91, 0x59, 0x6c, 0x24};
    esp_base_mac_addr_set(mac_addr);

    // bt init
    ESP_ERROR_CHECK(esp_bt_mem_release(ESP_BT_MODE_BLE));

    static esp_bt_controller_config_t bt_c_cfg = BT_CONTROLLER_INIT_CONFIG_DEFAULT();
    ESP_ERROR_CHECK(esp_bt_controller_init(&bt_c_cfg));

    ESP_ERROR_CHECK(esp_bt_controller_enable(ESP_BT_MODE_CLASSIC_BT));

    ESP_ERROR_CHECK(esp_bluedroid_init());
    ESP_ERROR_CHECK(esp_bluedroid_enable());

    switch (esp_bluedroid_get_status()) {
        case ESP_BLUEDROID_STATUS_ENABLED:{
            ESP_LOGI(TAG, "bluedroid enable confirmed\n");
            break;
        }

        case ESP_BLUEDROID_STATUS_INITIALIZED:{
            ESP_LOGI(TAG, "bluedroid initted but not enabled\n");
            break;
        }

        case ESP_BLUEDROID_STATUS_UNINITIALIZED:{
            ESP_LOGI(TAG, "bluedroid not initted\n");
            break;
        }
    }

    ESP_ERROR_CHECK(esp_bredr_tx_power_set(0, 1));

    esp_power_level_t tx_min = 0;
    esp_power_level_t tx_max = 0;
    esp_bredr_tx_power_get(&tx_min, &tx_max);
    ESP_LOGI("BT", "power level min LVL%i, max LVL%i", (int)tx_min, (int)tx_max);

    // set up class of device info, saying this is an audio device
    esp_bt_cod_t cod;
    esp_bt_gap_get_cod(&cod);
    cod.minor |= 6; // headphones
    cod.major |= ESP_BT_COD_MAJOR_DEV_AV ;
    cod.service |= ESP_BT_COD_SRVC_RENDERING | ESP_BT_COD_SRVC_AUDIO;
    esp_bt_gap_set_cod(cod, ESP_BT_INIT_COD);

    // use gap to find sender's bt_adddress
    esp_bt_gap_register_callback(gap_evt_handler);
    esp_bt_gap_set_scan_mode(ESP_BT_CONNECTABLE, ESP_BT_GENERAL_DISCOVERABLE);

    //start pairing
    ESP_ERROR_CHECK(esp_bt_gap_cancel_discovery());
    ESP_ERROR_CHECK(esp_bt_gap_start_discovery(ESP_BT_INQ_MODE_GENERAL_INQUIRY, 10, 0));
    
    //a2dp setup
    ESP_ERROR_CHECK(esp_a2d_register_callback(&a2d_evt_handler));
    ESP_ERROR_CHECK(esp_a2d_sink_register_data_callback(&a2d_dat_evt_handler));
    ESP_ERROR_CHECK(esp_a2d_sink_init());

    ESP_ERROR_CHECK(esp_a2d_sink_connect(&sender_bt_address));


    max9850e_init();
    max9850e_write_reg(0x02, 0x06);
    #if max9850e_debug
        ESP_LOGI(TAG, "max9850e initted");
    #endif

    // ADF equivalent to all other bluetooth stuffages
    // bluetooth_service_cfg_t service_cfg = {
    //     .device_name = "Glassphones_device",
    //     .remote_name = "Glassphones_remote",
    //     .mode = BLUETOOTH_A2DP_SINK,
    // };
    // bluetooth_service_start(&service_cfg);
    // esp_periph_handle_t periph = bluetooth_service_create_periph();
    // periph_bluetooth_discover(periph);


    // main loop
    while (1){
        // called to keep freertos happy
        vTaskDelay(10);

        serial_read_uart();
    }
}

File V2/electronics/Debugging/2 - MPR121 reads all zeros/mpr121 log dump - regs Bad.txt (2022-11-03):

$0:  0
$1:  0
$2:  0
$3:  0
$4:  0
$5:  0
$6:  0
$7:  0
$8:  0
$9:  0
$A:  0
$B:  0
$C:  0
$D:  0
$E:  0
$F:  0
$10:  0
$11:  0
$12:  0
$13:  0
$14:  0
$15:  0
$16:  0
$17:  0
$18:  0
$19:  0
$1A:  0
$1B:  0
$1C:  0
$1D:  0
$1E:  0
$1F:  0
$20:  0
$21:  0
$22:  0
$23:  0
$24:  0
$25:  0
$26:  0
$27:  0
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

$0:  255
$1:  0
$2:  0
$3:  0
$4:  0
$5:  0
$6:  0
$7:  0
$8:  0
$9:  0
$A:  0
$B:  0
$C:  0
$D:  0
$E:  0
$F:  0
$10:  0
$11:  0
$12:  0
$13:  0
$14:  0
$15:  0
$16:  0
$17:  0
$18:  0
$19:  0
$1A:  0
$1B:  0
$1C:  0
$1D:  0
$1E:  0
$1F:  0
$20:  0
$21:  0
$22:  0
$23:  0
$24:  0
$25:  0
$26:  0
$27:  0
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
cal value for sensor 0: 0
cal value for sensor 1: 0
cal value for sensor 2: 0
cal value for sensor 3: 0
cal value for sensor 4: 0
cal value for sensor 5: 0
cal value for sensor 6: 0
cal value for sensor 7: 0
cal value for sensor 8: 0
cal value for sensor 9: 0
cal value for sensor 10: 0
cal value for sensor 11: 0
calibration successful
0,0,0,0,0,0,0,0,0,0,0,0,

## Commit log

2021-08-21 now builds; woohoo!
    [cmn_crt_authorities.csv, esp32_netsuite.cfg, esp_efuse_table.csv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]
2021-08-22 semi working
    boots, inits, discovers and connects on az delivery esp32 wroom, but fails to discover on tinypico nano esp32 pico d4
    [cmn_crt_authorities.csv, esp32_netsuite.cfg, esp_efuse_table.csv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]
2021-08-23 testing discovery using espidf example
    discovery works on az delivery esp32 WROOM, but not on tinypico nano esp32 pico d4
2021-09-01 experimented with ESP-ADF, but still didn't work
    [partitions.csv, partitions_bt_sink_example.csv, partitions_test_tts_stream.csv]
2022-03-29 LEDs 29 03 22
    [1050170001--3DModel-STEP-56544.step, 21-0140_T28556_MXM.step, Adafruit VS1053 Breakout.brd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]
2022-04-04 i did a stupid, need to go back one sec
    [Adafruit Feather M0 Basic rev C.brd, Adafruit Feather M0 Basic rev C.kicad_pcb, Adafruit Feather M0 Basic rev C.kicad_sch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]
2022-04-04 Revert "i did a stupid, need to go back one sec"
    This reverts commit a6d8b2aea34f96029431820e36dbc3aa056df4ba.
    [Adafruit Feather M0 Basic rev C.brd, Adafruit Feather M0 Basic rev C.kicad_pcb, Adafruit Feather M0 Basic rev C.kicad_sch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]
2022-04-04 fixed it 04 04 2022
    [Adafruit VS1053 Breakout.brd, Adafruit VS1053 Breakout.sch, main.kicad_pcb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]
2022-04-04 main sch layout 04 04 22
    [Adafruit Feather M0 Basic rev C.brd, Adafruit Feather M0 Basic rev C.sch, Adafruit MPR121 Breakout.brd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]
2022-04-05 main sch labelling 05 04 22
    [main.kicad_sch]
2022-04-05 main sch symbols 05 04 22
    [main.kicad_sch]
2022-04-06 main sch assigning footprints 06 04 22
    [Adafruit Feather M0 Basic rev C.kicad_pcb, Adafruit Feather M0 Basic rev C.kicad_sch]
2022-04-07 main sch footprints 07 04 22
    [Adafruit Feather M0 Basic rev C.kicad_sch, Adafruit MPR121 Breakout.kicad_pcb, Adafruit MPR121 Breakout.kicad_sch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]
2022-04-07 main sch audio out tests 07 04 22
    [main.kicad_sch]
2022-04-08 main sch footprints 08 04 22
    [main.kicad_sch]
2022-04-24 pcb design done 24 04 22
    [0.65mm pogo pin v0.step, 4492_ADA.step, Adafruit Feather M0 Basic rev C.kicad_pcb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]
2022-05-08 hardware reference
    designs that reflect the V2 PCBs
    [main.xlsx]
2022-05-23 bring up - mpr121 i2c all zeros
    [mpr121 log dump - regs Bad.txt, mpr121 log dump - regs Good.txt]
2022-08-30 way too many things to keep track of
    theres a serial passthrough programmer that allows the mcu to act as a serial adapter to program the bm83 now
    [Adafruit MPR121Q QT.kicad_pcb, Adafruit MPR121Q QT.kicad_sch, AudioUARTCommandSet_Summary_table_V2.09.xlsx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]
2022-11-02 started main v2, layout and flow
2023-02-14 rearange serial_io into a switch

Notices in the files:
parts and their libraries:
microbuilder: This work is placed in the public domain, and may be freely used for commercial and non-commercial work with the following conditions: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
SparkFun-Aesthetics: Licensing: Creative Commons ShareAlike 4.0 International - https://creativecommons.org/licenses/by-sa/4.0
